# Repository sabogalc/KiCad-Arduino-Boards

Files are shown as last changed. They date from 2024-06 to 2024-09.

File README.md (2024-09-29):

# KiCad Arduino Boards

## Introduction
This repository contains KiCad version 8 design files for eight different Arduino boards that have been recreated from scratch. I was first inspired to work on this project when I received an Arduino Uno R3 for a class project (which you can read [here](https://github.com/sabogalc/KiCad-Arduino-Boards/blob/main/Remote%20Temperature%20Monitoring%20Project.pdf)). Although I had never used an Arduino before, I found it quite useful and versatile. However, I wanted to make some changes to better suit my needs.

## Project Motivation
While working with the Arduino Uno R3, I was frustrated by the need for a USB-B printer cable to use it. Since the Arduino hardware is open source, I decided to recreate the board with a USB-C connector. Additionally, I learned that Arduino boards are not made in KiCad, so I figured this project could also have another benefit in making the designs more open and accessible. Although buying an R4 Minima that already comes with USB-C would have been easier and less expensive, I enjoyed the challenge of re-designing the board myself.

## Design Process
Every Adruino board I could find is made in either EAGLE or Altium, and KiCad has importers for both of these formats. However, importing designs always comes with a level of artifacting and other inaccuracies. The effort to correct the imports would be comparable to remaking the board from scratch, so I opted for the latter since it would produce a cleaner end result. 

Given the popularity and open-source nature of Arduino boards, I assumed that partial or complete KiCad versions might already exist. The following repositories were helpful for getting started:
- [Arduino Uno R3 From Scratch](https://github.com/rheingoldheavy/arduino_uno_r3_from_scratch): Schematic and BOM
- [Arduino Uno KiCad Template](https://github.com/Jeff-Russ/Arduino_Uno_Template): Bare board layout
- [Arduino UNO R3 BOM](https://gist.github.com/yahyatawil/ee6ad731bcf5a5b37dcf2cac04245fbe): BOM only

Even with these resources, I had to find a reset switch footprint myself, but eventually I landed on a compatible one with the TS06-667-30-BK-100-G-SMT-TR by CUI Devices. I now had every piece I needed to make a schematic and PCB, and while doing the PCB layout I would consistently reference the imported design and try to make the component placement and routing as close to the original as possible.

## Visual Comparison
Below is a comparison of the imported UNO R3 board and my completed board, highlighting the differences and benefits in re-making the board from scratch. The most apparent differences are in the silkscreen labeling and the included 3D models of the components:

Comparison Image

## Boards Included
This repository includes designs for:
- Arduino Uno R3
- Arduino Uno R3 SMD
- Arduino Uno R4 Minima
- Arduino Uno R4 WiFi (this one may have some issues; see its folder for details)
- Arduino Leonardo
- Arduino Micro
- Arduino Nano
- Arduino Mega 2560

For details about each board, refer to the `README` file in their respective folders.

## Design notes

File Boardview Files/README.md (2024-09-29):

# Boardview Files

## What is a Boardview File?

A boardview file is a netlist of all the connections on a PCB with every component laid out exactly as it is in real life. This modern approach provides a more intuitive way to inspect connections and troubleshoot PCBs compared to traditional schematic diagrams.

## How Can I View These Files?

Much like how there are many PCB EDA software programs out there, there are also many board viewing programs. The two that I have used and recommend are listed below:

1. **[OpenBoardView](https://github.com/OpenBoardView/OpenBoardView)**  
   - **License:** MIT  
   - **Description:** An open-source tool for viewing boardview files. It provides essential features for inspecting PCB layouts.

2. **[FlexBV](https://pldaniels.com/flexbv/)**  
   - **License:** Commercial (free version available)  
   - **Description:** A commercial tool with advanced features for viewing and analyzing boardview files. The free version offers most of the basic functionalities.

### Example View

Below is a screenshot of the Arduino Mega 2560 boardview as viewed in FlexBV:

Arduino Mega 2560 Boardview

In this view, you can observe the following:
- **Net Highlighting:** The +5V net is highlighted in green across the board.
- **Component Table:** A table on the right lists components and their pin numbers associated with +5V.
- **Designator Information:** The designators, values of resistors and capacitors, and component footprints are all displayed.

### Note on Metadata

The metadata you see (e.g., component values, designators) is stored in the `.obdata` file. As of September 2024, this metadata is viewable only in FlexBV. The `.obdata` format is [open and documented](https://openboarddata.org/), and I would very much like to see the feature added to OpenBoardView.

### How Can I Create Boardview Files for My Own Designs?

All of the boardview files I make for my projects are using [an open-source KiCad plugin](https://github.com/whitequark/kicad-boardview). When I first came across this plugin, it had a few bugs with current versions of KiCad, so I submitted some pull requests and the plugin is back into perfect operating condition. The `.obdata` generation script is currently internal since I made a bit of a mess [submitting that PR](https://github.com/whitequark/kicad-boardview/pull/16), but I am looking to release it eventually.

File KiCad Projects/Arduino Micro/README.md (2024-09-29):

# Micro
Much like the Nano, I made this board in one or two sittings.

This board is not much bigger than the Nano, but it brings benefits such as the full-sized reset switch and four more IO pins.

## KiCad 3D View
Below are the screenshots of this board from KiCad's 3D board viewer.

3D View Front
3D View Back

## Real-World Application
Additionally, I have successfully built this board in real life and confirmed that it works.
Built Board

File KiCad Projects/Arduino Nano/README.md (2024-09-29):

# Nano

## Overview
The Nano is a compact and versatile board that surprisingly handles many of my existing projects designed for the UNO. Its small size makes it a great choice for projects where space is at a premium.

## Design Insights
This was the first board in this repository where I had to use a fully surface-mount USB-C connector instead of a through-hole variant. The original Nano also utilizes a surface-mount USB connector, as a through-hole option would interfere with routing and placement on the bottom layer.

While integrating the larger footprint of the USB-C connector, I had to adjust the silkscreen labels near the connector, but I ensured that all the necessary information remained clear and accessible.

## KiCad 3D View
Below are the screenshots of this board from KiCad's 3D board viewer.

3D View Front
3D View Back

## Real-World Application
Additionally, I have successfully built this board in real life and confirmed that it works.
Built Board

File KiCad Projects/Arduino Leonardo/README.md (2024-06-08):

# Leonardo
This board is very physically similar to the UNO, so it was relatively easy for me to work with the design. I like the versatility it offers with two footprints for the ATMEGA32U4.

The HID automation that this board offers would likely be very useful in setups such as setting up many school or work computers with identical settings, though I'm not sure if my version of the design retained this functionality. I'm used to needing a configuration channel logic IC when working with USB-C host/sub switching, but if anyone who knows more about this has any feedback, please let me know.

Below are the screenshots of this board from KiCad's 3D board viewer.




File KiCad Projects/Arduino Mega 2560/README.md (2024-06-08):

# Mega 2560
I was expecting this to be the most difficult board to make, but it really wasn't all that bad. It did take the longest, but I broke up the design into small sessions across multiple days.

I don't currently have any projects that require the whopping 54 GPIO pins that this board offers, but I saw that it was commonly used in the robotics and 3D printing spaces, and I've also seen it used to read EEPROM data on Ben Eater's YouTube channel.

Below are the screenshots of this board from KiCad's 3D board viewer.




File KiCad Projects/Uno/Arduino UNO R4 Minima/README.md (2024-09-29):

# UNO R4 Minima

## Overview
This board was very straightforward to make, and it is almost 1:1 with the factory one. Even though the UNO R4 already comes with USB-C from Arduino, the OEM footprint is one that exposes the middle plastic receptacle a bit, so I replaced it with one that has the entire port enclosed.

## Design Considerations
While working on this board, I encountered a few challenges:

- **Silkscreen Squares:** The silkscreen square etches on the left side were a bit cumbersome to design.
- **Microcontroller Routing:** Routing beneath the R7FA4M1AB3CFM#AA0 microcontroller was also relatively intricate, as seen below.

R7FA4M1AB3CFM#AA0 Routing

## KiCad 3D View
Below are the screenshots of this board from KiCad's 3D board viewer.
3D View Front
3D View Back

## Real-World Application
I have successfully built this board and confirmed that it works.

Built Board

### Important Note on Soldering
During assembly, I had to solder the buck regulator on 3 separate times since I kept blowing it up. As seen in the [ISL854102 datasheet](https://www.renesas.com/en/document/dst/isl854102-datasheet), its pin configuration is as follows:

- Pin 4: V<sub>in</sub>
- Pin 5: V<sub>out</sub>
- Pin 6: GND

Buck Regulator Pinout

Naturally, shorting any one of these pins to the other can cause a detrimental short, and the 0.5mm pitch makes it easy to do so. Please be careful when soldering the buck regulator!

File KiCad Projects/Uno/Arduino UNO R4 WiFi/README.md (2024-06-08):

# UNO R4 WiFi
I am not the same man I was before making this board.

As soon as I saw the 96 LED array on this board, I knew that I would be in for some work, and of all the boards in this repository, this is the only one that I am not confident would pass a fabricator's specifications. I will highlight the parts of this board that I think may be problematic below.

Firstly, the 3.3V fuse is extremely close to a GND pad on the USB-C port, which could be a possible weak point for a 3.3V short to GND to happen.



Next of course is the placement and routing of the LEDs, especially because lots of these tracks have very little clearance between them.



Some of the curved traces on this board may also be problematic, like in the example below.



All in all, if anyone does actually order the gerbers for this board, please let me know if either all is well or if there are corrections that need to be made.

Below are the screenshots of this board from KiCad's 3D board viewer.




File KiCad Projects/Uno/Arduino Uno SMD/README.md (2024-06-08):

# UNO R3 SMD
This board and its design process are essentially the same as the regular R3.

Below are the screenshots of this board from KiCad's 3D board viewer.




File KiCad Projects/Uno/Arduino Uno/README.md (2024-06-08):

# UNO R3
Because this was the first board I recreated, the design process is already covered in the main `README`. Being that this was the first board I made, it was the one that I was able to get a copy of the earliest, so I have fully verified that this design works, and you can see a photo of the board in real life below.

8e5e6641-f0a8-4247-b638-89c253d5a3a176035296284453338

If you are taking the parts from an OEM UNO like I did, I recommend using low-melt solder to aid in the desoldering of through-hole components. The surface mount components come off easily enough with hot air, but when removing the reset switch or electrolytic capacitors, try to heat them from the bottom of the board to avoid applying too much direct heat.

Below are the screenshots of this board from KiCad's 3D board viewer.




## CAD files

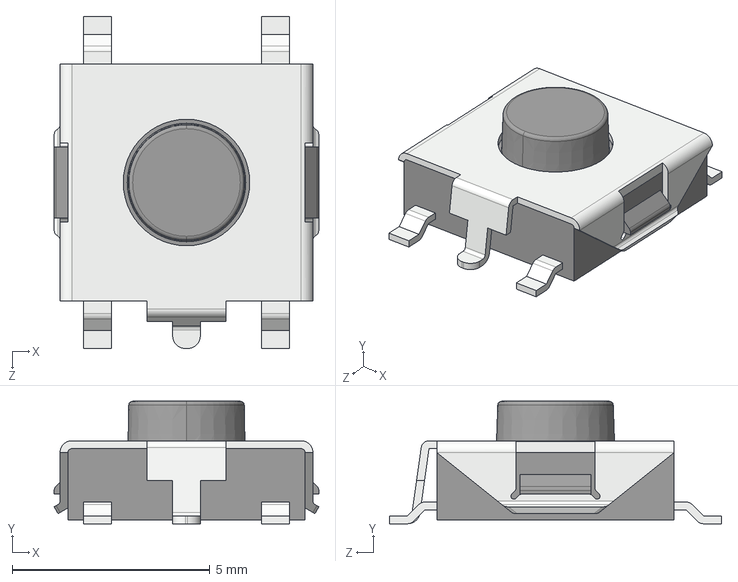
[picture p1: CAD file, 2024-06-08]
KiCad Projects/Arduino Leonardo/STEP Files/CUI_DEVICES_TS06-667-30-BK-100-G-SMT-TR.step
6.70 x 3.10 x 8.40 mm

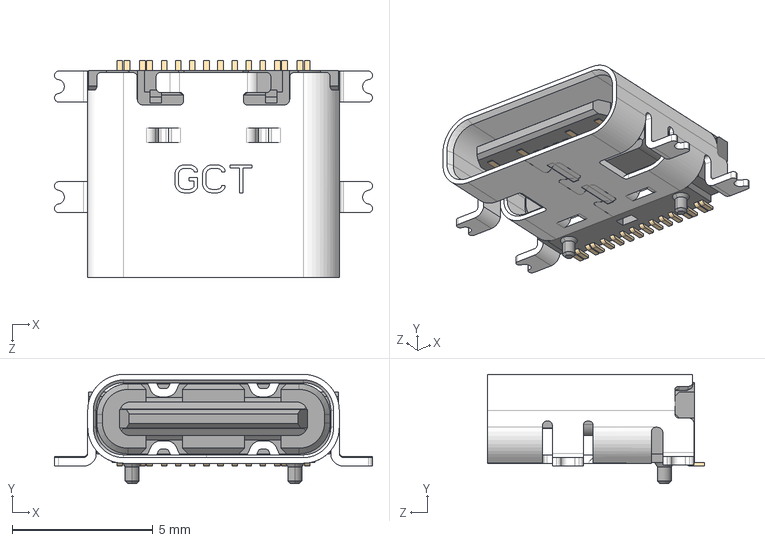
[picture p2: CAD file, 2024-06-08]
KiCad Projects/Arduino Micro/STEP Files/USB4110GFA.step
11.3 x 3.89 x 7.70 mm

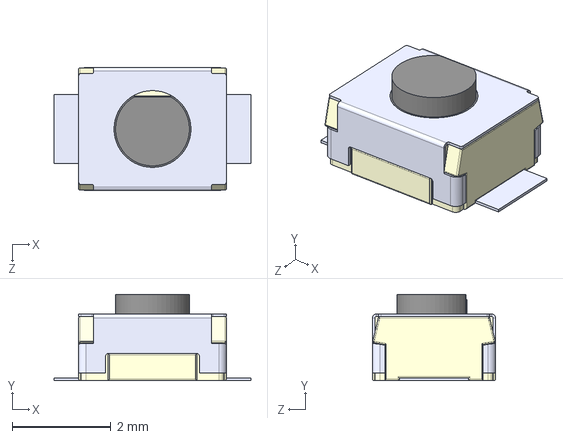
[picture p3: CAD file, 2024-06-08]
KiCad Projects/Arduino Nano/STEP Files/B3U1000PM.step
4.00 x 1.75 x 2.50 mm

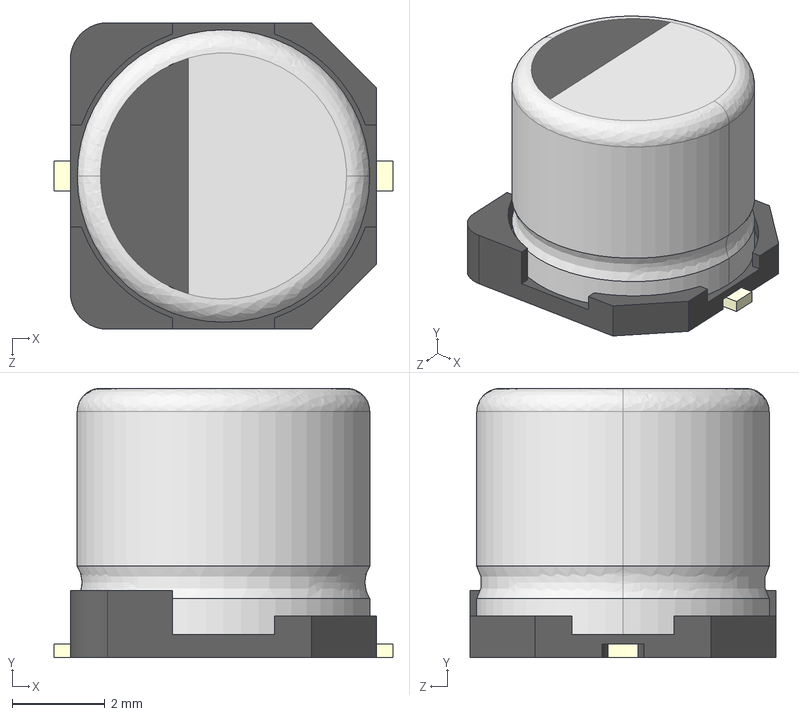
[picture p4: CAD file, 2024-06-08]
KiCad Projects/Uno/Arduino Uno/STEP Files/EEHZA1E470P.step
7.30 x 5.80 x 6.60 mm

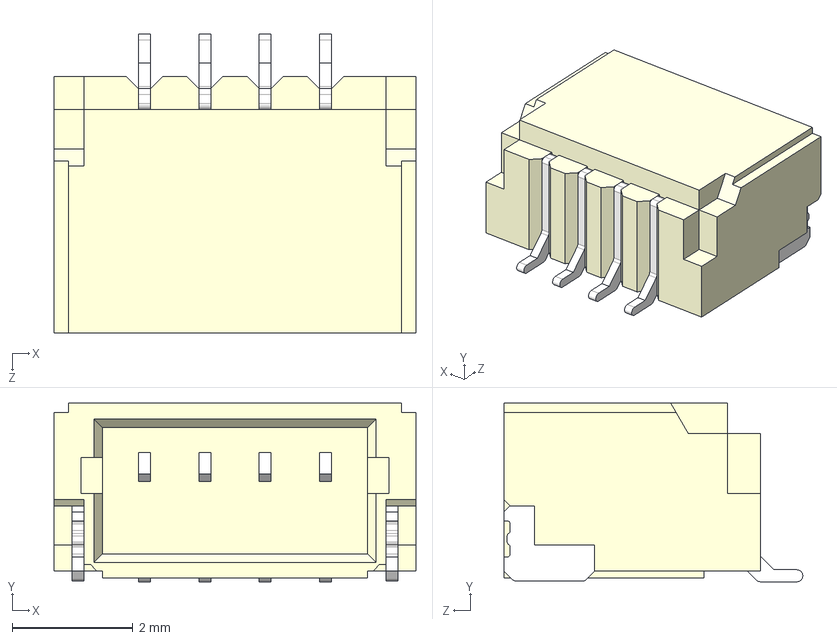
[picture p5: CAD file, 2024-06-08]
KiCad Projects/Uno/Arduino UNO R4 WiFi/STEP Files/SM04B-SRSS-TB.STEP
6.00 x 2.96 x 4.95 mm

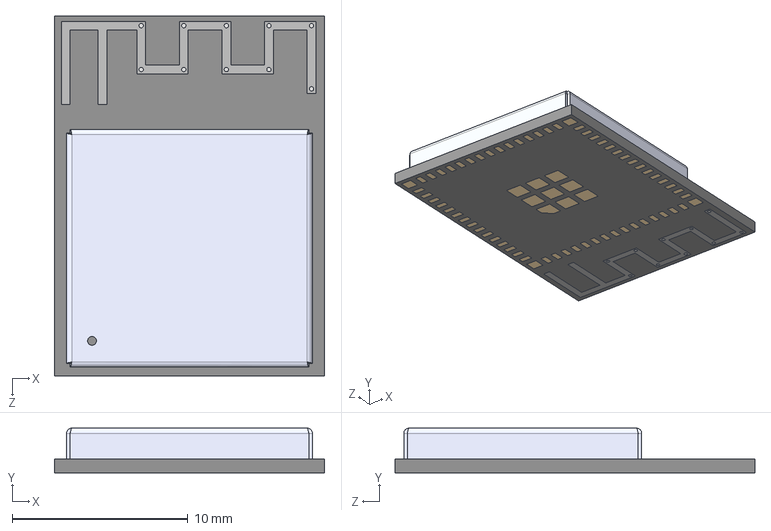
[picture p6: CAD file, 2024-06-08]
KiCad Projects/Uno/Arduino UNO R4 WiFi/STEP Files/ESP32-S3-MINI-1-N8.step
15.4 x 2.55 x 20.5 mm

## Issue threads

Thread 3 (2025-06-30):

USB-B schematic for Arduino Uno

bukowa, 2025-06-30:
Hey is there any source for Uno with  USB-B ?

sabogalc, 2025-07-03:
https://content.arduino.cc/assets/UNO-TH_Rev3e_sch.pdf

Closed 2025-07-03.

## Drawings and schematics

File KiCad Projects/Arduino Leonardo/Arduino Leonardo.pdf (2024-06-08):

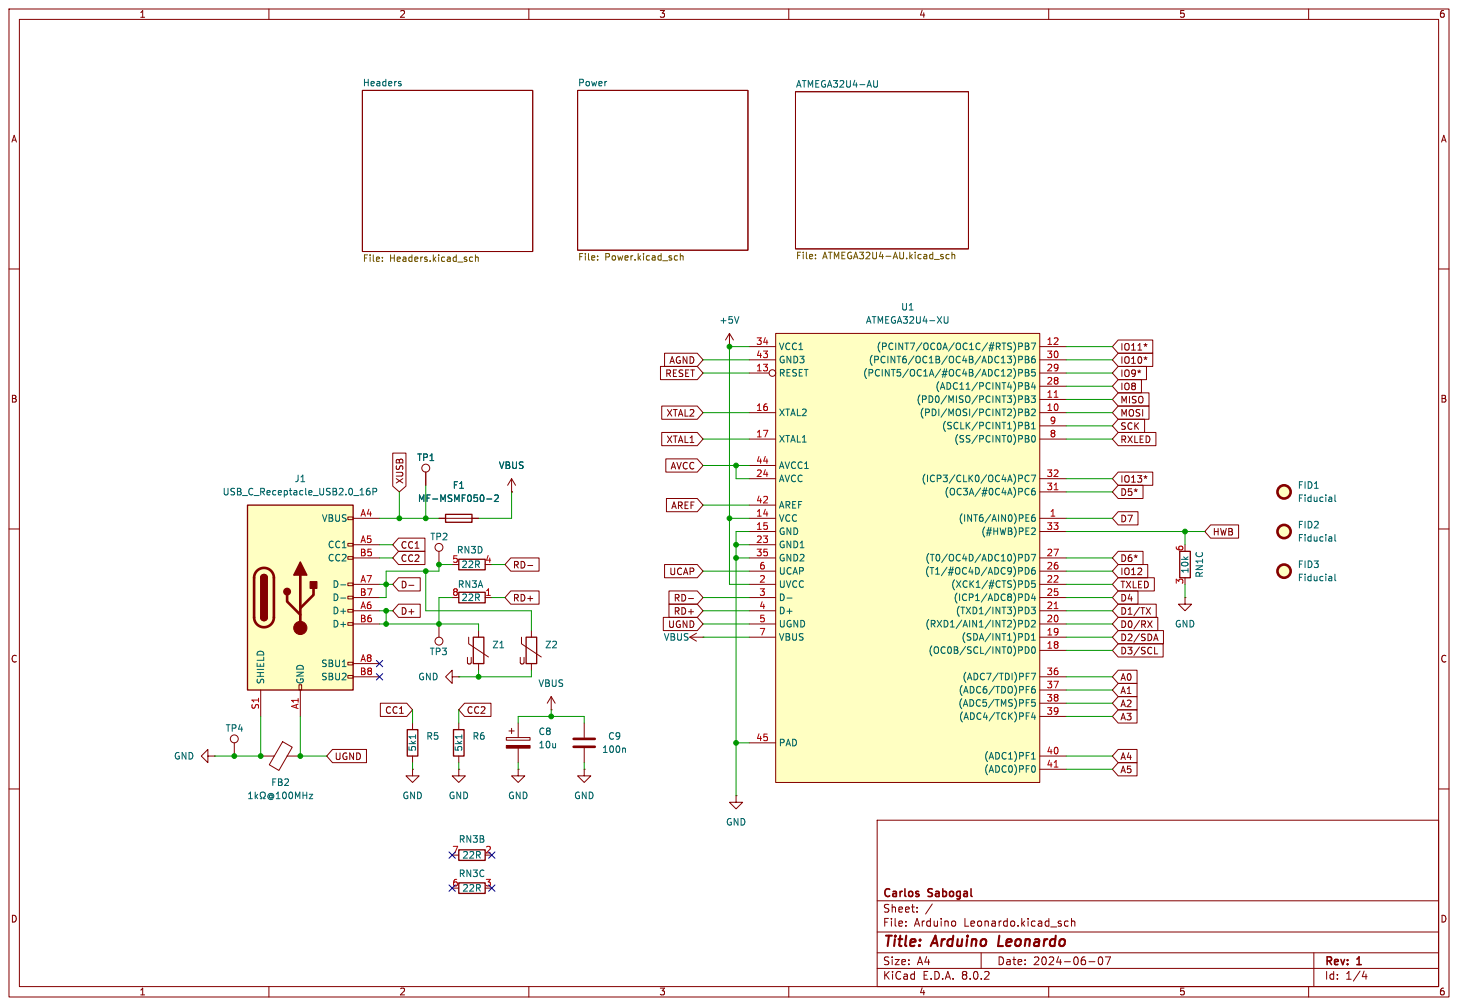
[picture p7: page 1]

D7 D0/RX D2/SDA D3/SCL TXLED

Id: 1/4 Title: Arduino Leonardo

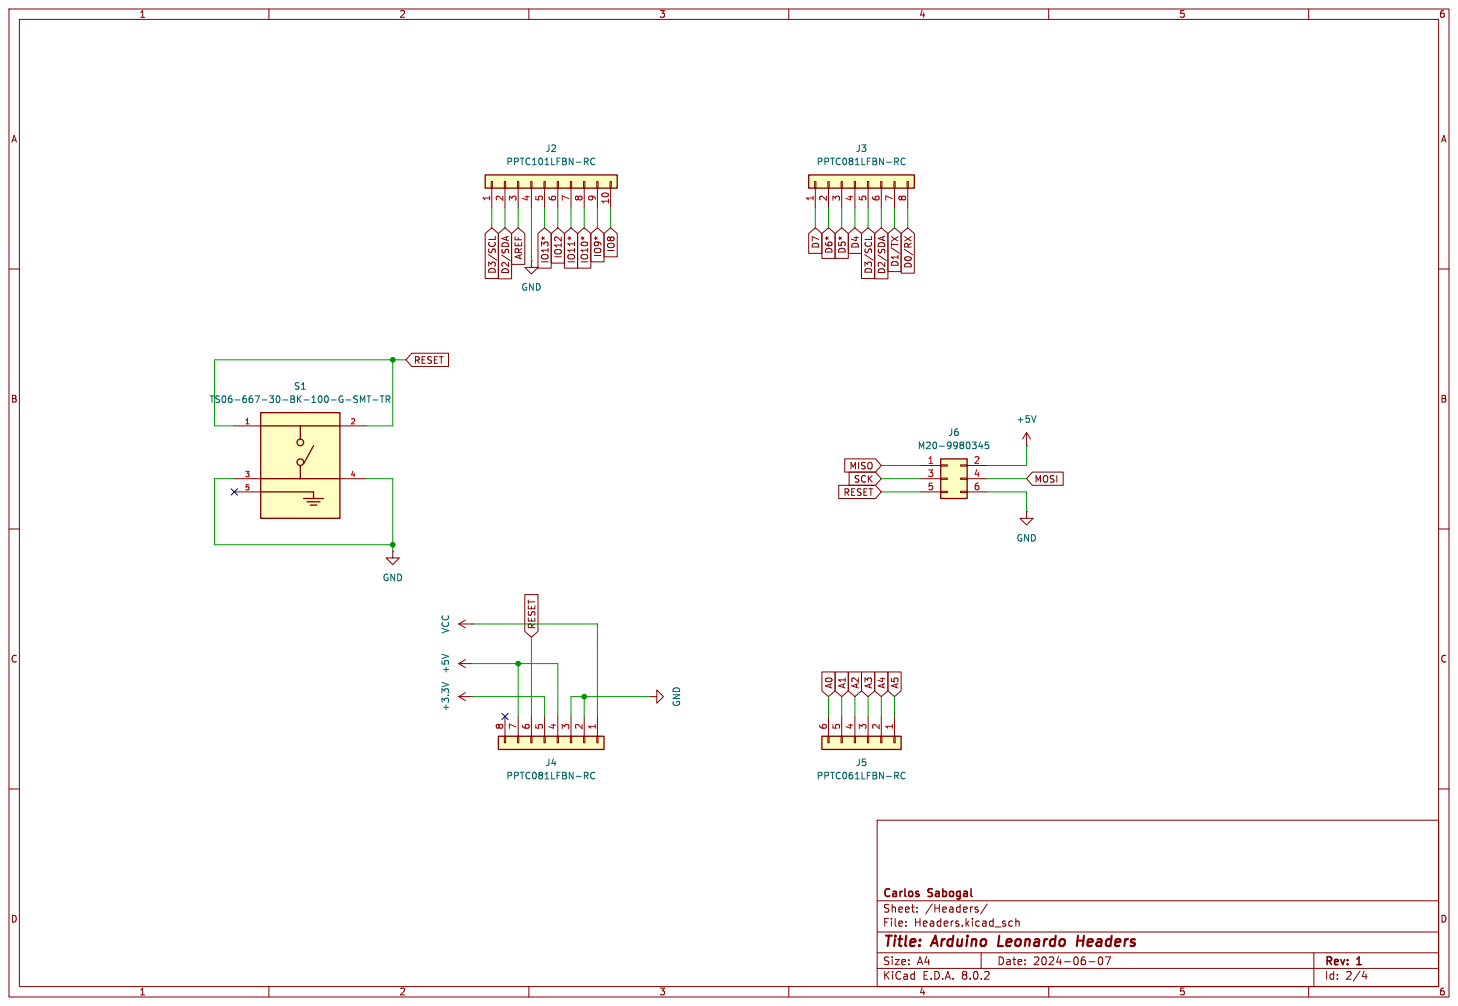
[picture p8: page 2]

File: Headers.kicad_sch Sheet: /Headers/ Carlos Sabogal

Id: 2/4 Title: Arduino Leonardo Headers

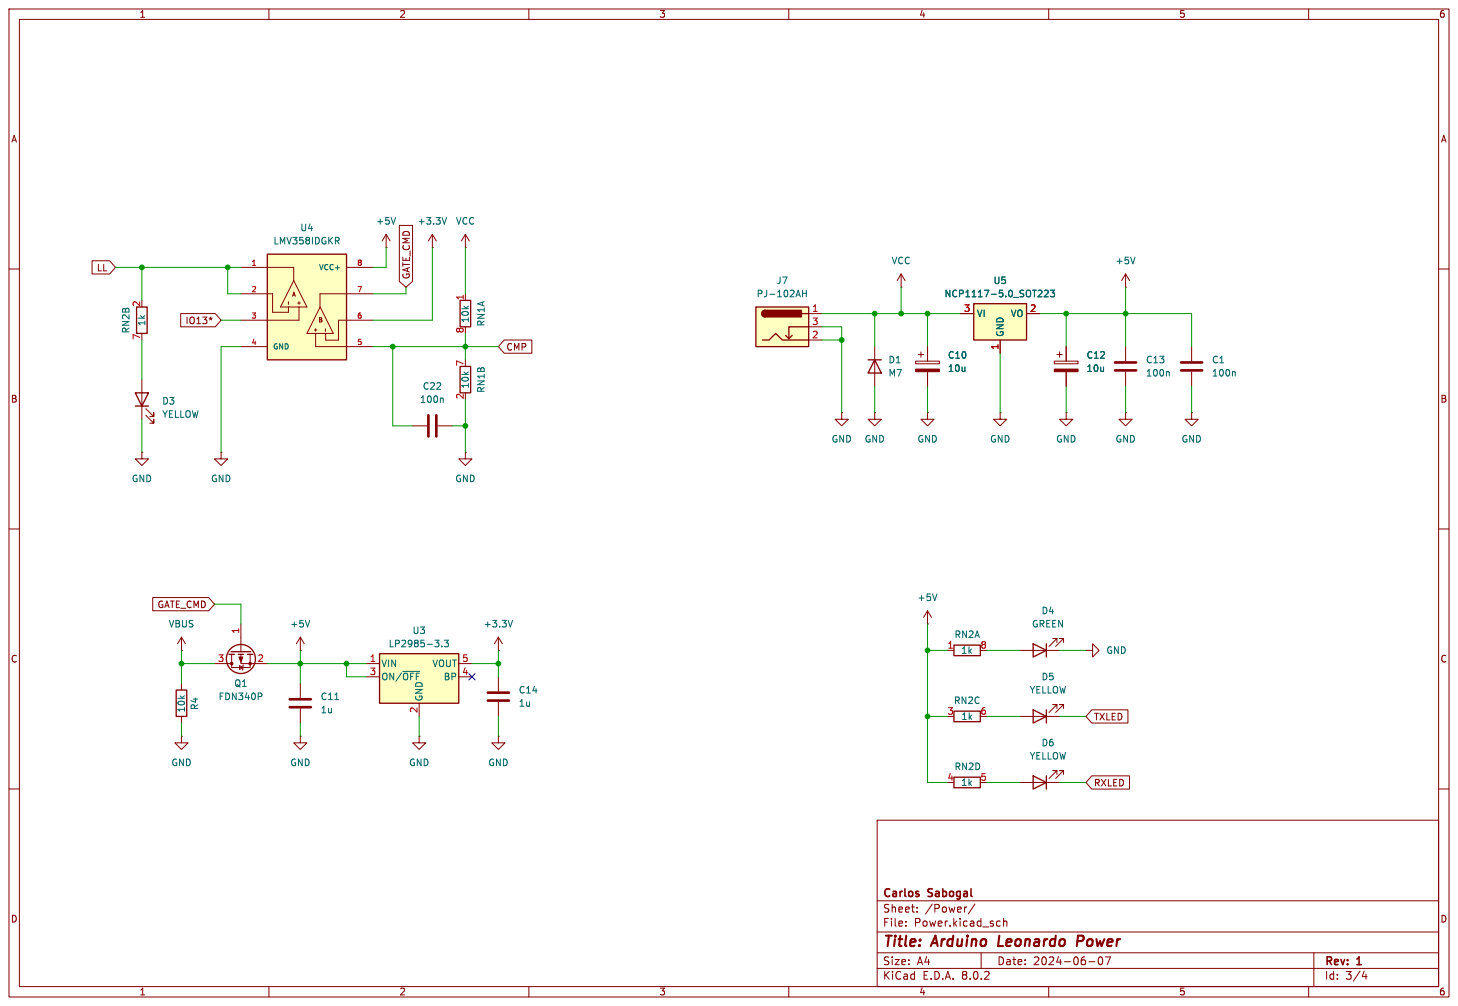
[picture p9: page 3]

2 ON/~{OFF} 3 BP 4 VOUT 5 U3

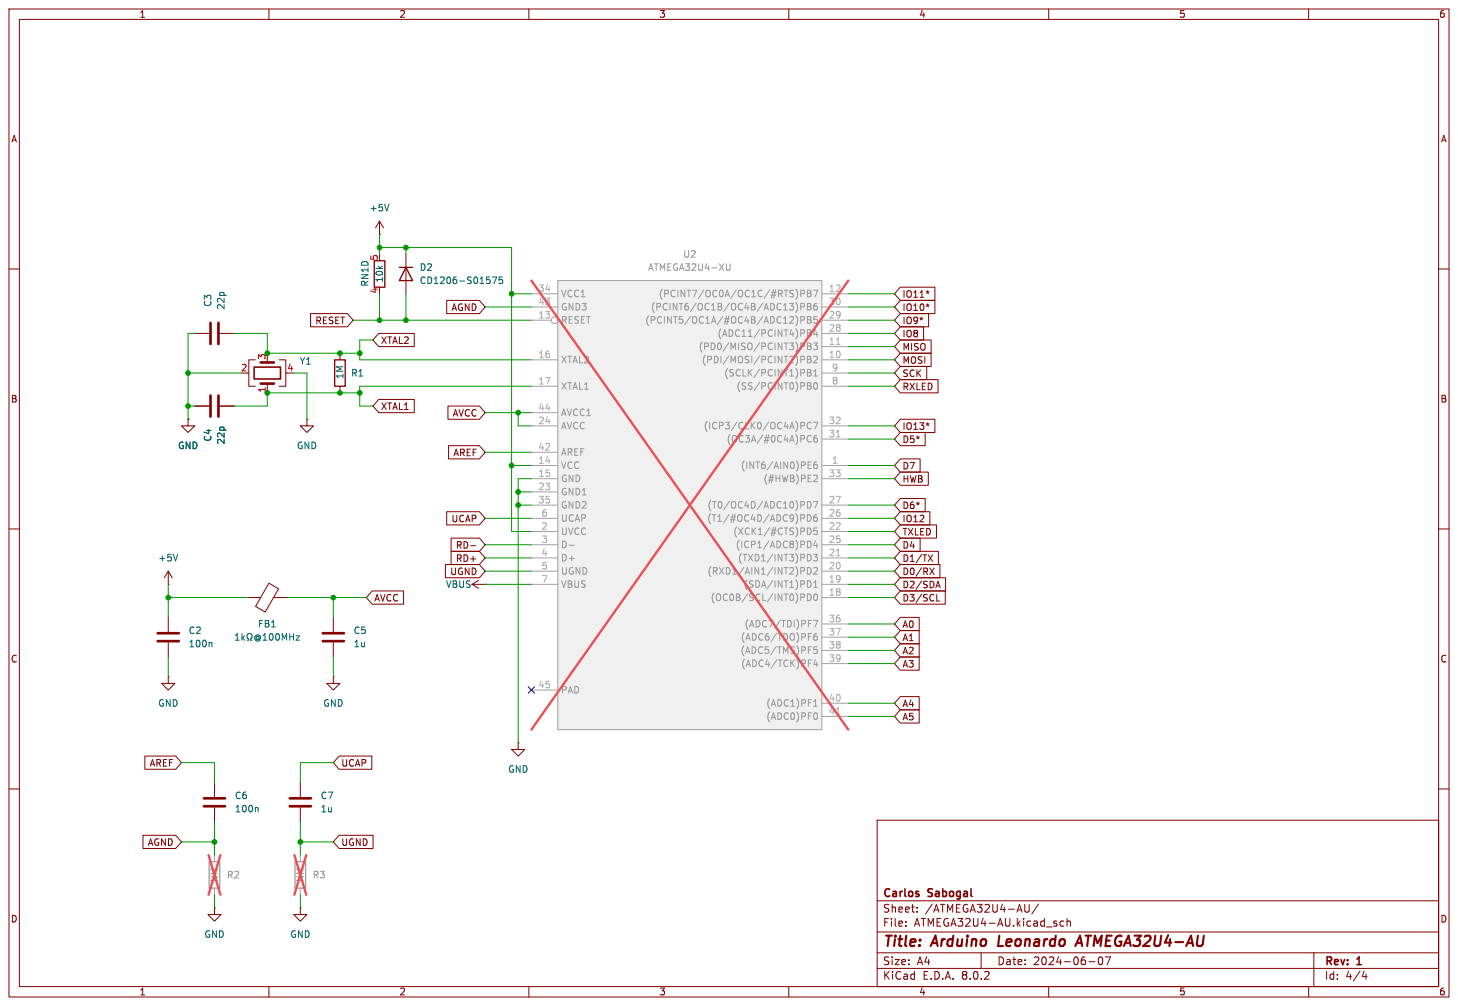
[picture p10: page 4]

File: ATMEGA32U4-AU.kicad_sch Sheet: /ATMEGA32U4-AU/ Carlos Sabogal C2

Id: 4/4 Title: Arduino Leonardo ATMEGA32U4-AU

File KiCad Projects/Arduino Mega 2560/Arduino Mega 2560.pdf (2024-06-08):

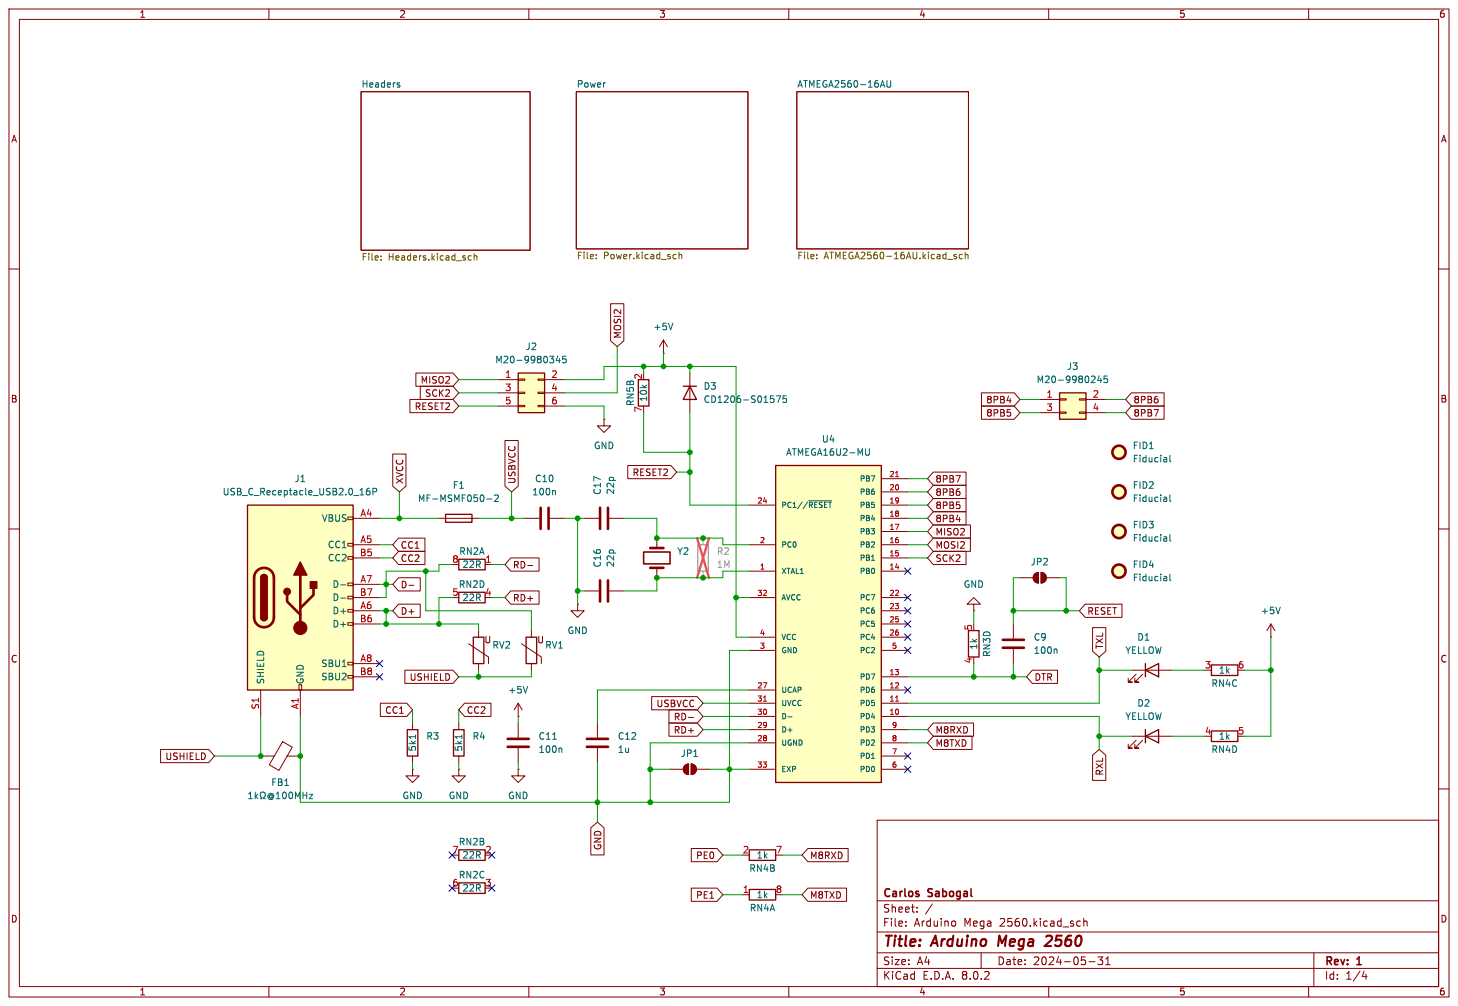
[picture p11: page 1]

Id: 1/4 Title: Arduino Mega 2560

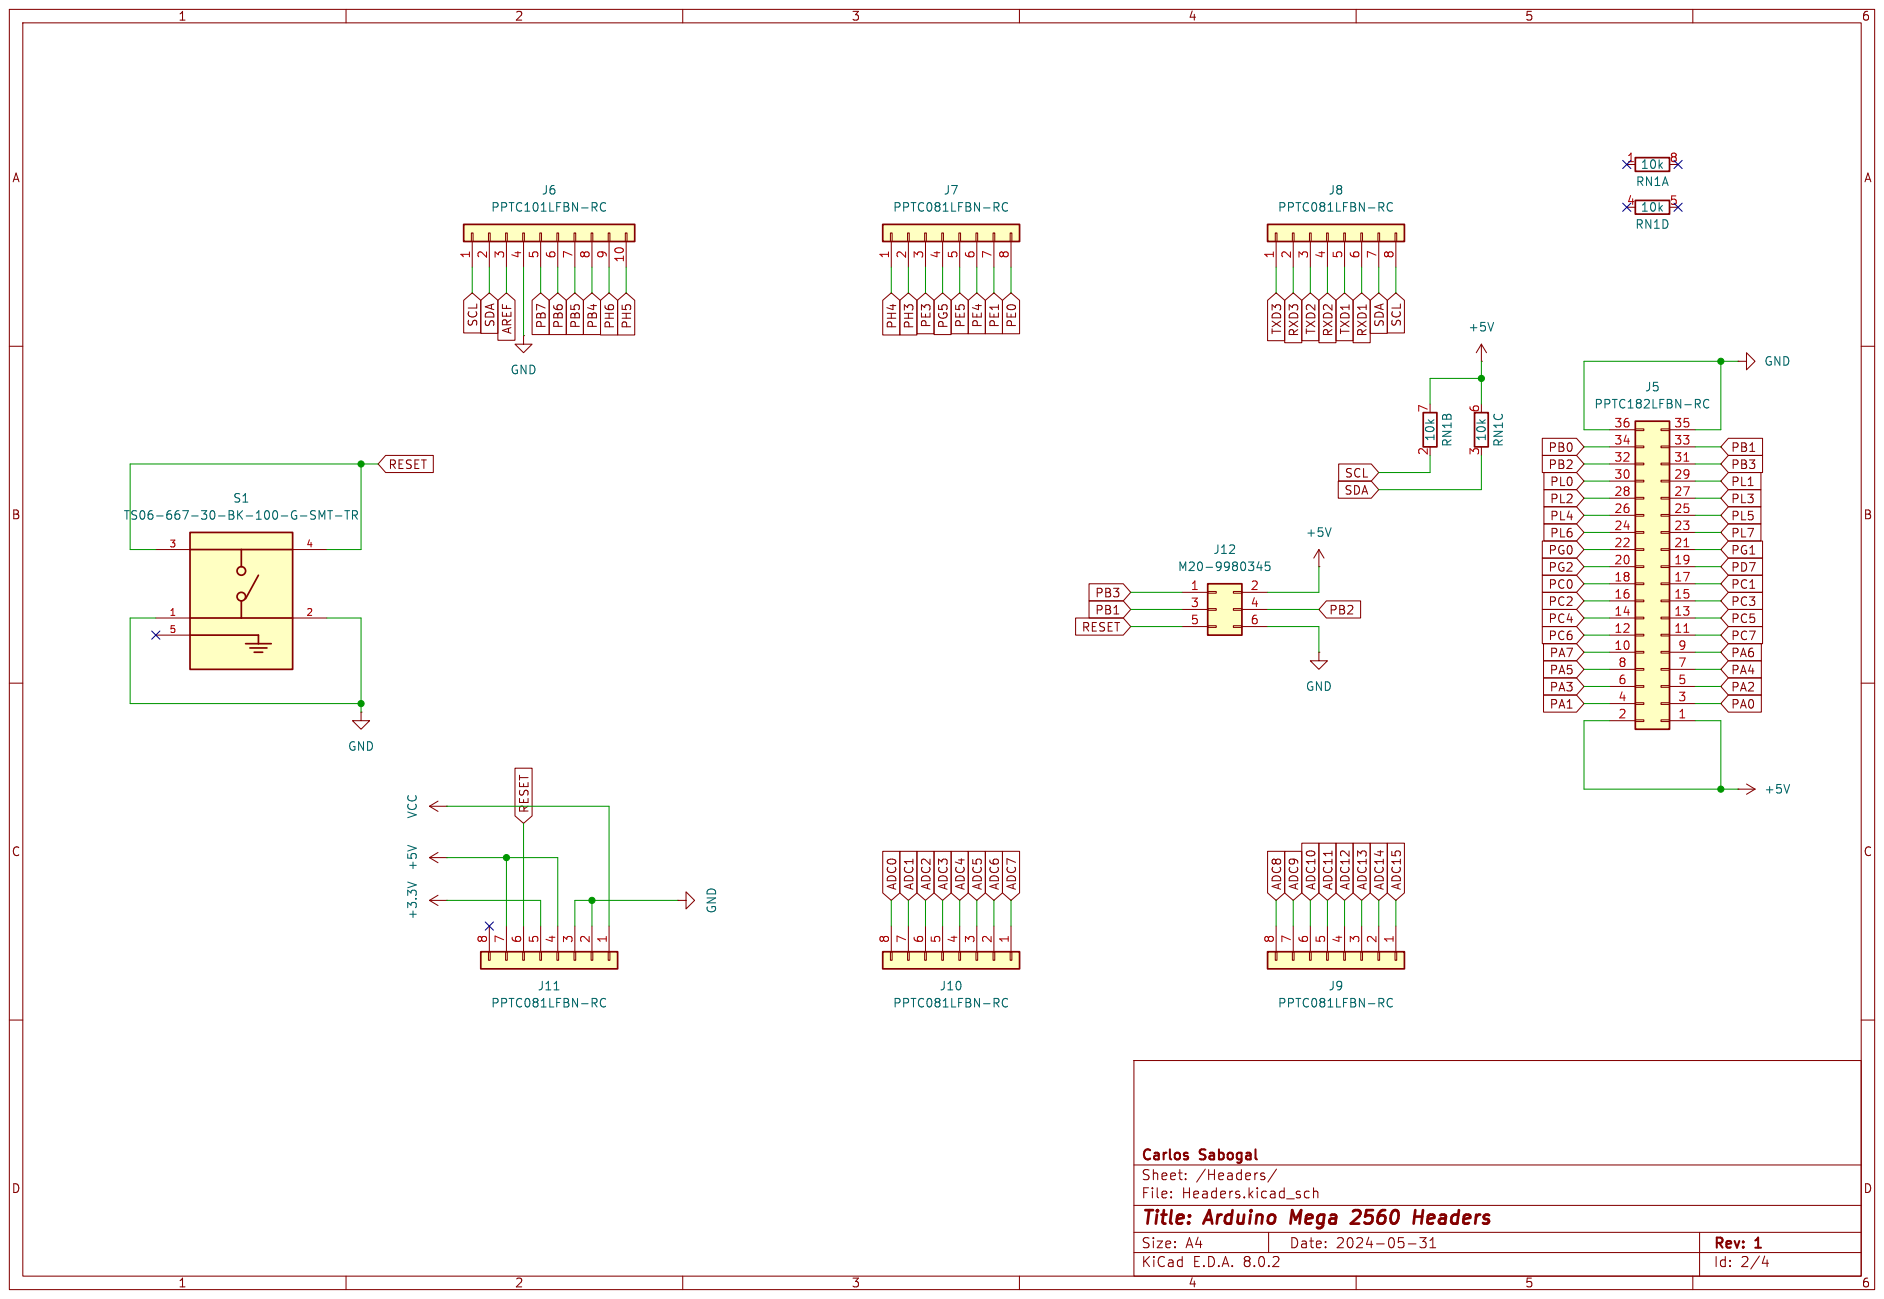
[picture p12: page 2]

File: Headers.kicad_sch Sheet: /Headers/ Carlos Sabogal

Id: 2/4 Title: Arduino Mega 2560 Headers

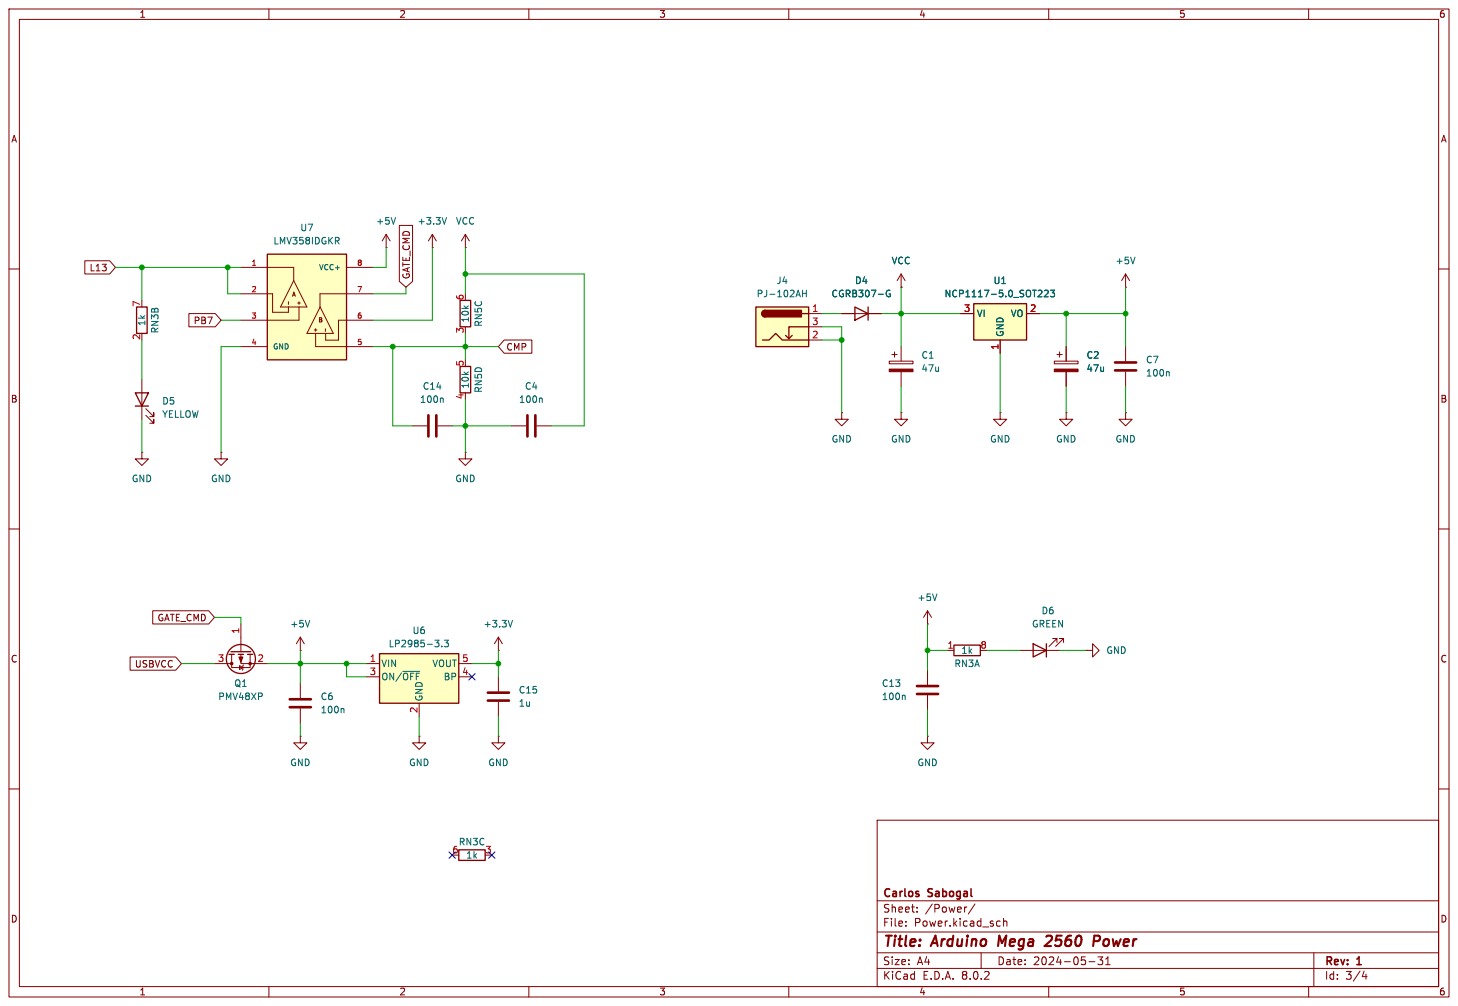
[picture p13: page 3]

1 VO 2 VI 3 U1 NCP1117-5.0_SOT223 GND GND GND GND GND GND

Id: 3/4 Title: Arduino Mega 2560 Power File: Power.kicad_sch Sheet: /Power/ Carlos Sabogal GND

2 ON/~{OFF} 3 BP 4 VOUT 5 U6

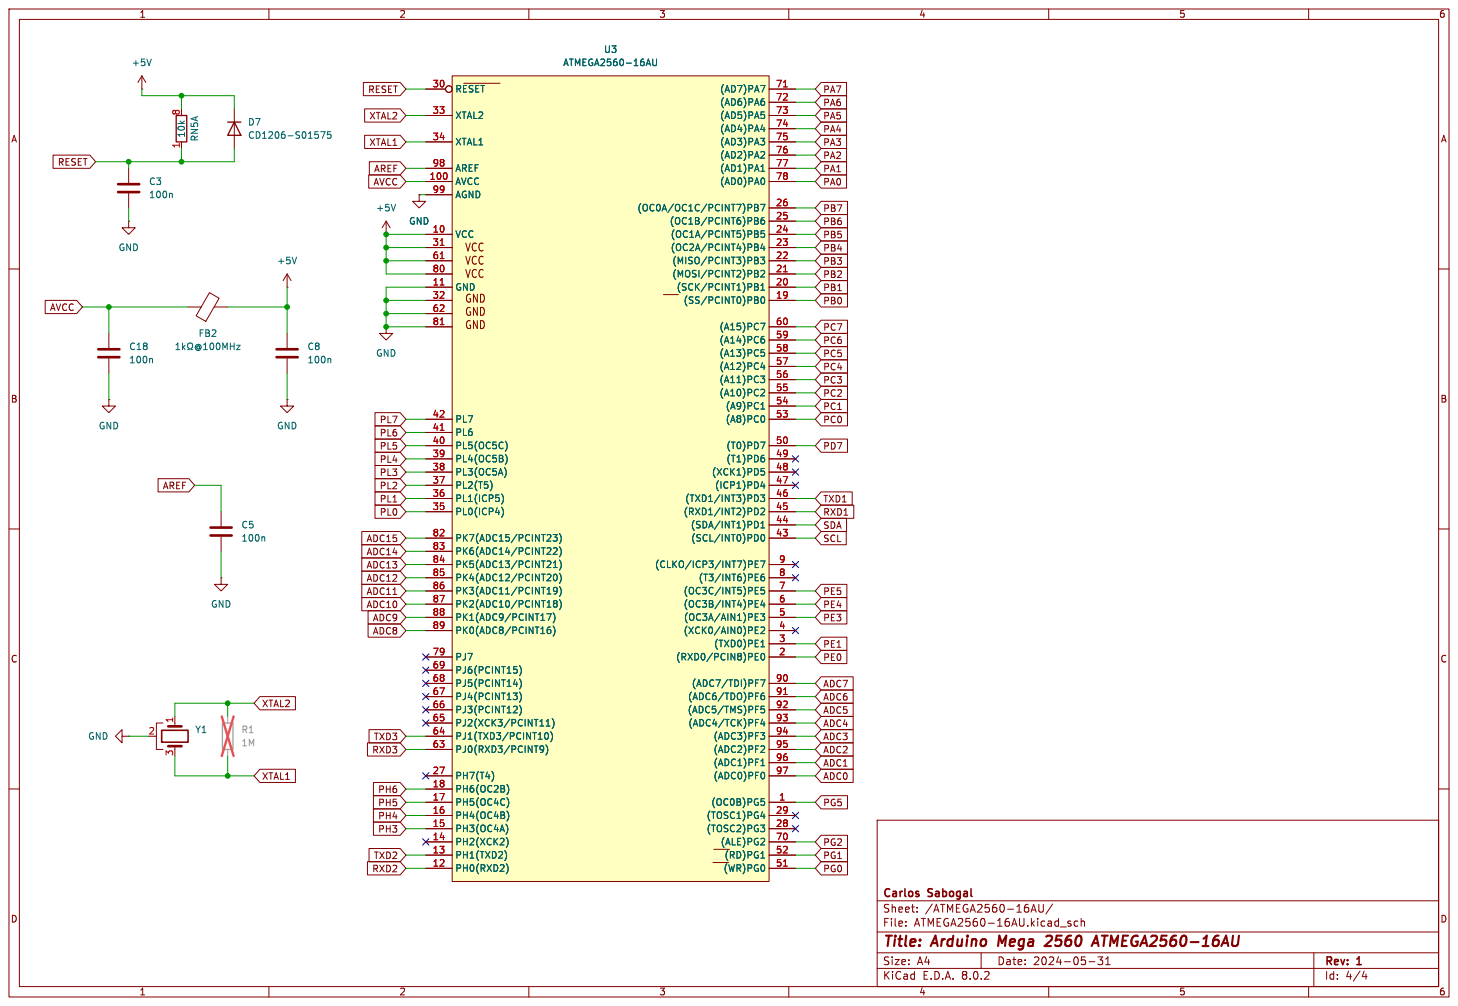
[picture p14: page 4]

File: ATMEGA2560-16AU.kicad_sch Sheet: /ATMEGA2560-16AU/ Carlos Sabogal

Id: 4/4 Title: Arduino Mega 2560 ATMEGA2560-16AU

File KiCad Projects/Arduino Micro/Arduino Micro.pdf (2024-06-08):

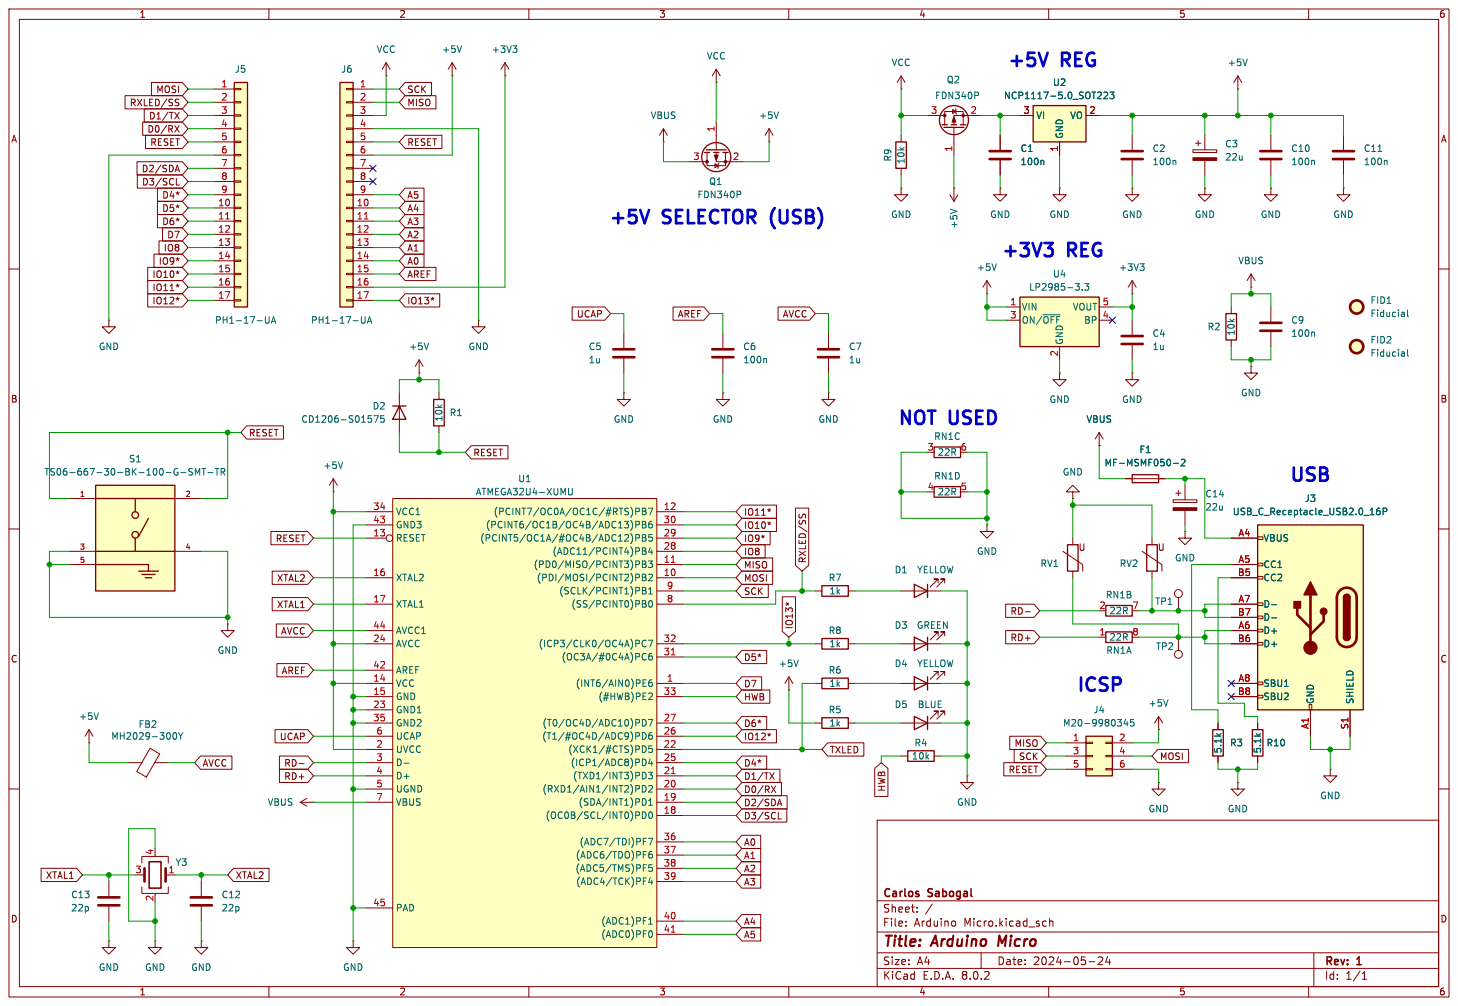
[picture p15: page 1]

2 ON/~{OFF} 3 BP 4 VOUT 5 U4

RESET SCK RD- RD+

IO12* A3A1A5A2A4D6* HWB D3/SCL D2/SDA D0/RX

Id: 1/1 Title: Arduino Micro

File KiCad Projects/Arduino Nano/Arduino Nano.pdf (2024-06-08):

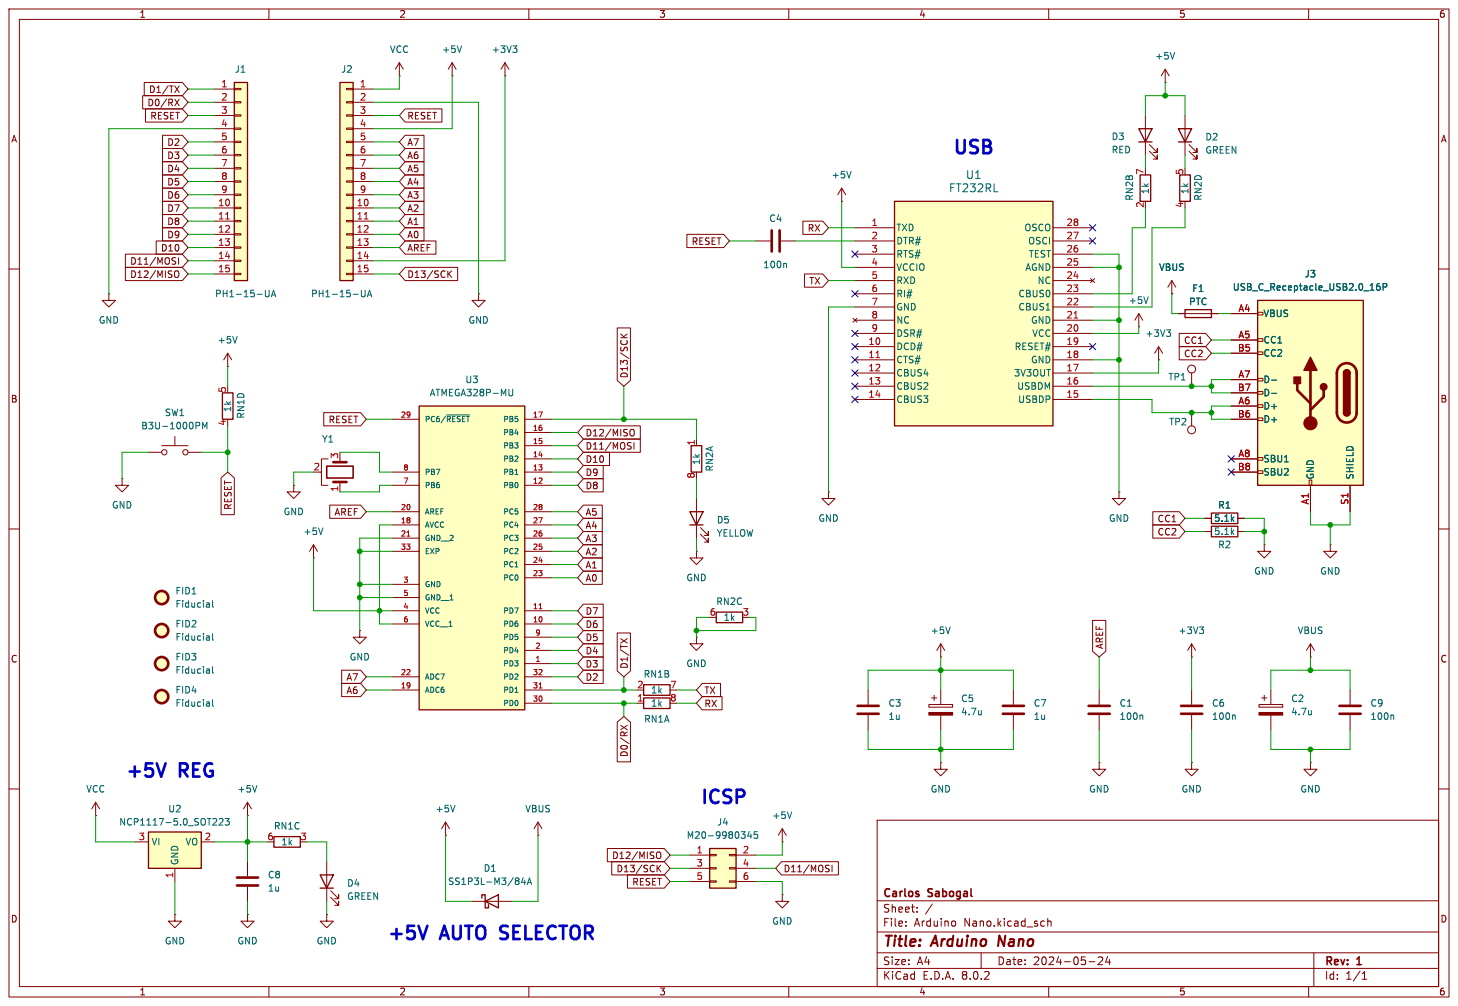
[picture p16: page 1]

Id: 1/1 Title: Arduino Nano

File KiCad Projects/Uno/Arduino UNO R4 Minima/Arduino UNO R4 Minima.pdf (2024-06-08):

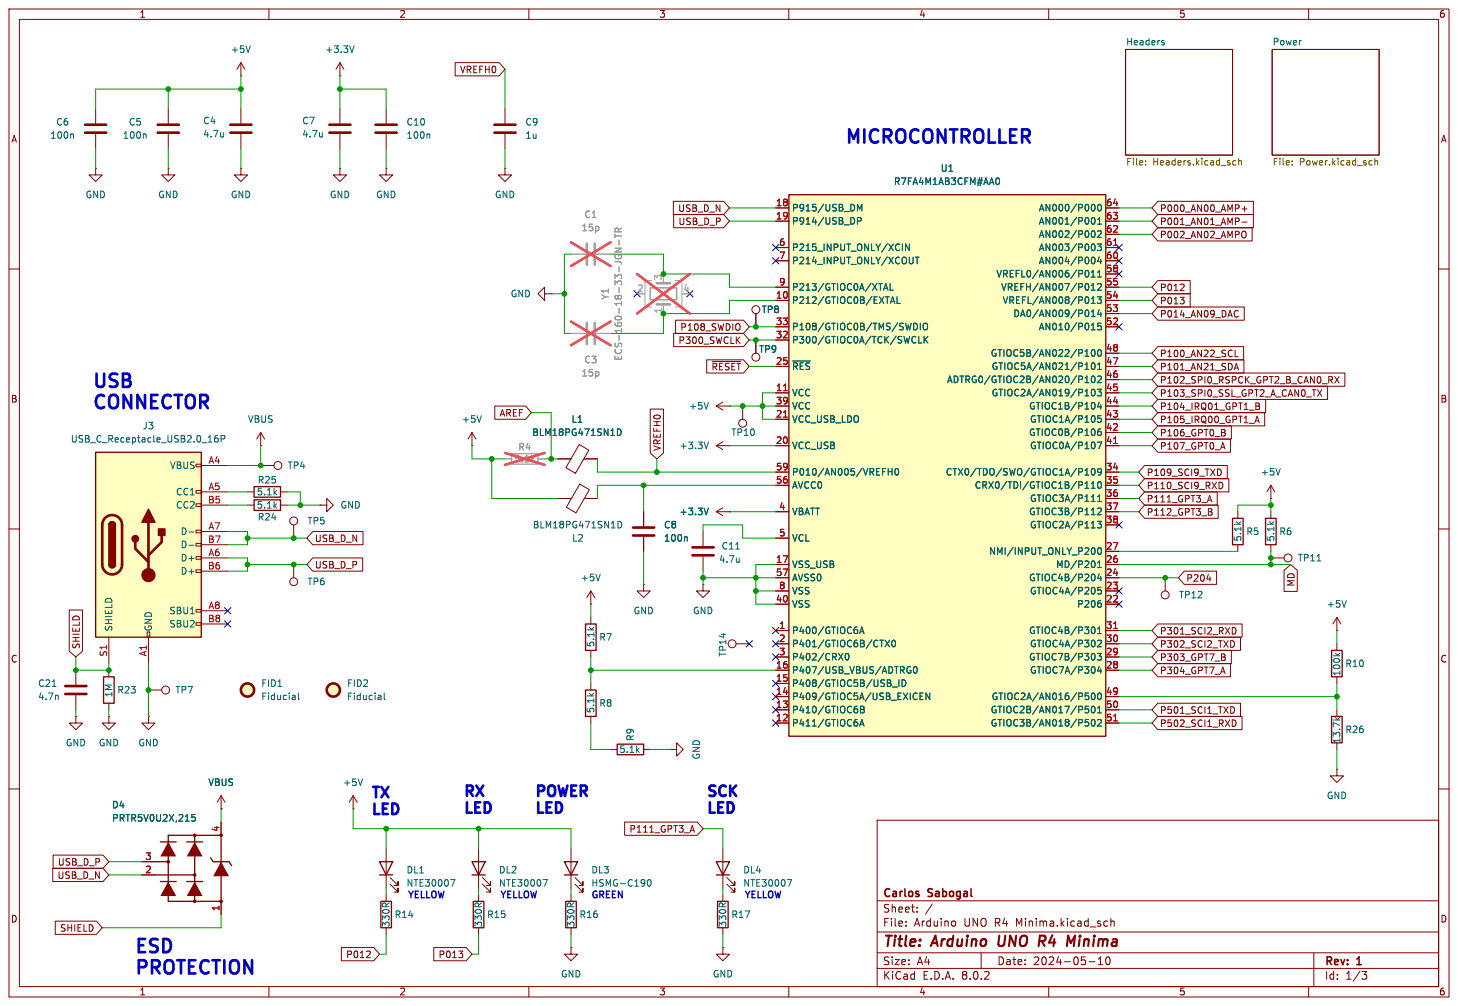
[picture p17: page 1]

Power File: Power.kicad_sch Headers File: Headers.kicad_sch TP12 GND

Id: 1/3 Title: Arduino UNO R4 Minima

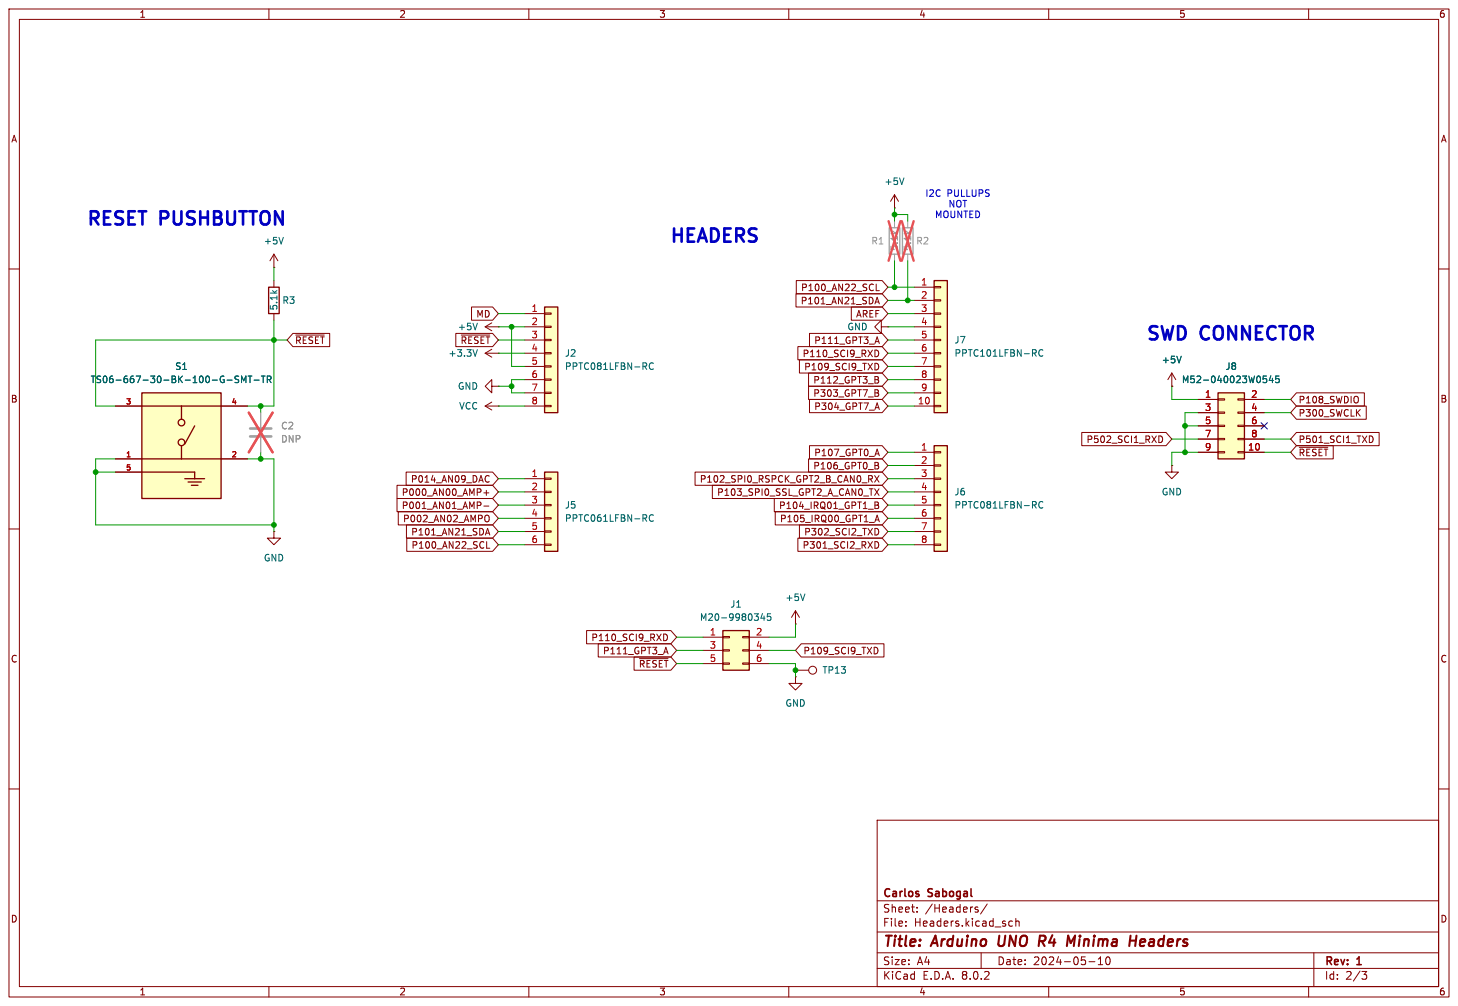
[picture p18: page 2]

I2C PULLUPS NOT MOUNTED HEADERS
P001_AN01_AMP- ~{RESET} MD

File: Headers.kicad_sch Sheet: /Headers/ Carlos Sabogal

Id: 2/3 Title: Arduino UNO R4 Minima Headers


SCHOTTKY FOR USB OVERVOLTAGE

Id: 3/3 Title: Arduino UNO R4 Minima Power File: Power.kicad_sch Sheet: /Power/ Carlos Sabogal

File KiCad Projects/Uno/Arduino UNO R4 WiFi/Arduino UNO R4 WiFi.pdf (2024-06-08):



Id: 2/6 Title: Arduino UNO R4 WiFi Capacitors


File: Headers.kicad_sch Sheet: /Headers/ Carlos Sabogal TP39R11 5.1k +3.3VA

Id: 3/6 Title: Arduino UNO R4 WiFi Headers


Id: 4/6 Title: Arduino UNO R4 WiFi Power File: Power.kicad_sch Sheet: /Power/ Carlos Sabogal


Id: 5/6 Title: Arduino UNO R4 WiFi LED Matrix


(FLOATING) PINSTRAP ROM MESSAGES

PINSTRAP DOWNLOAD
(WEAK PULLUP) PINSTRAP JTAG SOURCE

File: ESP32-S3-MINI-1-N8.kicad_sch Sheet: /ESP32-S3-MINI-1-N8/ Carlos Sabogal

Id: 6/6 Title: Arduino UNO R4 WiFi ESP32-S3-MINI-1-N8

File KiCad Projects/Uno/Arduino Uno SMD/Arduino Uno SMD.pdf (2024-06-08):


Id: 1/4 Title: Arduino Uno SMD (Type-C) File: Arduino Uno SMD.kicad_sch Sheet: / Carlos Sabogal


File: Headers.kicad_sch Sheet: /Headers/ Carlos Sabogal

Id: 2/4 Title: Arduino Uno SMD Headers


Id: 3/4 Title: Arduino Uno SMD Power File: Power.kicad_sch Sheet: /Power/ Carlos Sabogal GND

2 ON/~{OFF} 3 BP 4 VOUT 5 U2


File: ATMEGA328P-MU.kicad_sch Sheet: /ATMEGA328P-MU/ Carlos Sabogal GND GND

Id: 4/4 Title: Arduino Uno SMD ATMEGA328P-MU

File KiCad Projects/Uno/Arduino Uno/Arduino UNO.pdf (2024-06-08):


File: ATMEGA328P-PU.kicad_sch Power File: Power.kicad_sch

Id: 1/4 Title: Arduino UNO (Type-C) File: Arduino UNO.kicad_sch Sheet: / Carlos Sabogal


Id: 2/4 Title: Arduino UNO Headers


1 VO 2 VI 3 U1 NCP1117-5.0_SOT223 GND GND

2 ON/~{OFF} 3 BP 4 VOUT 5 U2

Id: 3/4 Title: Arduino UNO Power File: Power.kicad_sch Sheet: /Power/ Carlos Sabogal


Id: 4/4 Title: Arduino UNO THT ATMEGA328P-PU

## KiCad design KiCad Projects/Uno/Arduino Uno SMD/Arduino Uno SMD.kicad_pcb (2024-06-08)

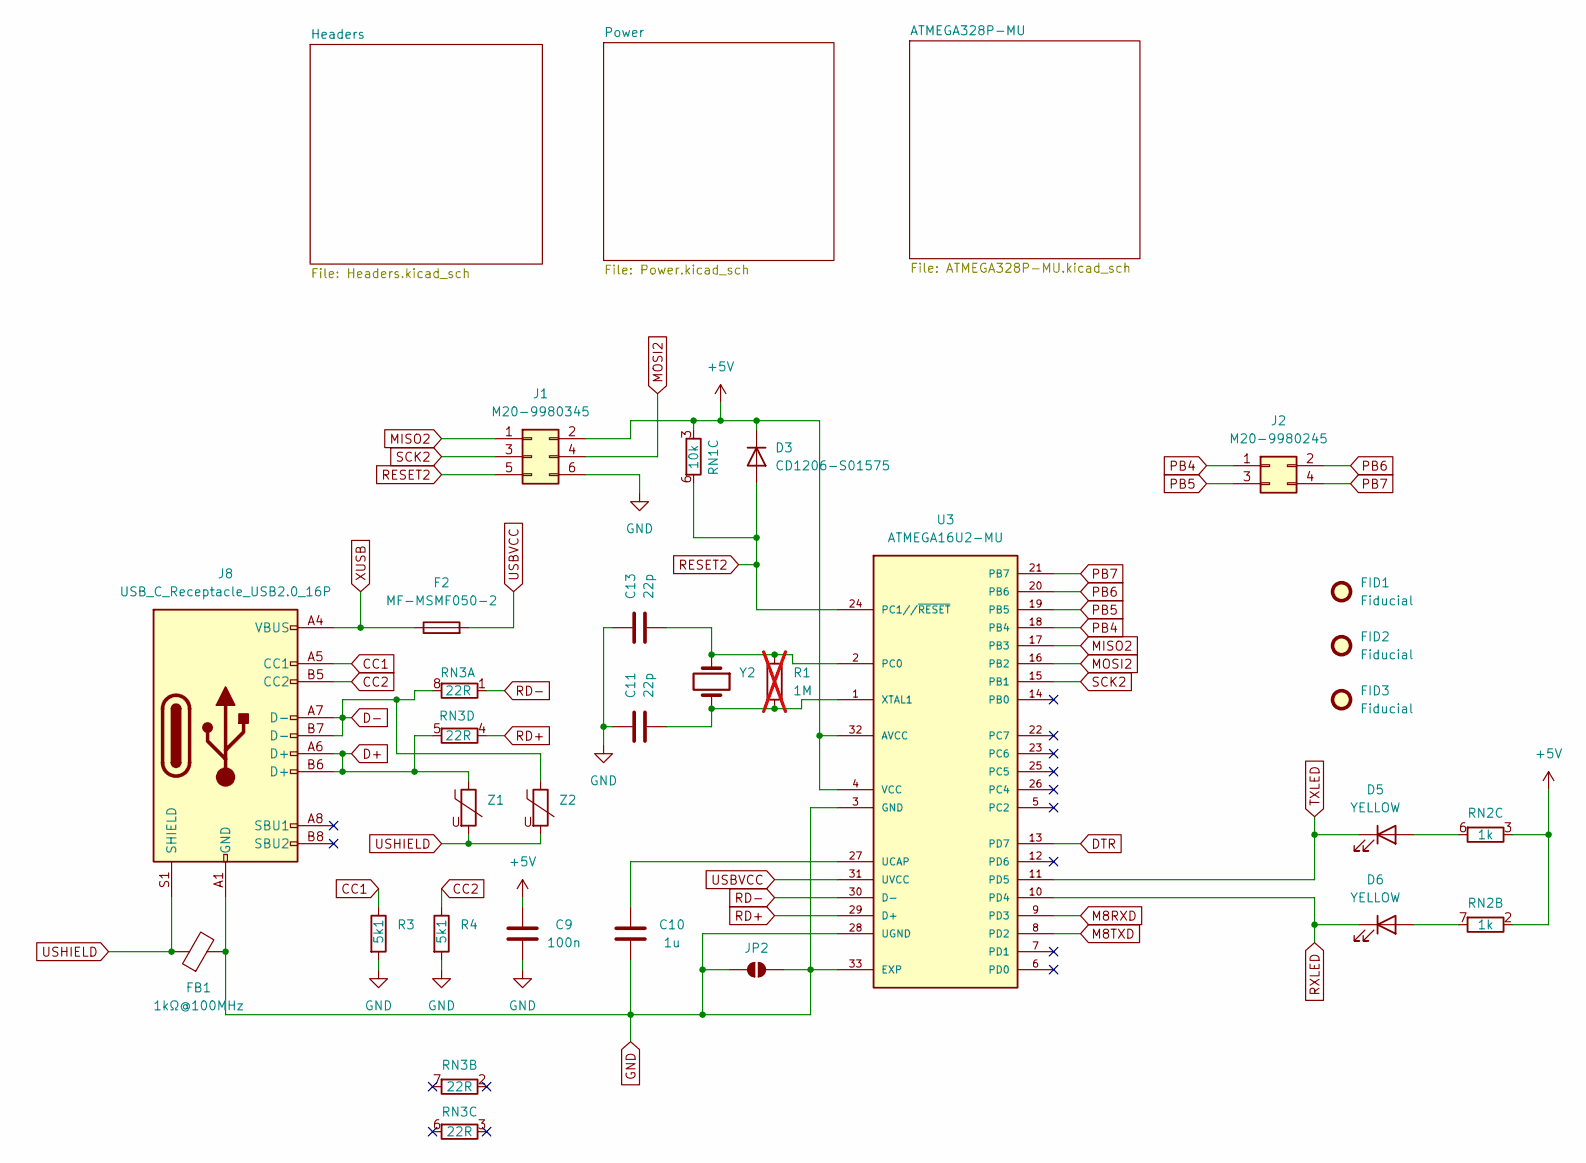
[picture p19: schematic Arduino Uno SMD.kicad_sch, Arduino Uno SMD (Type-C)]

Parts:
C9: 100n; C_0603_1608Metric
C10: 1u; C_0603_1608Metric
C11, C13: 22p; C_0603_1608Metric
D3: CD1206-S01575; D_1206_3216Metric
D5, D6: YELLOW; LED_0805_2012Metric
F2: MF-MSMF050-2; Fuse_1812_4532Metric_Pad1.30x3.40mm_HandSolder
FB1: 1kΩ@100MHz; L_0805_2012Metric
FID1, FID2, FID3: Fiducial; Fiducial_1mm_Mask2mm
J1: M20-9980345; PinHeader_2x03_P2.54mm_Vertical
J2: M20-9980245; CONN_M20-9980245_HRW
J8: USB_C_Receptacle_USB2.0_16P; USB_C_Receptacle_GCT_USB4105-xx-A_16P_TopMnt_Horizontal
JP2: SolderJumper_2_Open; SolderJumper-2_P1.3mm_Open_Pad1.0x1.5mm
R1: 1M; R_0603_1608Metric; not fitted
R3, R4: 5k1; R_0603_1608Metric
RN1: 10k; R_Array_Convex_4x0603
RN2: 1k; R_Array_Convex_4x0603
RN3: 22R; R_Array_Convex_4x0603
U3: ATMEGA16U2-MU; VQFN-32-1EP_5x5mm_P0.5mm_EP3.1x3.1mm
Y2: LFXTAL003240BULK; Crystal_HC49-4H_Vertical
Z1, Z2: 5pF@1MHz; R_0603_1608Metric

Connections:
+5V: C9.1, D3.1 (K), J1.2, RN1.3 (R3.1), RN2.2 (R2.1), RN2.3 (R3.1), U3.4 (VCC), U3.32 (AVCC); also elsewhere on the board
CC1: J8.A5 (CC1), R3.1
CC2: J8.B5 (CC2), R4.1
D+: J8.A6 (D+), J8.B6 (D+), RN3.5 (R4.2), Z1.1
D-: J8.A7 (D-), J8.B7 (D-), RN3.8 (R1.2), Z2.1
DTR: U3.13 (PD7); also elsewhere on the board
GND: C9.2, C10.1, C11.2, C13.2, FB1.2, J1.6, J8.A1 (GND), J8.A12 (GND), J8.B1 (GND), J8.B12 (GND), JP2.1 (A), JP2.2 (B), R3.2, R4.2, U3.3 (GND), U3.28 (UGND), U3.33 (EXP); also elsewhere on the board
M8RXD: U3.9 (PD3); also elsewhere on the board
M8TXD: U3.8 (PD2); also elsewhere on the board
MISO2: J1.1, U3.17 (PB3)
MOSI2: J1.4, U3.16 (PB2)
unnamed: D5.2 (A), RN2.6 (R3.2)
unnamed: D6.2 (A), RN2.7 (R2.2)
unnamed: C13.1, R1.1, U3.2 (PC0), Y2.1
unnamed: C10.2, U3.27 (UCAP)
unnamed: C11.1, R1.2, U3.1 (XTAL1), Y2.2
PB4: J2.1, U3.18 (PB4)
PB5: J2.3, U3.19 (PB5)
PB6: J2.2, U3.20 (PB6)
PB7: J2.4, U3.21 (PB7)
RD+: RN3.4 (R4.1), U3.29 (D+)
RD-: RN3.1 (R1.1), U3.30 (D-)
RESET2: D3.2 (A), J1.5, RN1.6 (R3.2), U3.24 (PC1//~RESET)
RXLED: D6.1 (K), U3.10 (PD4)
SCK2: J1.3, U3.15 (PB1)
TXLED: D5.1 (K), U3.11 (PD5)
USBVCC: F2.2, U3.31 (UVCC); also elsewhere on the board
USHIELD: FB1.1, J8.S1 (SHIELD), Z1.2, Z2.2
XUSB: F2.1, J8.A4 (VBUS), J8.A9 (VBUS), J8.B4 (VBUS), J8.B9 (VBUS)

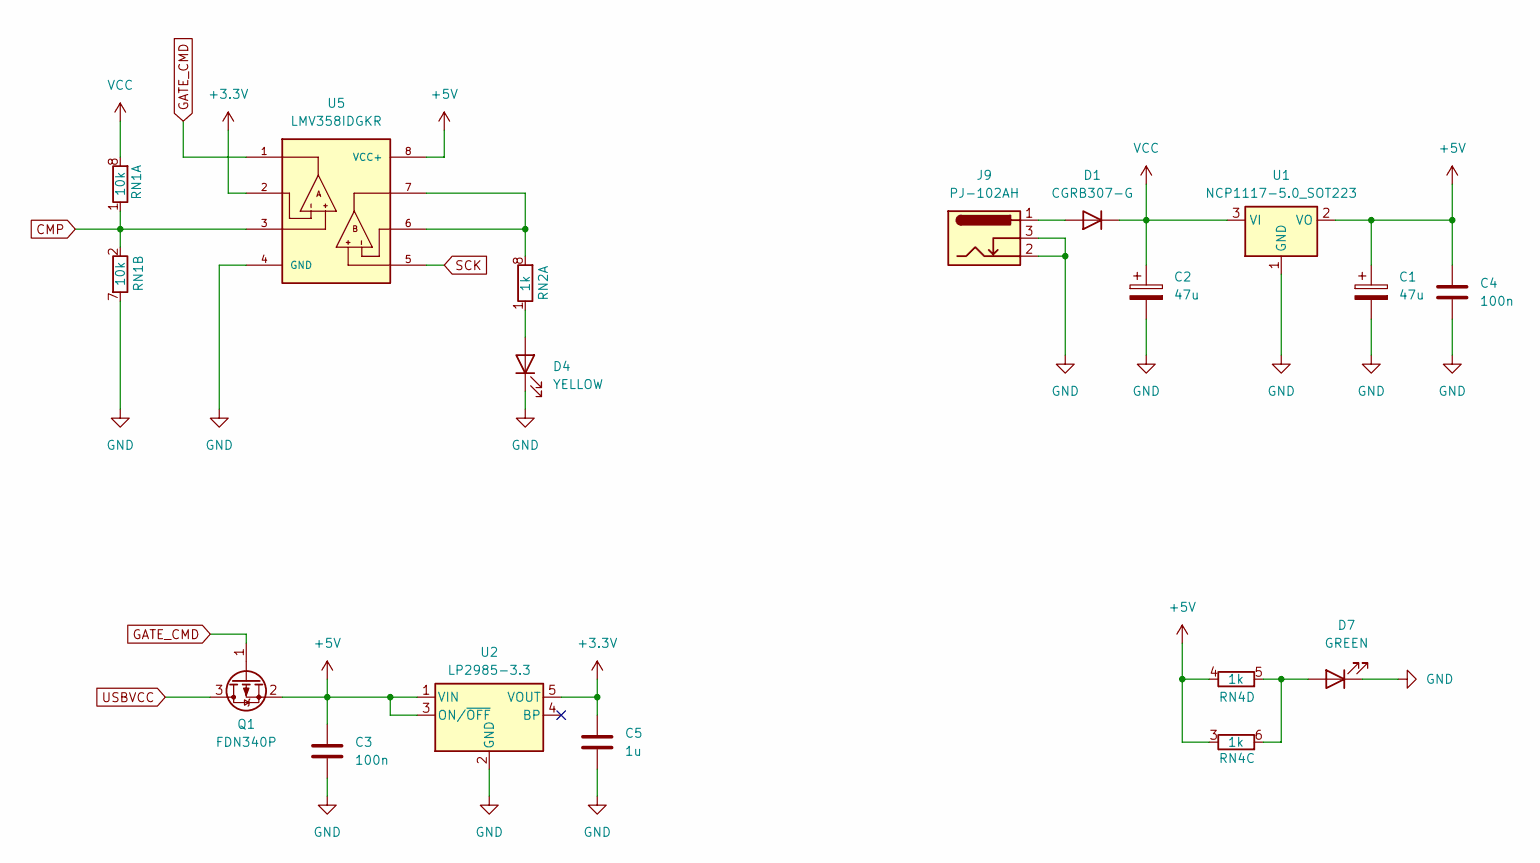
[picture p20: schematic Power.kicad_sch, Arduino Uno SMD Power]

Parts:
C1, C2: 47u; CAP_EEHZA1E470P
C3, C4: 100n; C_0603_1608Metric
C5: 1u; C_0603_1608Metric
D1: CGRB307-G; D_SMB
D4: YELLOW; LED_0805_2012Metric
D7: GREEN; LED_0805_2012Metric
J9: PJ-102AH; BarrelJack_Kycon_KLDX-0202-xC_Horizontal
Q1: FDN340P; SC-59
RN1: 10k; R_Array_Convex_4x0603
RN2, RN4: 1k; R_Array_Convex_4x0603
U1: NCP1117-5.0_SOT223; SOT-223-3_TabPin2
U2: LP2985-3.3; SOT-23-5
U5: LMV358IDGKR; MSOP-8_3x3mm_P0.65mm; PARTREV X

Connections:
+3.3V: C5.2, U2.5 (VOUT), U5.2; also elsewhere on the board
+5V: C1.1, C3.2, C4.1, Q1.2 (S), RN4.3 (R3.1), RN4.4 (R4.1), U1.2 (VO), U2.1 (VIN), U2.3 (ON/~OFF), U5.8 (VCC+); also elsewhere on the board
CMP: RN1.1 (R1.1), RN1.2 (R2.1), U5.3
GATE_CMD: Q1.1 (G), U5.1
GND: C1.2, C2.2, C3.1, C4.2, C5.1, D4.1 (K), D7.1 (K), J9.2, J9.3, RN1.7 (R2.2), U1.1 (GND), U2.2 (GND), U5.4 (GND); also elsewhere on the board
unnamed: D1.2 (A), J9.1
unnamed: D4.2 (A), RN2.1 (R1.1)
unnamed: D7.2 (A), RN4.5 (R4.2), RN4.6 (R3.2)
unnamed: RN2.8 (R1.2), U5.6, U5.7
SCK: U5.5; also elsewhere on the board
USBVCC: Q1.3 (D); also elsewhere on the board
VCC: C2.1, D1.1 (K), RN1.8 (R1.2), U1.3 (VI); also elsewhere on the board

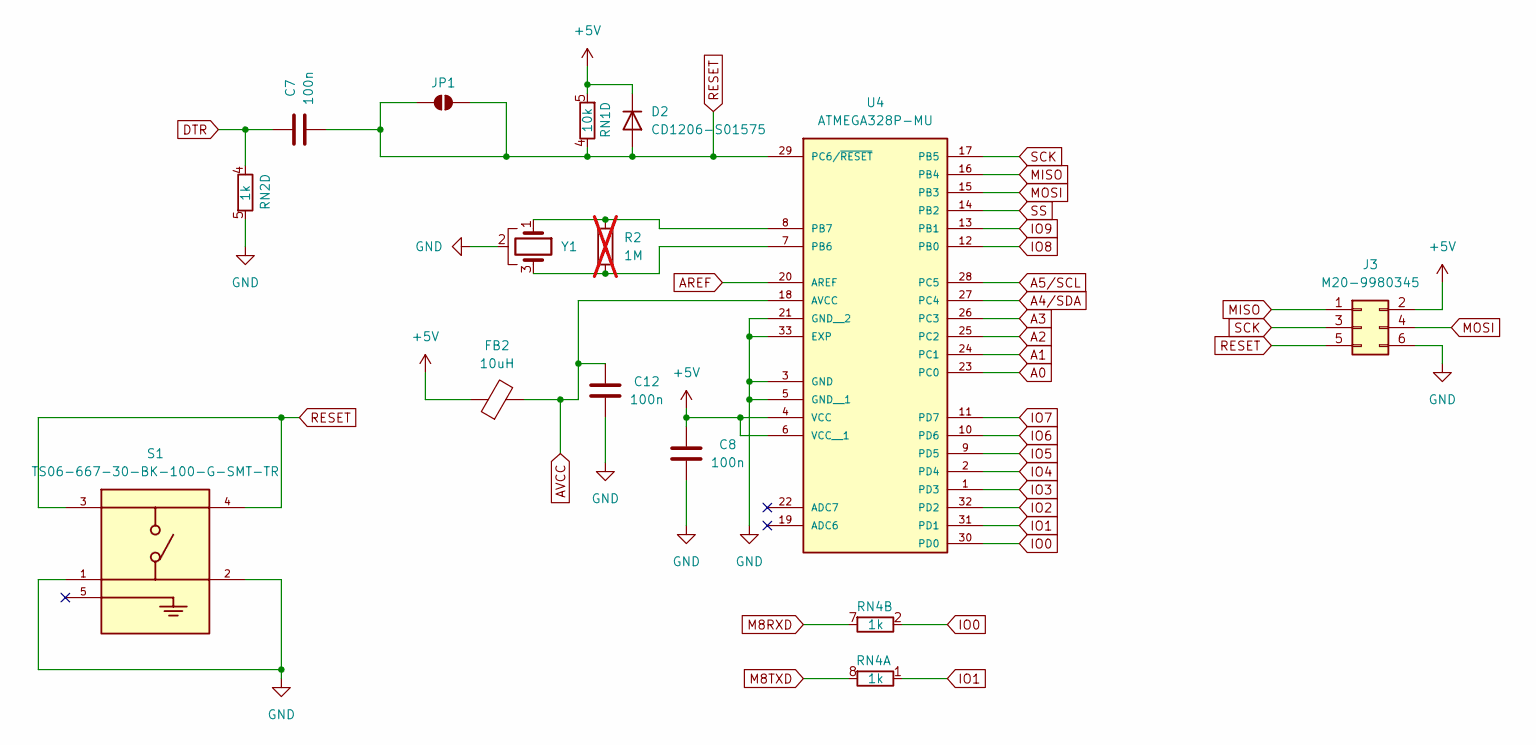
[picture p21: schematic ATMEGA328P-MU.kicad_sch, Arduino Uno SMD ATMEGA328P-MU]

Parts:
C7, C8, C12: 100n; C_0603_1608Metric
D2: CD1206-S01575; D_1206_3216Metric
FB2: 10uH; L_0805_2012Metric
J3: M20-9980345; PinHeader_2x03_P2.54mm_Vertical
JP1: SolderJumper_2_Open; SolderJumper-2_P1.3mm_Open_Pad1.0x1.5mm
R2: 1M; R_0603_1608Metric; not fitted
RN1: 10k; R_Array_Convex_4x0603
RN2, RN4: 1k; R_Array_Convex_4x0603
S1: TS06-667-30-BK-100-G-SMT-TR; SW_TS06-667-30-BK-100-G-SMT-TR; PARTREV 1.0
U4: ATMEGA328P-MU; VQFN-32-1EP_5x5mm_P0.5mm_EP3.1x3.1mm
Y1: CSTNE16M0V530000R0; Resonator_SMD_Murata_CSTxExxV-3Pin_3.0x1.1mm

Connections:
+5V: C8.2, D2.1 (K), FB2.1, J3.2, RN1.5 (R4.2), U4.4 (VCC), U4.6 (VCC__1); also elsewhere on the board
A0: U4.23 (PC0); also elsewhere on the board
A1: U4.24 (PC1); also elsewhere on the board
A2: U4.25 (PC2); also elsewhere on the board
A3: U4.26 (PC3); also elsewhere on the board
A4/SDA: U4.27 (PC4); also elsewhere on the board
A5/SCL: U4.28 (PC5); also elsewhere on the board
AREF: U4.20 (AREF); also elsewhere on the board
AVCC: C12.1, FB2.2, U4.18 (AVCC)
DTR: C7.1, RN2.4 (R4.1); also elsewhere on the board
GND: C8.1, C12.2, J3.6, RN2.5 (R4.2), S1.1, S1.2, U4.3 (GND), U4.5 (GND__1), U4.21 (GND__2), U4.33 (EXP), Y1.2; also elsewhere on the board
IO0: RN4.2 (R2.1), U4.30 (PD0); also elsewhere on the board
IO1: RN4.1 (R1.1), U4.31 (PD1); also elsewhere on the board
IO2: U4.32 (PD2); also elsewhere on the board
IO3: U4.1 (PD3); also elsewhere on the board
IO4: U4.2 (PD4); also elsewhere on the board
IO5: U4.9 (PD5); also elsewhere on the board
IO6: U4.10 (PD6); also elsewhere on the board
IO7: U4.11 (PD7); also elsewhere on the board
IO8: U4.12 (PB0); also elsewhere on the board
IO9: U4.13 (PB1); also elsewhere on the board
M8RXD: RN4.7 (R2.2); also elsewhere on the board
M8TXD: RN4.8 (R1.2); also elsewhere on the board
MISO: J3.1, U4.16 (PB4); also elsewhere on the board
MOSI: J3.4, U4.15 (PB3); also elsewhere on the board
unnamed: R2.2, U4.7 (PB6), Y1.3
unnamed: R2.1, U4.8 (PB7), Y1.1
RESET: C7.2, D2.2 (A), J3.5, JP1.1 (A), JP1.2 (B), RN1.4 (R4.1), S1.3, S1.4, U4.29 (PC6/~RESET); also elsewhere on the board
SCK: J3.3, U4.17 (PB5); also elsewhere on the board
SS: U4.14 (PB2); also elsewhere on the board

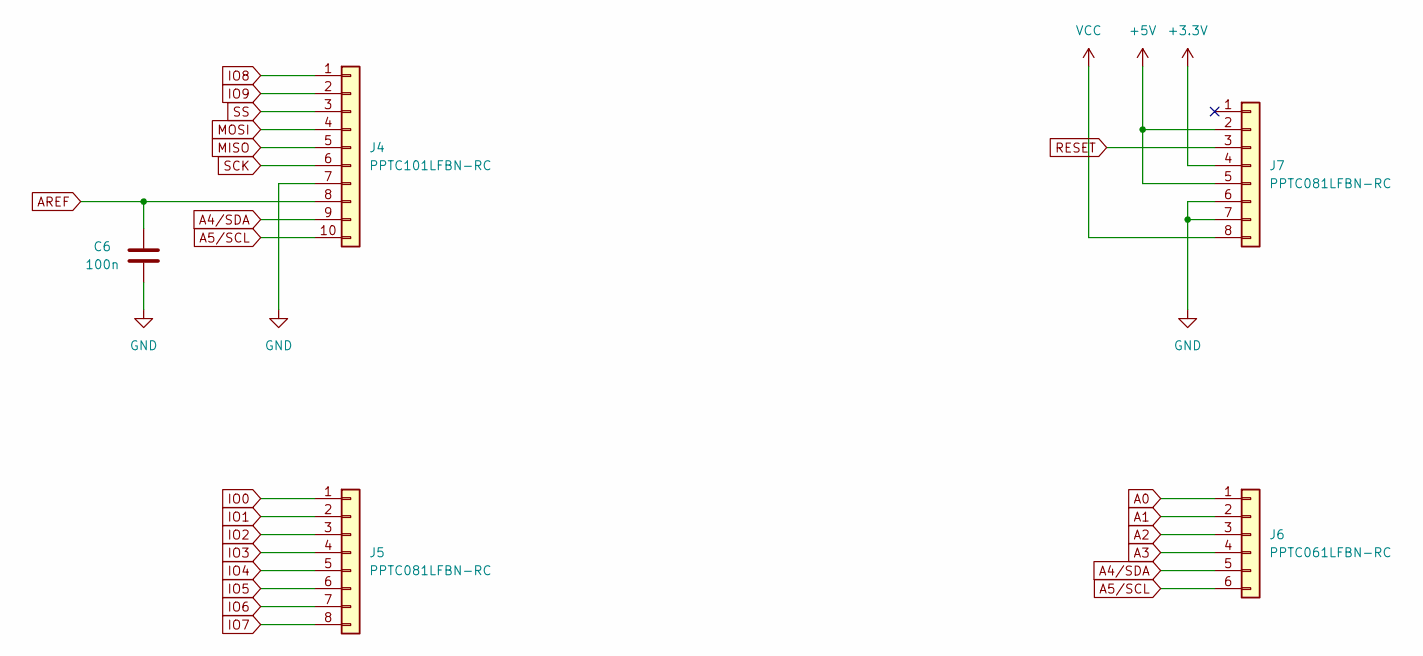
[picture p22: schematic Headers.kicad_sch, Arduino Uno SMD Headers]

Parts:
C6: 100n; C_0603_1608Metric
J4: PPTC101LFBN-RC; PinSocket_1x10_P2.54mm_Vertical
J5, J7: PPTC081LFBN-RC; PinSocket_1x08_P2.54mm_Vertical
J6: PPTC061LFBN-RC; PinSocket_1x06_P2.54mm_Vertical

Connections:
+3.3V: J7.4; also elsewhere on the board
+5V: J7.2, J7.5; also elsewhere on the board
A0: J6.1; also elsewhere on the board
A1: J6.2; also elsewhere on the board
A2: J6.3; also elsewhere on the board
A3: J6.4; also elsewhere on the board
A4/SDA: J4.9, J6.5; also elsewhere on the board
A5/SCL: J4.10, J6.6; also elsewhere on the board
AREF: C6.1, J4.8; also elsewhere on the board
GND: C6.2, J4.7, J7.6, J7.7; also elsewhere on the board
IO0: J5.1; also elsewhere on the board
IO1: J5.2; also elsewhere on the board
IO2: J5.3; also elsewhere on the board
IO3: J5.4; also elsewhere on the board
IO4: J5.5; also elsewhere on the board
IO5: J5.6; also elsewhere on the board
IO6: J5.7; also elsewhere on the board
IO7: J5.8; also elsewhere on the board
IO8: J4.1; also elsewhere on the board
IO9: J4.2; also elsewhere on the board
MISO: J4.5; also elsewhere on the board
MOSI: J4.4; also elsewhere on the board
RESET: J7.3; also elsewhere on the board
SCK: J4.6; also elsewhere on the board
SS: J4.3; also elsewhere on the board
VCC: J7.8; also elsewhere on the board

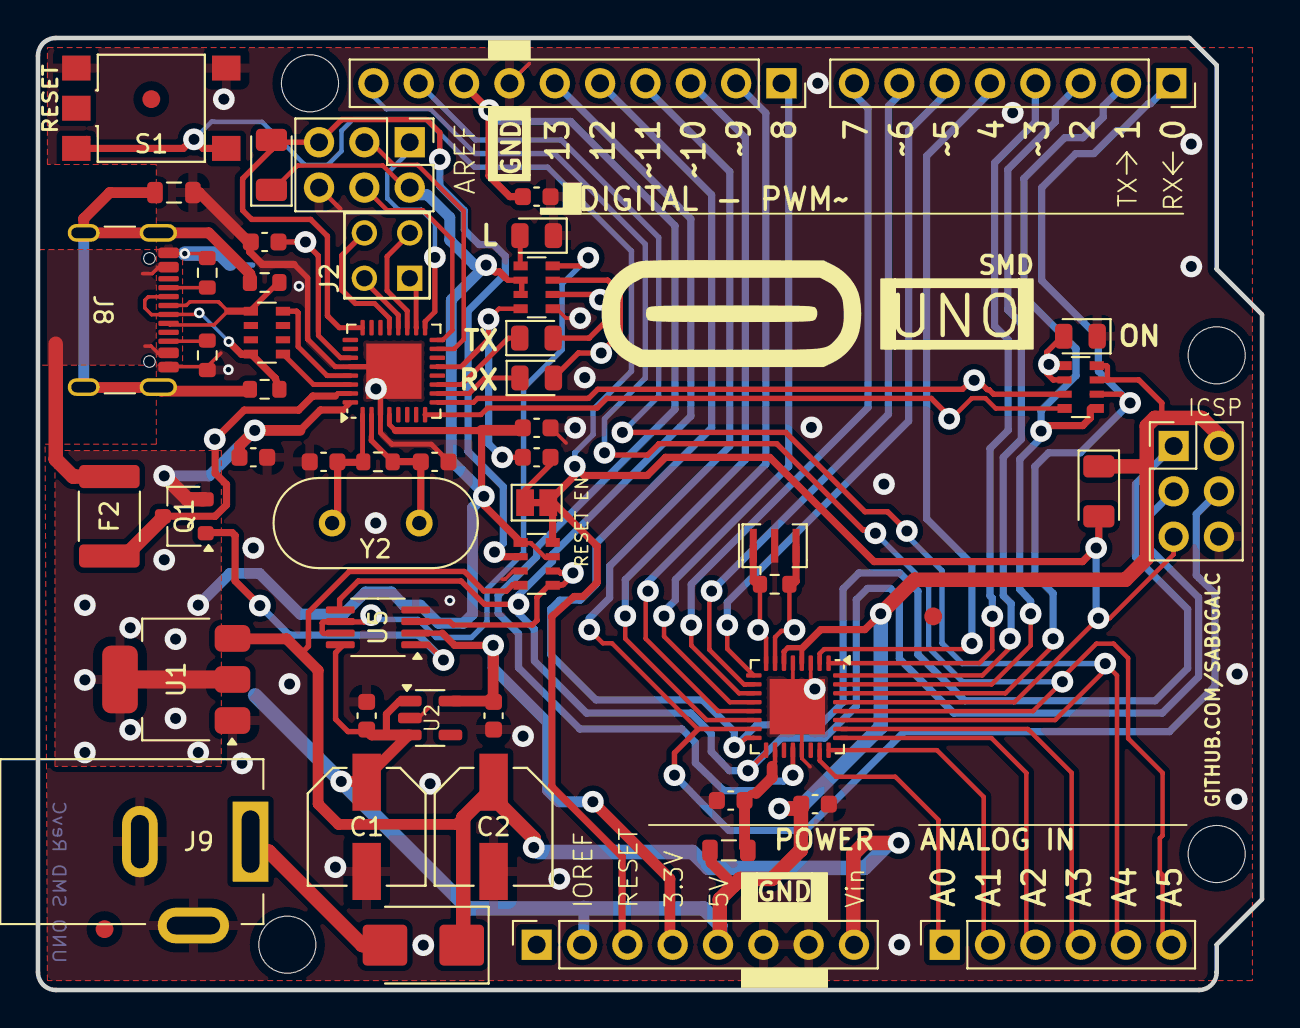
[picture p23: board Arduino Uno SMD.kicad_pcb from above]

Board: 2 copper layers, 68.6 x 53.3 mm, 56 parts (1 on the bottom side), 62 nets.

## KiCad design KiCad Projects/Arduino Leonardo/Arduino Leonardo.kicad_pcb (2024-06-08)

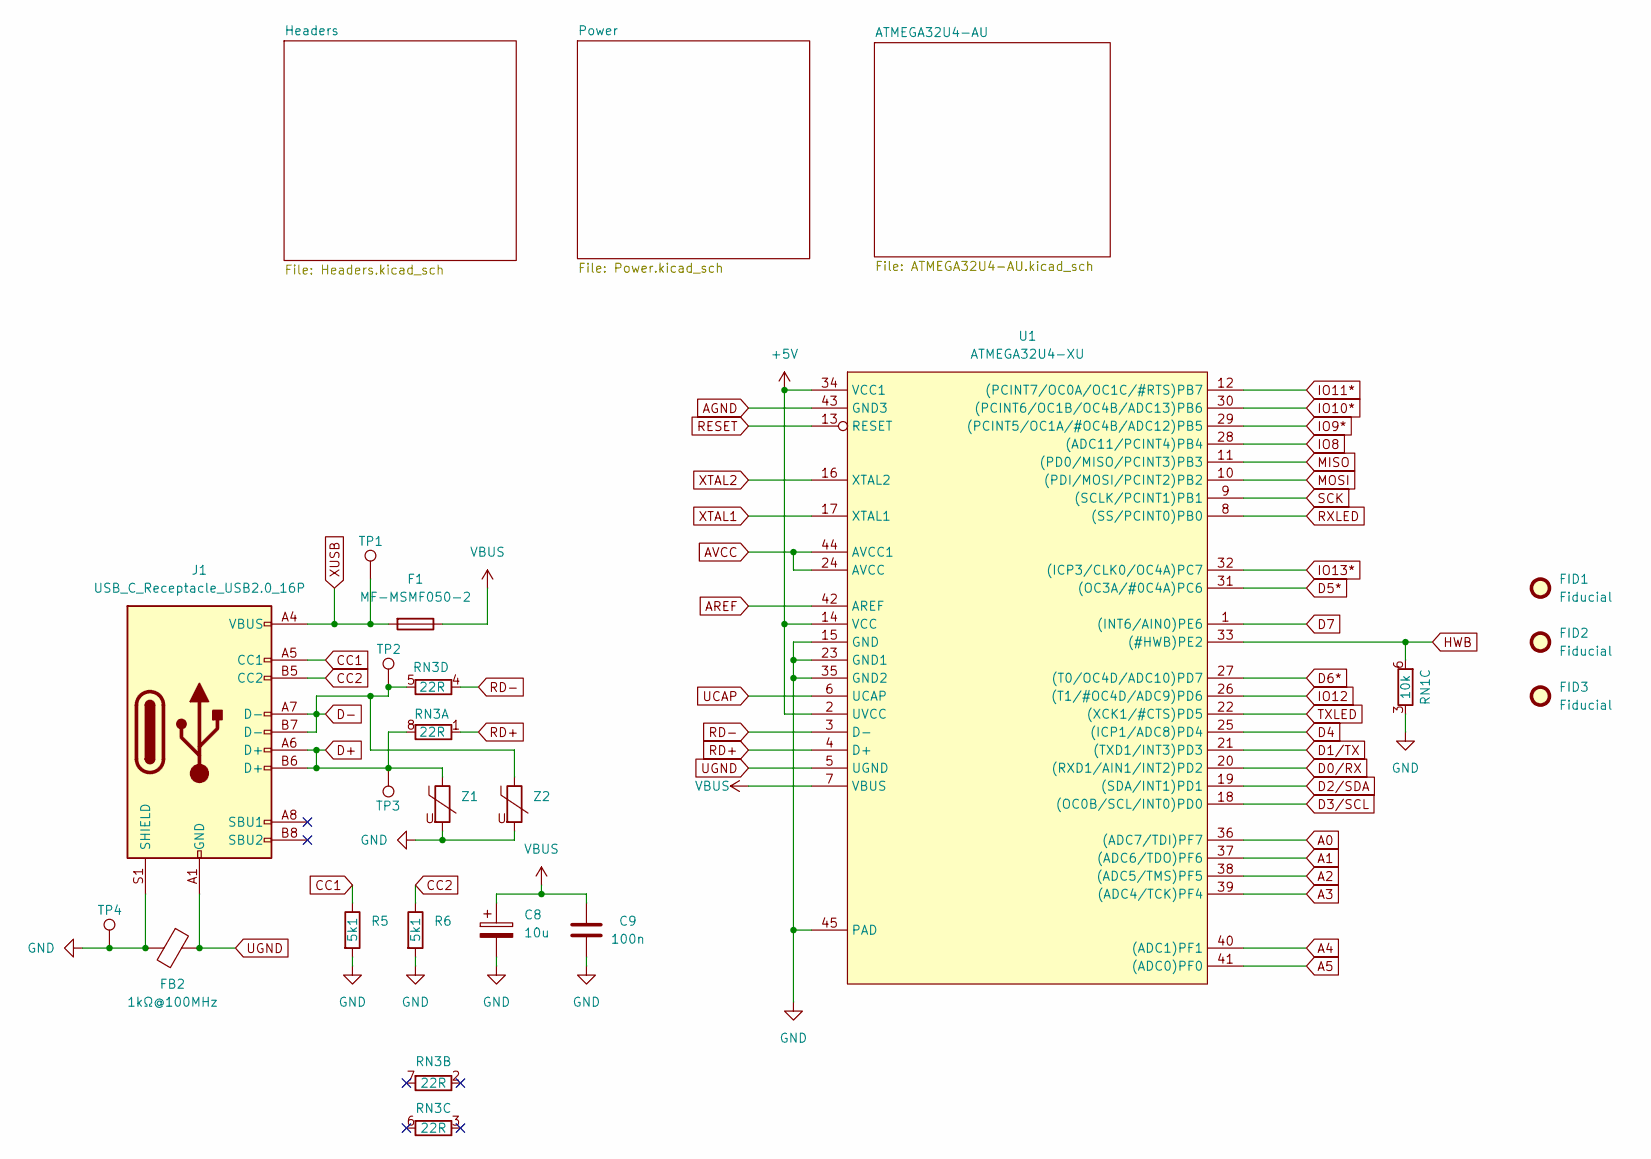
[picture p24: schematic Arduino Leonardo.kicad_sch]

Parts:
C8: 10u; C_1210_3225Metric_Pad1.33x2.70mm_HandSolder
C9: 100n; C_0603_1608Metric
F1: MF-MSMF050-2; Fuse_1812_4532Metric_Pad1.30x3.40mm_HandSolder
FB2: 1kΩ@100MHz; L_0805_2012Metric
FID1, FID2, FID3: Fiducial; Fiducial_1mm_Mask2mm
J1: USB_C_Receptacle_USB2.0_16P; USB_C_Receptacle_GCT_USB4105-xx-A_16P_TopMnt_Horizontal
R5, R6: 5k1; R_0603_1608Metric
RN1: 10k; R_Array_Convex_4x0612
RN3: 22R; R_Array_Convex_4x0612
TP1, TP2, TP3, TP4: TestPoint; TestPoint_Pad_D1.0mm
U1: ATMEGA32U4-XU; QFN-44-1EP_7x7mm_P0.5mm_EP5.15x5.15mm
Z1, Z2: 5pF@1MHz; R_0603_1608Metric

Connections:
+5V: U1.2 (UVCC), U1.14 (VCC), U1.34 (VCC1); also elsewhere on the board
A0: U1.36 ((ADC7/TDI)PF7); also elsewhere on the board
A1: U1.37 ((ADC6/TDO)PF6); also elsewhere on the board
A2: U1.38 ((ADC5/TMS)PF5); also elsewhere on the board
A3: U1.39 ((ADC4/TCK)PF4); also elsewhere on the board
A4: U1.40 ((ADC1)PF1); also elsewhere on the board
A5: U1.41 ((ADC0)PF0); also elsewhere on the board
AGND: U1.43 (GND3); also elsewhere on the board
AREF: U1.42 (AREF); also elsewhere on the board
AVCC: U1.24 (AVCC), U1.44 (AVCC1); also elsewhere on the board
CC1: J1.A5 (CC1), R5.1
CC2: J1.B5 (CC2), R6.1
D0/RX: U1.20 ((RXD1/AIN1/INT2)PD2); also elsewhere on the board
D1/TX: U1.21 ((TXD1/INT3)PD3); also elsewhere on the board
D2/SDA: U1.19 ((SDA/INT1)PD1); also elsewhere on the board
D3/SCL: U1.18 ((OC0B/SCL/INT0)PD0); also elsewhere on the board
D4: U1.25 ((ICP1/ADC8)PD4); also elsewhere on the board
D5*: U1.31 ((OC3A/#0C4A)PC6); also elsewhere on the board
D6*: U1.27 ((T0/OC4D/ADC10)PD7); also elsewhere on the board
D7: U1.1 ((INT6/AIN0)PE6); also elsewhere on the board
D+: J1.A6 (D+), J1.B6 (D+), RN3.8 (R1.2), TP3.1, Z1.1
D-: J1.A7 (D-), J1.B7 (D-), RN3.5 (R4.2), TP2.1, Z2.1
GND: C8.2, C9.1, FB2.2, J1.S1 (SHIELD), R5.2, R6.2, RN1.3 (R3.1), TP4.1, U1.15 (GND), U1.23 (GND1), U1.35 (GND2), U1.45 (PAD), Z1.2, Z2.2; also elsewhere on the board
HWB: RN1.6 (R3.2), U1.33 ((#HWB)PE2); also elsewhere on the board
IO8: U1.28 ((ADC11/PCINT4)PB4); also elsewhere on the board
IO9*: U1.29 ((PCINT5/OC1A/#OC4B/ADC12)PB5); also elsewhere on the board
IO10*: U1.30 ((PCINT6/OC1B/OC4B/ADC13)PB6); also elsewhere on the board
IO11*: U1.12 ((PCINT7/OC0A/OC1C/#RTS)PB7); also elsewhere on the board
IO12: U1.26 ((T1/#OC4D/ADC9)PD6); also elsewhere on the board
IO13*: U1.32 ((ICP3/CLK0/OC4A)PC7); also elsewhere on the board
MISO: U1.11 ((PD0/MISO/PCINT3)PB3); also elsewhere on the board
MOSI: U1.10 ((PDI/MOSI/PCINT2)PB2); also elsewhere on the board
RD+: RN3.1 (R1.1), U1.4 (D+); also elsewhere on the board
RD-: RN3.4 (R4.1), U1.3 (D-); also elsewhere on the board
RESET: U1.13 (RESET); also elsewhere on the board
RXLED: U1.8 ((SS/PCINT0)PB0); also elsewhere on the board
SCK: U1.9 ((SCLK/PCINT1)PB1); also elsewhere on the board
TXLED: U1.22 ((XCK1/#CTS)PD5); also elsewhere on the board
UCAP: U1.6 (UCAP); also elsewhere on the board
UGND: FB2.1, J1.A1 (GND), J1.A12 (GND), J1.B1 (GND), J1.B12 (GND), U1.5 (UGND); also elsewhere on the board
VBUS: C8.1, C9.2, F1.1, U1.7 (VBUS); also elsewhere on the board
XTAL1: U1.17 (XTAL1); also elsewhere on the board
XTAL2: U1.16 (XTAL2); also elsewhere on the board
XUSB: F1.2, J1.A4 (VBUS), J1.A9 (VBUS), J1.B4 (VBUS), J1.B9 (VBUS), TP1.1

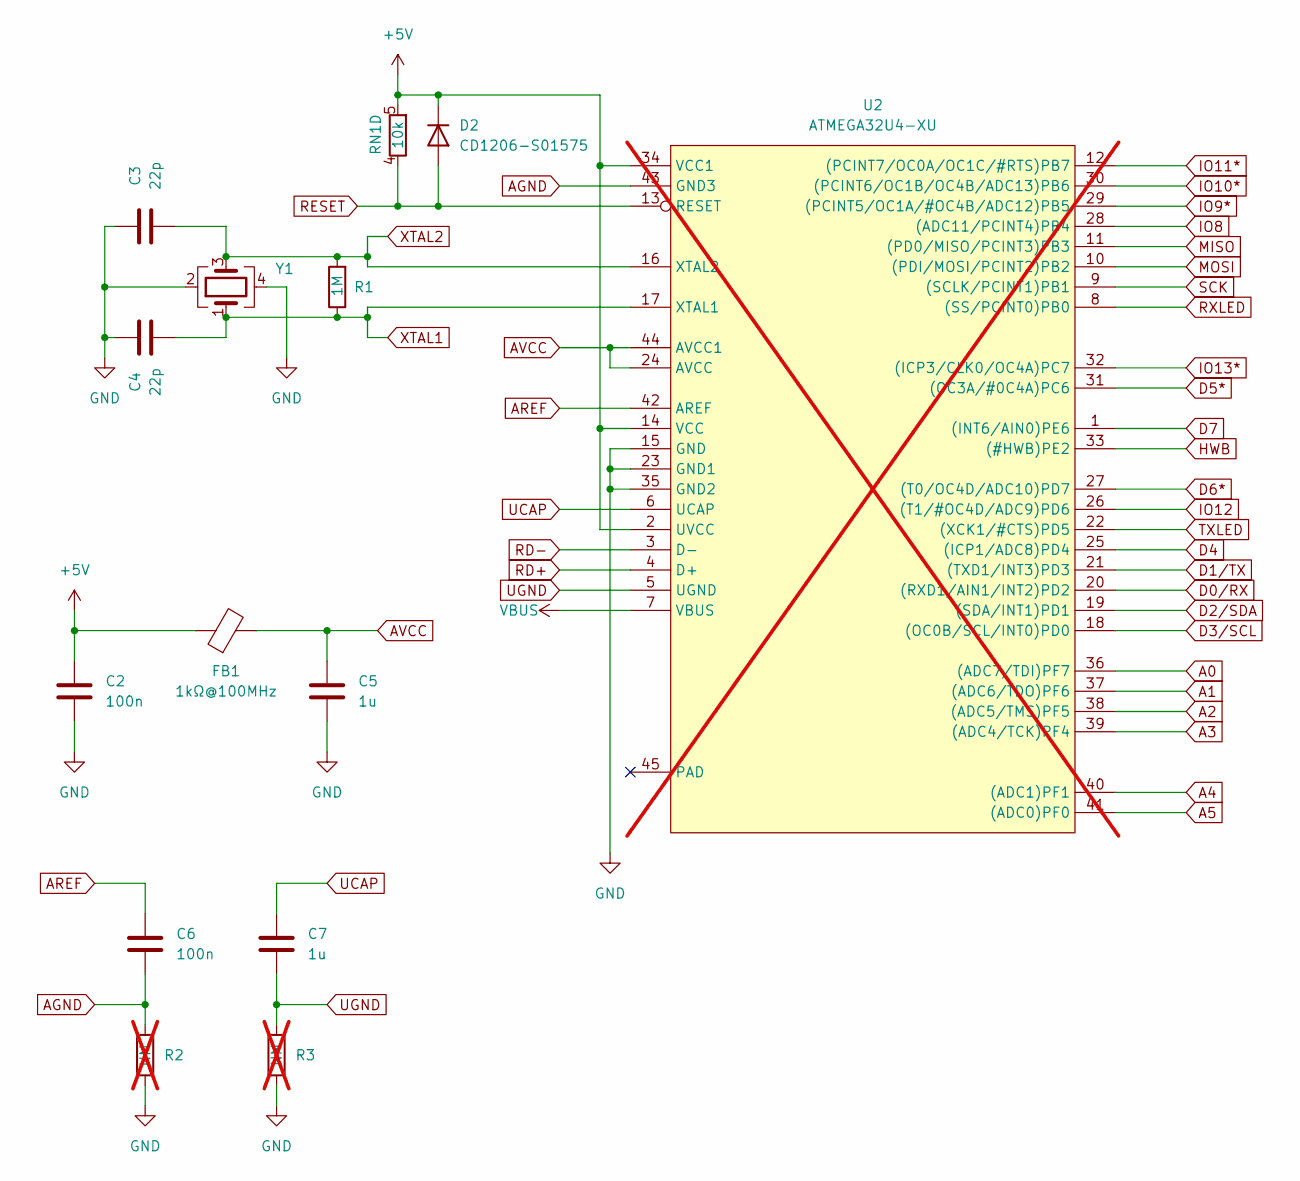
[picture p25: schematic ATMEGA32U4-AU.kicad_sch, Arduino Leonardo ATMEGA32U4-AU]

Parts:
C2, C6: 100n; C_0603_1608Metric
C3, C4: 22p; C_0603_1608Metric
C5, C7: 1u; C_0603_1608Metric
D2: CD1206-S01575; D_1206_3216Metric
FB1: 1kΩ@100MHz; L_0805_2012Metric
R1: 1M; R_0603_1608Metric
R2, R3: NM; R_0603_1608Metric; not fitted
RN1: 10k; R_Array_Convex_4x0612
U2: ATMEGA32U4-XU; TQFP-44_10x10mm_P0.8mm; not fitted
Y1: ECS-160-18-33-JGN-TR; Crystal_SMD_SeikoEpson_FA238-4Pin_3.2x2.5mm

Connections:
+5V: C2.1, D2.1 (K), FB1.1, RN1.5 (R4.2), U2.2 (UVCC), U2.14 (VCC), U2.34 (VCC1); also elsewhere on the board
A0: U2.36 ((ADC7/TDI)PF7); also elsewhere on the board
A1: U2.37 ((ADC6/TDO)PF6); also elsewhere on the board
A2: U2.38 ((ADC5/TMS)PF5); also elsewhere on the board
A3: U2.39 ((ADC4/TCK)PF4); also elsewhere on the board
A4: U2.40 ((ADC1)PF1); also elsewhere on the board
A5: U2.41 ((ADC0)PF0); also elsewhere on the board
AGND: C6.1, R2.1, U2.43 (GND3); also elsewhere on the board
AREF: C6.2, U2.42 (AREF); also elsewhere on the board
AVCC: C5.1, FB1.2, U2.24 (AVCC), U2.44 (AVCC1); also elsewhere on the board
D0/RX: U2.20 ((RXD1/AIN1/INT2)PD2); also elsewhere on the board
D1/TX: U2.21 ((TXD1/INT3)PD3); also elsewhere on the board
D2/SDA: U2.19 ((SDA/INT1)PD1); also elsewhere on the board
D3/SCL: U2.18 ((OC0B/SCL/INT0)PD0); also elsewhere on the board
D4: U2.25 ((ICP1/ADC8)PD4); also elsewhere on the board
D5*: U2.31 ((OC3A/#0C4A)PC6); also elsewhere on the board
D6*: U2.27 ((T0/OC4D/ADC10)PD7); also elsewhere on the board
D7: U2.1 ((INT6/AIN0)PE6); also elsewhere on the board
GND: C2.2, C3.1, C4.2, C5.2, R2.2, R3.1, U2.15 (GND), U2.23 (GND1), U2.35 (GND2), Y1.2, Y1.4; also elsewhere on the board
HWB: U2.33 ((#HWB)PE2); also elsewhere on the board
IO8: U2.28 ((ADC11/PCINT4)PB4); also elsewhere on the board
IO9*: U2.29 ((PCINT5/OC1A/#OC4B/ADC12)PB5); also elsewhere on the board
IO10*: U2.30 ((PCINT6/OC1B/OC4B/ADC13)PB6); also elsewhere on the board
IO11*: U2.12 ((PCINT7/OC0A/OC1C/#RTS)PB7); also elsewhere on the board
IO12: U2.26 ((T1/#OC4D/ADC9)PD6); also elsewhere on the board
IO13*: U2.32 ((ICP3/CLK0/OC4A)PC7); also elsewhere on the board
MISO: U2.11 ((PD0/MISO/PCINT3)PB3); also elsewhere on the board
MOSI: U2.10 ((PDI/MOSI/PCINT2)PB2); also elsewhere on the board
RD+: U2.4 (D+); also elsewhere on the board
RD-: U2.3 (D-); also elsewhere on the board
RESET: D2.2 (A), RN1.4 (R4.1), U2.13 (RESET); also elsewhere on the board
RXLED: U2.8 ((SS/PCINT0)PB0); also elsewhere on the board
SCK: U2.9 ((SCLK/PCINT1)PB1); also elsewhere on the board
TXLED: U2.22 ((XCK1/#CTS)PD5); also elsewhere on the board
UCAP: C7.1, U2.6 (UCAP); also elsewhere on the board
UGND: C7.2, R3.2, U2.5 (UGND); also elsewhere on the board
VBUS: U2.7 (VBUS); also elsewhere on the board
XTAL1: C4.1, R1.1, U2.17 (XTAL1), Y1.1; also elsewhere on the board
XTAL2: C3.2, R1.2, U2.16 (XTAL2), Y1.3; also elsewhere on the board

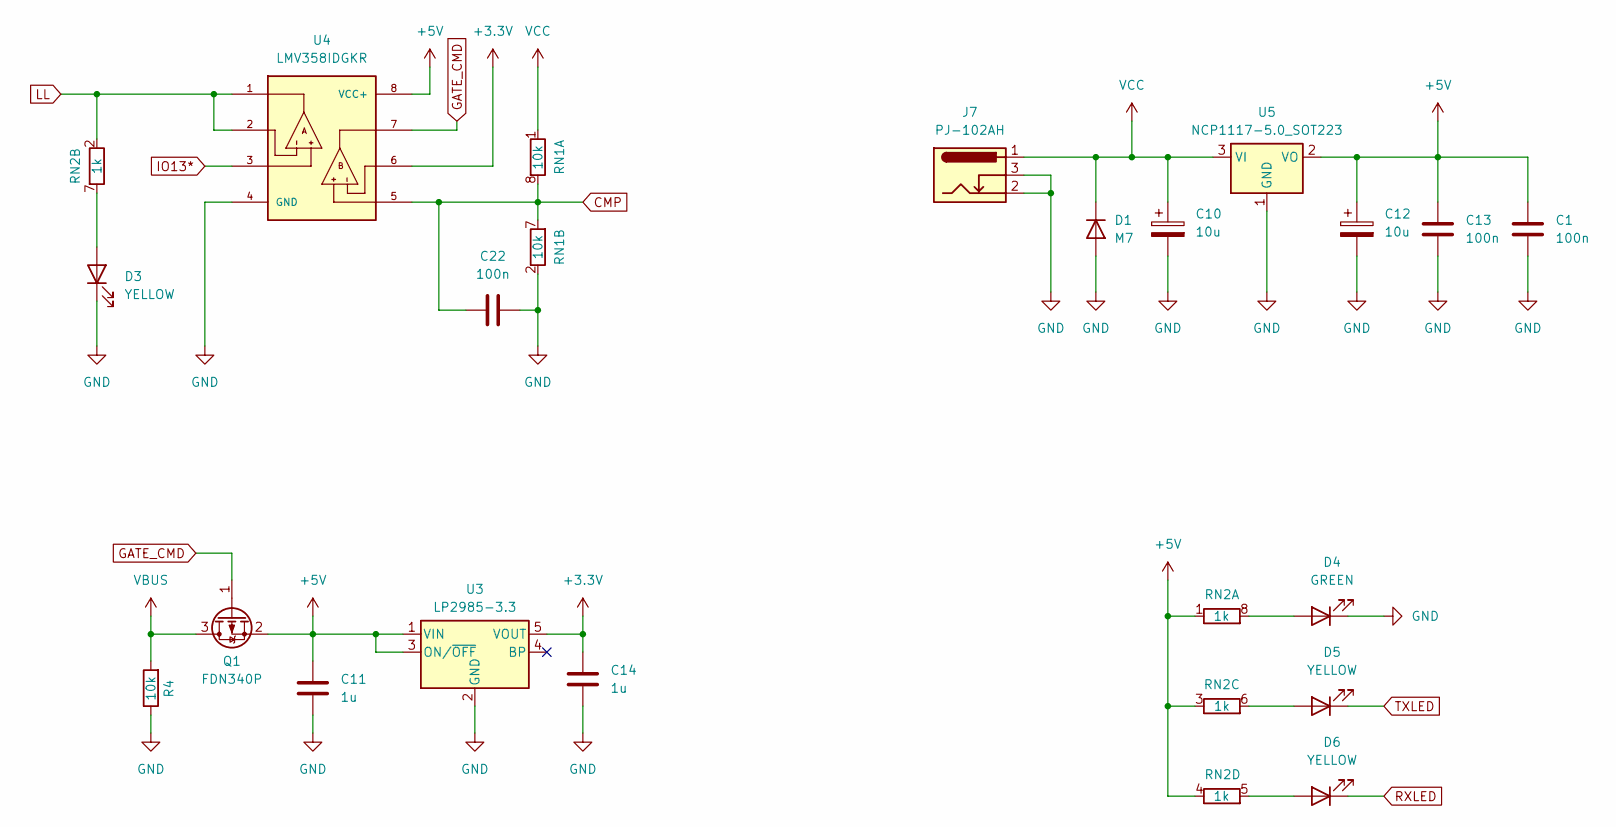
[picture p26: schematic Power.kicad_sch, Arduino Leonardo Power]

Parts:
C1, C13, C22: 100n; C_0603_1608Metric
C10, C12: 10u; C_1210_3225Metric_Pad1.33x2.70mm_HandSolder
C11, C14: 1u; C_0603_1608Metric
D1: M7; D_SMB
D3, D5, D6: YELLOW; LED_0805_2012Metric
D4: GREEN; LED_0805_2012Metric
J7: PJ-102AH; BarrelJack_Kycon_KLDX-0202-xC_Horizontal
Q1: FDN340P; SC-59
R4: 10k; R_0603_1608Metric
RN1: 10k; R_Array_Convex_4x0612
RN2: 1k; R_Array_Convex_4x0612
U3: LP2985-3.3; SOT-23-5
U4: LMV358IDGKR; MSOP-8_3x3mm_P0.65mm; PARTREV X
U5: NCP1117-5.0_SOT223; SOT-223-3_TabPin2

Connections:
+3.3V: C14.2, U3.5 (VOUT), U4.6; also elsewhere on the board
+5V: C1.1, C11.2, C12.1, C13.1, Q1.2 (S), RN2.1 (R1.1), RN2.3 (R3.1), RN2.4 (R4.1), U3.1 (VIN), U3.3 (ON/~OFF), U4.8 (VCC+), U5.2 (VO); also elsewhere on the board
CMP: C22.2, RN1.7 (R2.2), RN1.8 (R1.2), U4.5
GATE_CMD: Q1.1 (G), U4.7
GND: C1.2, C10.2, C11.1, C12.2, C13.2, C14.1, C22.1, D1.2 (A), D3.1 (K), D4.1 (K), J7.2, J7.3, R4.1, RN1.2 (R2.1), U3.2 (GND), U4.4 (GND), U5.1 (GND); also elsewhere on the board
IO13*: U4.3; also elsewhere on the board
LL: RN2.2 (R2.1), U4.1, U4.2
unnamed: D3.2 (A), RN2.7 (R2.2)
unnamed: D4.2 (A), RN2.8 (R1.2)
unnamed: D5.2 (A), RN2.6 (R3.2)
unnamed: D6.2 (A), RN2.5 (R4.2)
RXLED: D6.1 (K); also elsewhere on the board
TXLED: D5.1 (K); also elsewhere on the board
VBUS: Q1.3 (D), R4.2; also elsewhere on the board
VCC: C10.1, D1.1 (K), J7.1, RN1.1 (R1.1), U5.3 (VI); also elsewhere on the board

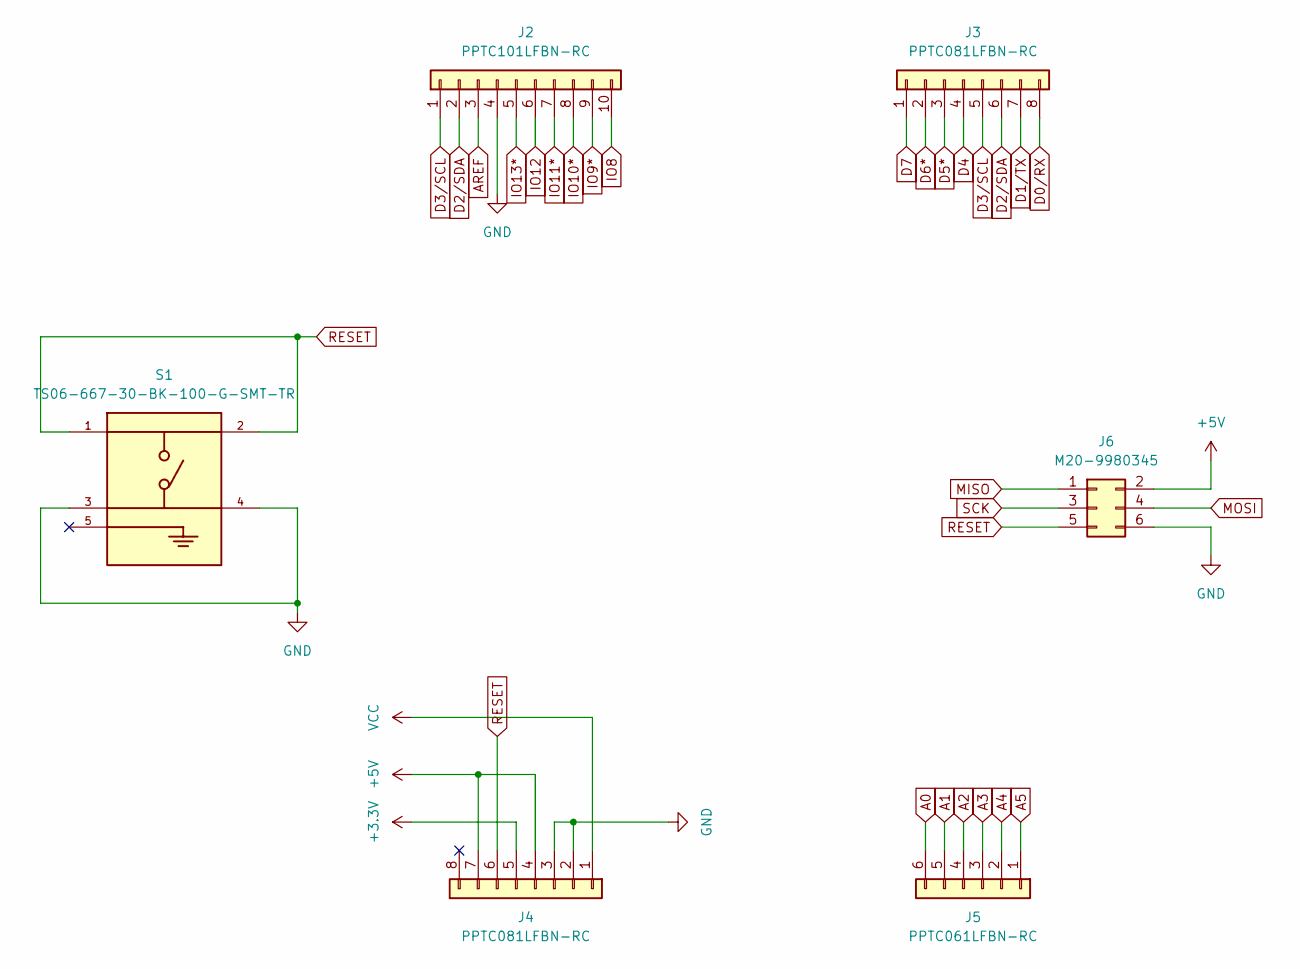
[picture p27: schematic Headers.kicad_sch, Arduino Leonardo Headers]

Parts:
J2: PPTC101LFBN-RC; PinSocket_1x10_P2.54mm_Vertical
J3, J4: PPTC081LFBN-RC; PinSocket_1x08_P2.54mm_Vertical
J5: PPTC061LFBN-RC; PinSocket_1x06_P2.54mm_Vertical
J6: M20-9980345; PinHeader_2x03_P2.54mm_Vertical
S1: TS06-667-30-BK-100-G-SMT-TR; SW_TS06-667-30-BK-100-G-SMT-TR; PARTREV 1.0

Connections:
+3.3V: J4.5; also elsewhere on the board
+5V: J4.4, J4.7, J6.2; also elsewhere on the board
A0: J5.6; also elsewhere on the board
A1: J5.5; also elsewhere on the board
A2: J5.4; also elsewhere on the board
A3: J5.3; also elsewhere on the board
A4: J5.2; also elsewhere on the board
A5: J5.1; also elsewhere on the board
AREF: J2.3; also elsewhere on the board
D0/RX: J3.8; also elsewhere on the board
D1/TX: J3.7; also elsewhere on the board
D2/SDA: J2.2, J3.6; also elsewhere on the board
D3/SCL: J2.1, J3.5; also elsewhere on the board
D4: J3.4; also elsewhere on the board
D5*: J3.3; also elsewhere on the board
D6*: J3.2; also elsewhere on the board
D7: J3.1; also elsewhere on the board
GND: J2.4, J4.2, J4.3, J6.6, S1.3, S1.4; also elsewhere on the board
IO8: J2.10; also elsewhere on the board
IO9*: J2.9; also elsewhere on the board
IO10*: J2.8; also elsewhere on the board
IO11*: J2.7; also elsewhere on the board
IO12: J2.6; also elsewhere on the board
IO13*: J2.5; also elsewhere on the board
MISO: J6.1; also elsewhere on the board
MOSI: J6.4; also elsewhere on the board
RESET: J4.6, J6.5, S1.1, S1.2; also elsewhere on the board
SCK: J6.3; also elsewhere on the board
VCC: J4.1; also elsewhere on the board

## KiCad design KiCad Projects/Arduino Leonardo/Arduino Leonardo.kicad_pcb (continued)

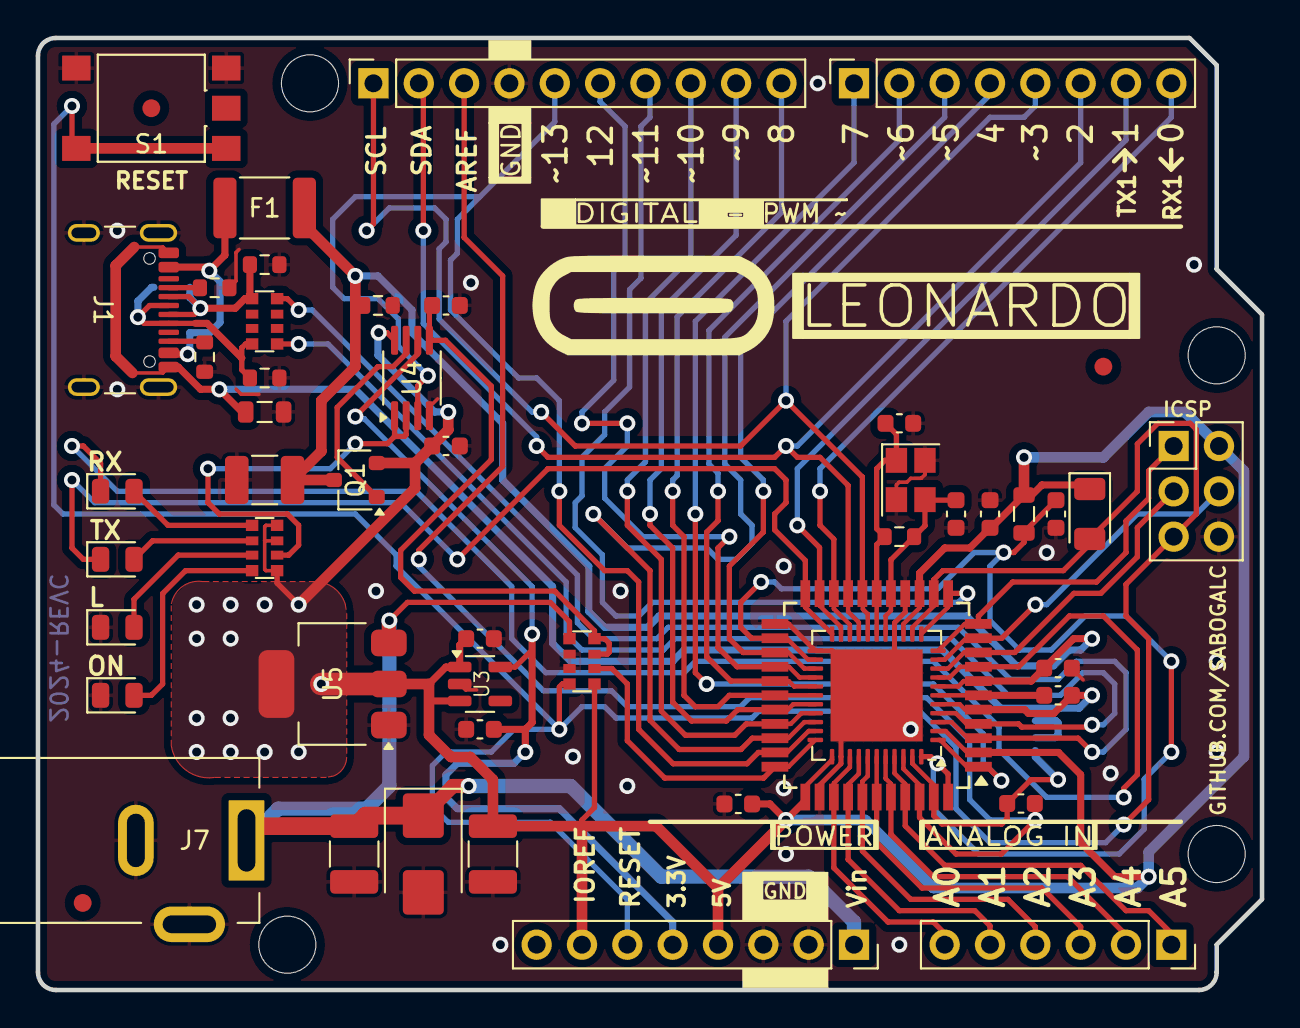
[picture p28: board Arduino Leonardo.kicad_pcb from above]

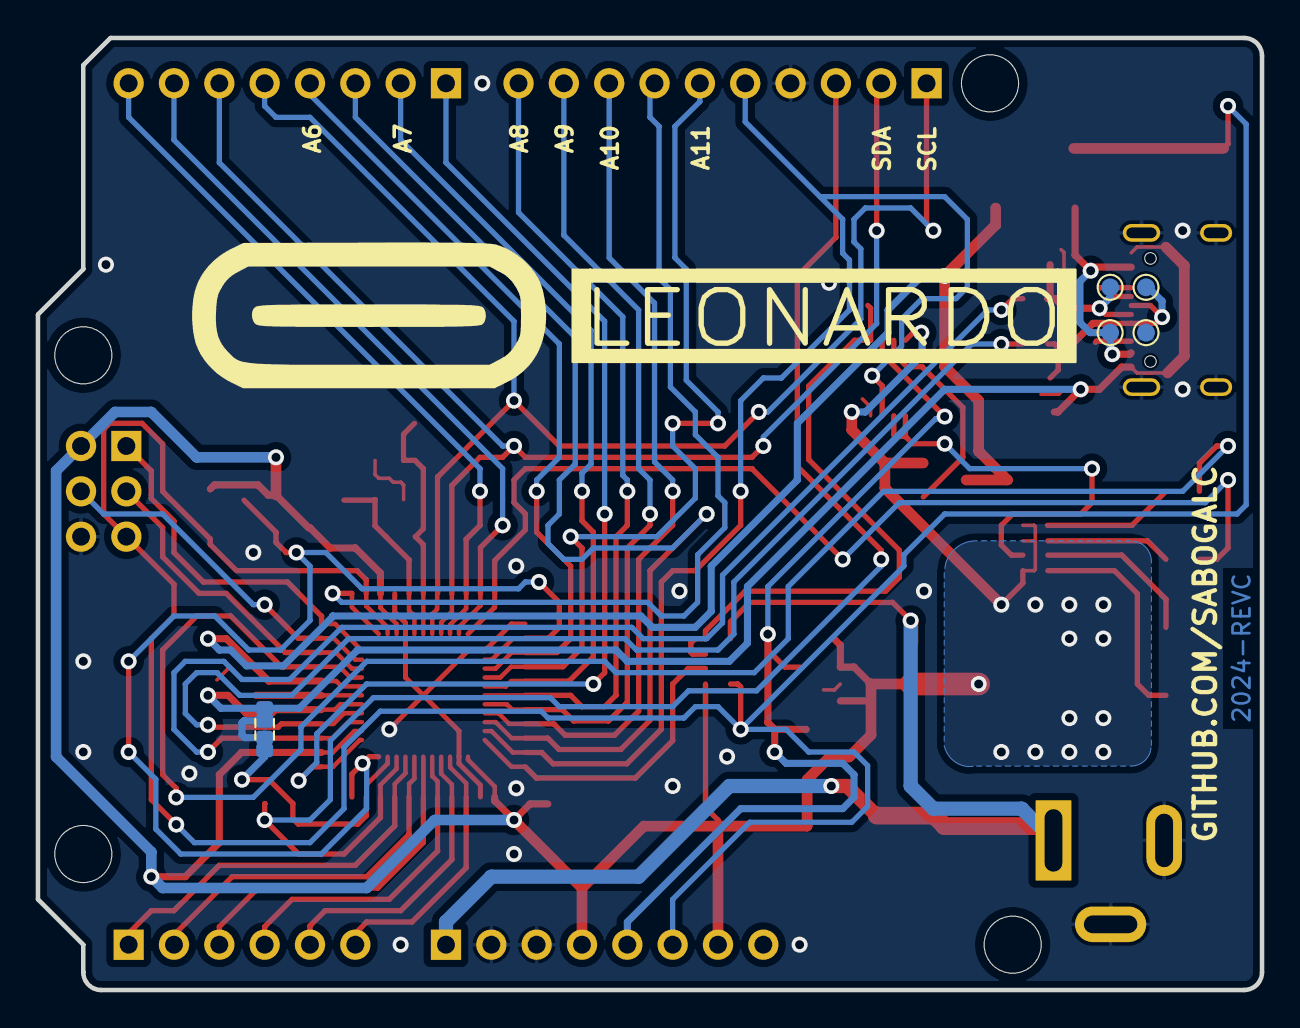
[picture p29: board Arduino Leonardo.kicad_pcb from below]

Board: 2 copper layers, 68.6 x 53.3 mm, 57 parts (6 on the bottom side), 53 nets.

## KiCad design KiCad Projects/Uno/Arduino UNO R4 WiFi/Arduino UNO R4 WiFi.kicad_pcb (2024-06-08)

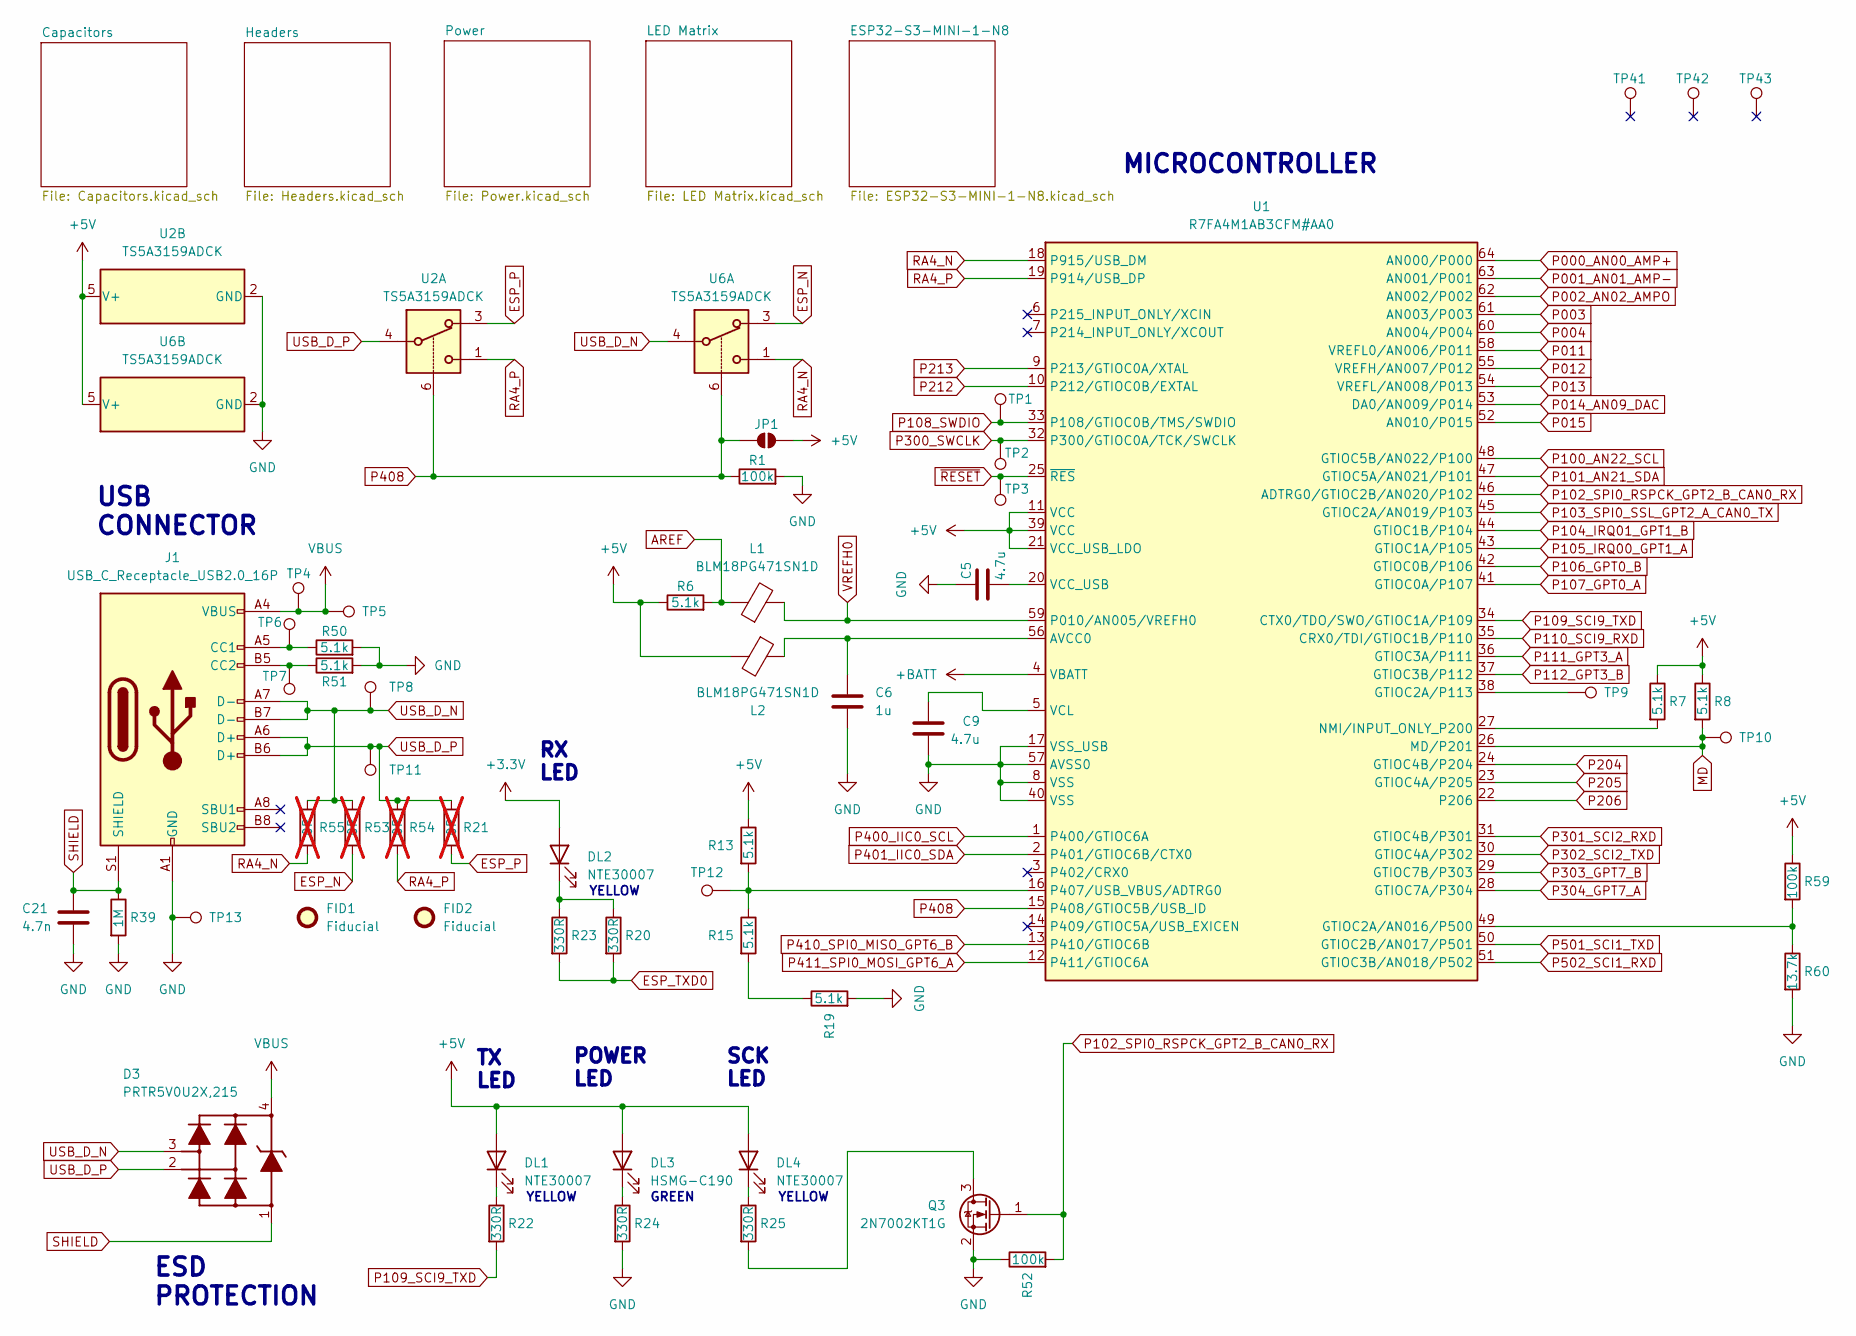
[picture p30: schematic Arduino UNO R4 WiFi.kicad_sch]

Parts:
C5, C9: 4.7u; C_0603_1608Metric
C6: 1u; C_0402_1005Metric
C21: 4.7n; C_0805_2012Metric
D3: PRTR5V0U2X,215; SOT-143
DL1, DL2, DL4: NTE30007; LED_0603_1608Metric
DL3: HSMG-C190; LED_0603_1608Metric
FID1, FID2: Fiducial; Fiducial_1mm_Mask2mm
J1: USB_C_Receptacle_USB2.0_16P; USB_C_Receptacle_GCT_USB4105-xx-A_16P_TopMnt_Horizontal
JP1: SolderJumper_2_Open; SolderJumper-2_P1.3mm_Open_Pad1.0x1.5mm
L1, L2: BLM18PG471SN1D; L_0603_1608Metric
Q3: 2N7002KT1G; SC-59
R1, R52, R59: 100k; R_0402_1005Metric
R6, R7, R8, R13, R15, R19, R50, R51: 5.1k; R_0402_1005Metric
R20, R22, R23, R24, R25: 330R; R_0402_1005Metric
R21, R53, R54, R55: 0R; R_0402_1005Metric; not fitted
R39: 1M; R_0402_1005Metric
R60: 13.7k; R_0402_1005Metric
TP1, TP2, TP3, TP4, TP6, TP7, TP10, TP12: TestPoint; TestPoint_Pad_D0.8mm
TP5, TP8, TP11, TP13, TP41, TP42, TP43: TestPoint; TestPoint_Pad_D1.0mm
TP9: TestPoint; TestPoint_P113
U1: R7FA4M1AB3CFM#AA0; LQFP-64_10x10mm_P0.5mm
U2, U6: TS5A3159ADCK; SOT-363_SC-70-6

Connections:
+3.3V: DL2.2 (A); also elsewhere on the board
+5V: DL1.2 (A), DL3.2 (A), DL4.2 (A), JP1.2 (B), L2.2, R6.1, R7.1, R8.1, R13.1, R59.1, U1.11 (VCC), U1.21 (VCC_USB_LDO), U1.39 (VCC), U2.5 (V+), U6.5 (V+); also elsewhere on the board
+BATT: U1.4 (VBATT); also elsewhere on the board
AREF: L1.1, R6.2; also elsewhere on the board
ESP_N: R53.2, U6.3; also elsewhere on the board
ESP_P: R21.2, U2.3; also elsewhere on the board
ESP_TXD0: R20.2, R23.2; also elsewhere on the board
GND: C5.2, C6.2, C9.1, C21.2, J1.A1 (GND), J1.A12 (GND), J1.B1 (GND), J1.B12 (GND), Q3.2 (S), R1.2, R19.2, R24.2, R39.2, R50.2, R51.2, R52.1, R60.2, TP13.1, U1.8 (VSS), U1.17 (VSS_USB), U1.40 (VSS), U1.57 (AVSS0), U2.2 (GND), U6.2 (GND); also elsewhere on the board
MD: R8.2, TP10.1, U1.26 (MD/P201); also elsewhere on the board
unnamed: DL1.1 (K), R22.1
unnamed: DL2.1 (K), R20.1, R23.1
unnamed: DL3.1 (K), R24.1
unnamed: DL4.1 (K), R25.1
unnamed: J1.A5 (CC1), R50.1, TP6.1
unnamed: J1.B5 (CC2), R51.1, TP7.1
unnamed: Q3.3 (D), R25.2
unnamed: R15.2, R19.1
unnamed: C6.1, L2.1, U1.56 (AVCC0)
unnamed: R59.2, R60.1, U1.49 (GTIOC2A/AN016/P500)
unnamed: TP9.1, U1.38 (GTIOC2A/P113)
unnamed: R7.2, U1.27 (NMI/INPUT_ONLY_P200)
unnamed: R13.2, R15.1, TP12.1, U1.16 (P407/USB_VBUS/ADTRG0)
unnamed: C5.1, U1.20 (VCC_USB)
unnamed: C9.2, U1.5 (VCL)
P000_AN00_AMP+: U1.64 (AN000/P000); also elsewhere on the board
P001_AN01_AMP-: U1.63 (AN001/P001); also elsewhere on the board
P002_AN02_AMPO: U1.62 (AN002/P002); also elsewhere on the board
P003: U1.61 (AN003/P003); also elsewhere on the board
P004: U1.60 (AN004/P004); also elsewhere on the board
P011: U1.58 (VREFL0/AN006/P011); also elsewhere on the board
P012: U1.55 (VREFH/AN007/P012); also elsewhere on the board
P013: U1.54 (VREFL/AN008/P013); also elsewhere on the board
P014_AN09_DAC: U1.53 (DA0/AN009/P014); also elsewhere on the board
P015: U1.52 (AN010/P015); also elsewhere on the board
P100_AN22_SCL: U1.48 (GTIOC5B/AN022/P100); also elsewhere on the board
P101_AN21_SDA: U1.47 (GTIOC5A/AN021/P101); also elsewhere on the board
P102_SPI0_RSPCK_GPT2_B_CAN0_RX: Q3.1 (G), R52.2, U1.46 (ADTRG0/GTIOC2B/AN020/P102); also elsewhere on the board
P103_SPI0_SSL_GPT2_A_CAN0_TX: U1.45 (GTIOC2A/AN019/P103); also elsewhere on the board
P104_IRQ01_GPT1_B: U1.44 (GTIOC1B/P104); also elsewhere on the board
P105_IRQ00_GPT1_A: U1.43 (GTIOC1A/P105); also elsewhere on the board
P106_GPT0_B: U1.42 (GTIOC0B/P106); also elsewhere on the board
P107_GPT0_A: U1.41 (GTIOC0A/P107); also elsewhere on the board
P108_SWDIO: TP1.1, U1.33 (P108/GTIOC0B/TMS/SWDIO); also elsewhere on the board
P109_SCI9_TXD: R22.2, U1.34 (CTX0/TDO/SWO/GTIOC1A/P109); also elsewhere on the board
P110_SCI9_RXD: U1.35 (CRX0/TDI/GTIOC1B/P110); also elsewhere on the board
P111_GPT3_A: U1.36 (GTIOC3A/P111); also elsewhere on the board
P112_GPT3_B: U1.37 (GTIOC3B/P112); also elsewhere on the board
P204: U1.24 (GTIOC4B/P204); also elsewhere on the board
P205: U1.23 (GTIOC4A/P205); also elsewhere on the board
P206: U1.22 (P206); also elsewhere on the board
P212: U1.10 (P212/GTIOC0B/EXTAL); also elsewhere on the board
P213: U1.9 (P213/GTIOC0A/XTAL); also elsewhere on the board
P300_SWCLK: TP2.1, U1.32 (P300/GTIOC0A/TCK/SWCLK); also elsewhere on the board
P301_SCI2_RXD: U1.31 (GTIOC4B/P301); also elsewhere on the board
P302_SCI2_TXD: U1.30 (GTIOC4A/P302); also elsewhere on the board
P303_GPT7_B: U1.29 (GTIOC7B/P303); also elsewhere on the board
P304_GPT7_A: U1.28 (GTIOC7A/P304); also elsewhere on the board
P400_IIC0_SCL: U1.1 (P400/GTIOC6A); also elsewhere on the board
P401_IIC0_SDA: U1.2 (P401/GTIOC6B/CTX0); also elsewhere on the board
P408: JP1.1 (A), R1.1, U1.15 (P408/GTIOC5B/USB_ID), U2.6, U6.6
P410_SPI0_MISO_GPT6_B: U1.13 (P410/GTIOC6B); also elsewhere on the board
P411_SPI0_MOSI_GPT6_A: U1.12 (P411/GTIOC6A); also elsewhere on the board
P501_SCI1_TXD: U1.50 (GTIOC2B/AN017/P501); also elsewhere on the board
P502_SCI1_RXD: U1.51 (GTIOC3B/AN018/P502); also elsewhere on the board
RA4_N: R55.2, U1.18 (P915/USB_DM), U6.1
RA4_P: R54.2, U1.19 (P914/USB_DP), U2.1
SHIELD: C21.1, D3.1, J1.S1 (SHIELD), R39.1
USB_D_N: D3.3, J1.A7 (D-), J1.B7 (D-), R53.1, R55.1, TP8.1, U6.4
USB_D_P: D3.2, J1.A6 (D+), J1.B6 (D+), R21.1, R54.1, TP11.1, U2.4
VBUS: D3.4, J1.A4 (VBUS), J1.A9 (VBUS), J1.B4 (VBUS), J1.B9 (VBUS), TP4.1, TP5.1; also elsewhere on the board
VREFH0: L1.2, U1.59 (P010/AN005/VREFH0); also elsewhere on the board
~RESET: TP3.1, U1.25 (~RES); also elsewhere on the board

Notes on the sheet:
TX LED
GREEN
USB CONNECTOR
SCK LED
YELLOW
ESD PROTECTION
POWER LED
RX LED
MICROCONTROLLER


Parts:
C1: DNP; C_0402_1005Metric; not fitted
F1: MF-MSMF050-2-W2; Fuse_1812_4532Metric
J2: SM04B-SRSS-TB(LF)(SN); JST_SH_SM04B-SRSS-TB_1x04-1MP_P1.00mm_Horizontal
J3, J6: M20-9980345; PinHeader_2x03_P2.54mm_Vertical
J4, J9: PPTC081LFBN-RC; PinSocket_1x08_P2.54mm_Vertical
J7: PPTC061LFBN-RC; PinSocket_1x06_P2.54mm_Vertical
J8: PPTC101LFBN-RC; PinSocket_1x10_P2.54mm_Vertical
J10: M20-9990345; PinHeader_1x03_P2.54mm_Vertical
Q1, Q2: 2N7002KT1G; SC-59
R3: 100k; R_0402_1005Metric
R4, R5: 5.1k; R_0402_1005Metric; not fitted
R9, R10, R11, R12: 5.1k; R_0402_1005Metric
S1: TS06-667-30-BK-100-G-SMT-TR; SW_TS06-667-30-BK-100-G-SMT-TR; PARTREV 1.0
TP18: TestPoint; TestPoint_Pad_D1.0mm
TP36, TP37, TP38, TP39, TP40: TestPoint; TestPoint_Pad_D0.8mm

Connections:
+3.3V: F1.1, J4.4; also elsewhere on the board
+3.3VA: F1.2, J2.2, Q1.1 (G), Q2.1 (G), R9.1, R11.1, TP36.1
+5V: J3.2, J4.2, J4.5, R3.1, R4.1, R5.1, R10.1, R12.1; also elsewhere on the board
+BATT: J10.3; also elsewhere on the board
AREF: J8.3; also elsewhere on the board
ESP_DOWNLOAD: J6.4; also elsewhere on the board
ESP_IO41: J6.2; also elsewhere on the board
ESP_IO42: J6.1; also elsewhere on the board
ESP_RXD0: J6.5; also elsewhere on the board
ESP_TXD0: J6.3; also elsewhere on the board
EXT_SCL: J2.4, Q1.2 (S), R9.2, TP37.1
EXT_SDA: J2.3, Q2.2 (S), R11.2, TP39.1
GND: C1.2, J2.1, J2.MP (MountPin), J3.6, J4.6, J4.7, J6.6, J8.4, J10.2, S1.1, S1.2, S1.5, TP18.1; also elsewhere on the board
MD: J4.1; also elsewhere on the board
OFF: J10.1; also elsewhere on the board
P000_AN00_AMP+: J7.2; also elsewhere on the board
P001_AN01_AMP-: J7.3; also elsewhere on the board
P002_AN02_AMPO: J7.4; also elsewhere on the board
P014_AN09_DAC: J7.1; also elsewhere on the board
P100_AN22_SCL: J7.6, J8.1, R4.2; also elsewhere on the board
P101_AN21_SDA: J7.5, J8.2, R5.2; also elsewhere on the board
P102_SPI0_RSPCK_GPT2_B_CAN0_RX: J3.3, J8.5; also elsewhere on the board
P103_SPI0_SSL_GPT2_A_CAN0_TX: J8.8; also elsewhere on the board
P104_IRQ01_GPT1_B: J9.6; also elsewhere on the board
P105_IRQ00_GPT1_A: J9.5; also elsewhere on the board
P106_GPT0_B: J9.4; also elsewhere on the board
P107_GPT0_A: J9.3; also elsewhere on the board
P111_GPT3_A: J9.2; also elsewhere on the board
P112_GPT3_B: J9.1; also elsewhere on the board
P301_SCI2_RXD: J9.8; also elsewhere on the board
P302_SCI2_TXD: J9.7; also elsewhere on the board
P303_GPT7_B: J8.9; also elsewhere on the board
P304_GPT7_A: J8.10; also elsewhere on the board
P400_IIC0_SCL: Q1.3 (D), R10.2, TP38.1; also elsewhere on the board
P401_IIC0_SDA: Q2.3 (D), R12.2, TP40.1; also elsewhere on the board
P410_SPI0_MISO_GPT6_B: J3.1, J8.6; also elsewhere on the board
P411_SPI0_MOSI_GPT6_A: J3.4, J8.7; also elsewhere on the board
VCC: J4.8; also elsewhere on the board
~RESET: C1.1, J3.5, J4.3, R3.2, S1.3, S1.4; also elsewhere on the board

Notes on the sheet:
RESET PUSHBUTTON
ESP HEADER
I2C PULLUPS NOT MOUNTED
HEADERS


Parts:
C12: 100n; C_0402_1005Metric
C13, C15, C16, C17, C18, C19: 22u; C_0805_2012Metric
C14: 33p; C_0402_1005Metric
C20: 1u; C_0402_1005Metric
C22: 1n; C_0402_1005Metric; not fitted
C23: 100p; C_0402_1005Metric; not fitted
D1, D2: PMEG6020AELRX; D_SOD-123
J5: PJ-102AH; BarrelJack_Kycon_KLDX-0202-xC_Horizontal
L3: 10uH 2.3A; PMF42-103MN
R35, R38, R43, R44: 100k; R_0402_1005Metric
R36, R42: 0; R_0402_1005Metric
R37: 0; R_0402_1005Metric; not fitted
R40: 13.7k; R_0402_1005Metric
R41: 249k; R_0402_1005Metric; not fitted
TP14: TestPoint; TestPoint_Pad_0.8mm
TP15, TP16, TP17: TestPoint; TestPoint_Pad_D0.8mm
U3: ISL854102FRZ-T; DFN-12-1EP_3x4mm_P0.5mm_EP1.7x3.3mm
U5: AP7361C-33E; SOT-223-3_TabPin2

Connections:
+3.3V: TP17.1, U5.3 (VO); also elsewhere on the board
+5V: D2.1 (K), R36.2, TP16.1, U5.1 (VI); also elsewhere on the board
GND: C15.2, C16.2, C17.2, C18.2, C19.2, C20.2, C22.2, C23.2, J5.2, J5.3, R40.2, R43.2, R44.2, U3.6 (PGND), U3.13 (GNDPAD), U5.2 (GND); also elsewhere on the board
ISL_VCC: C20.1, R37.1, R42.2, U3.1 (SS), U3.9 (VCC)
unnamed: C13.1, C19.1
unnamed: C14.1, C15.1, C16.1, C17.1, C18.1, L3.2, R36.1, R38.1
unnamed: C22.1, R41.2
unnamed: C12.1, U3.3 (BOOT)
unnamed: C23.1, R41.1, R42.1, U3.11 (COMP)
unnamed: C14.2, R38.2, R40.1, U3.10 (FB)
unnamed: R43.1, R44.1, U3.12 (FS)
unnamed: C12.2, L3.1, U3.5 (PHASE)
unnamed: R37.2, U3.2 (SYNC)
OFF: R35.2, U3.7 (EN); also elsewhere on the board
VBUS: D2.2 (A); also elsewhere on the board
VCC: D1.2 (A), J5.1, TP14.1; also elsewhere on the board
VDD: C13.2, D1.1 (K), R35.1, TP15.1, U3.4 (VIN)

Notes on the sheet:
SCHOTTKY FOR REVERSE POLARITY PROTECTION
3V3 LINEAR REGULATOR
USB SCHOTTKY
BUCK CONVERTER
DC JACK


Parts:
D01, D02, D03, D4, D5, D6, D7, D8, D9, D10, D11, D12, D13, D14, D15, D16, D17, D18, D19, D20, D21, D22, D23, D24, D25, D26, D27, D28, D29, D30, D31, D32, D33, D34, D35, D36, D37, D38, D39, D40, D41, D42, D43, D44, D45, D46, D47, D48, D49, D50, D51, D52, D53, D54, D55, D56, D57, D58, D59, D60, D61, D62, D63, D64, D65, D66, D67, D68, D69, D70, D71, D72, D73, D74, D75, D76, D77, D78, D79, D80, D81, D82, D83, D84, D85, D86, D87, D88, D89, D90, D91, D92, D93, D94, D95, D96: QBLP601-R5; LED_0603_1608Metric
R2, R14, R16, R27, R28, R29, R30, R31, R32, R33, R34: 330R; R_0402_1005Metric

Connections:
P003: R27.1; also elsewhere on the board
P004: R28.1; also elsewhere on the board
P011: R29.1; also elsewhere on the board
P012: R30.1; also elsewhere on the board
P013: R31.1; also elsewhere on the board
P015: R32.1; also elsewhere on the board
P204: R33.1; also elsewhere on the board
P205: R34.1; also elsewhere on the board
P206: R2.1; also elsewhere on the board
P212: R14.1; also elsewhere on the board
P213: R16.1; also elsewhere on the board
ROW0: D01.2 (A), D02.1 (K), D03.2 (A), D4.1 (K), D7.2 (A), D8.1 (K), D13.2 (A), D14.1 (K), D21.2 (A), D22.1 (K), D31.2 (A), D32.1 (K), D43.2 (A), D44.1 (K), D57.2 (A), D58.1 (K), D73.2 (A), D74.1 (K), D91.2 (A), D92.1 (K), R34.2
ROW1: D01.1 (K), D02.2 (A), D5.2 (A), D6.1 (K), D9.2 (A), D10.1 (K), D15.2 (A), D16.1 (K), D23.2 (A), D24.1 (K), D33.2 (A), D34.1 (K), D45.2 (A), D46.1 (K), D59.2 (A), D60.1 (K), D75.2 (A), D76.1 (K), D93.2 (A), D94.1 (K), R30.2
ROW2: D03.1 (K), D4.2 (A), D5.1 (K), D6.2 (A), D11.2 (A), D12.1 (K), D17.2 (A), D18.1 (K), D25.2 (A), D26.1 (K), D35.2 (A), D36.1 (K), D47.2 (A), D48.1 (K), D61.2 (A), D62.1 (K), D77.2 (A), D78.1 (K), D95.2 (A), D96.1 (K), R31.2
ROW3: D7.1 (K), D8.2 (A), D9.1 (K), D10.2 (A), D11.1 (K), D12.2 (A), D19.2 (A), D20.1 (K), D27.2 (A), D28.1 (K), D37.2 (A), D38.1 (K), D49.2 (A), D50.1 (K), D63.2 (A), D64.1 (K), D79.2 (A), D80.1 (K), R2.2
ROW4: D13.1 (K), D14.2 (A), D15.1 (K), D16.2 (A), D17.1 (K), D18.2 (A), D19.1 (K), D20.2 (A), D29.2 (A), D30.1 (K), D39.2 (A), D40.1 (K), D51.2 (A), D52.1 (K), D65.2 (A), D66.1 (K), D81.2 (A), D82.1 (K), R27.2
ROW5: D21.1 (K), D22.2 (A), D23.1 (K), D24.2 (A), D25.1 (K), D26.2 (A), D27.1 (K), D28.2 (A), D29.1 (K), D30.2 (A), D41.2 (A), D42.1 (K), D53.2 (A), D54.1 (K), D67.2 (A), D68.1 (K), D83.2 (A), D84.1 (K), R33.2
ROW6: D31.1 (K), D32.2 (A), D33.1 (K), D34.2 (A), D35.1 (K), D36.2 (A), D37.1 (K), D38.2 (A), D39.1 (K), D40.2 (A), D41.1 (K), D42.2 (A), D55.2 (A), D56.1 (K), D69.2 (A), D70.1 (K), D85.2 (A), D86.1 (K), R32.2
ROW7: D43.1 (K), D44.2 (A), D45.1 (K), D46.2 (A), D47.1 (K), D48.2 (A), D49.1 (K), D50.2 (A), D51.1 (K), D52.2 (A), D53.1 (K), D54.2 (A), D55.1 (K), D56.2 (A), D71.2 (A), D72.1 (K), D87.2 (A), D88.1 (K), R28.2
ROW8: D57.1 (K), D58.2 (A), D59.1 (K), D60.2 (A), D61.1 (K), D62.2 (A), D63.1 (K), D64.2 (A), D65.1 (K), D66.2 (A), D67.1 (K), D68.2 (A), D69.1 (K), D70.2 (A), D71.1 (K), D72.2 (A), D89.2 (A), D90.1 (K), R29.2
ROW9: D73.1 (K), D74.2 (A), D75.1 (K), D76.2 (A), D77.1 (K), D78.2 (A), D79.1 (K), D80.2 (A), D81.1 (K), D82.2 (A), D83.1 (K), D84.2 (A), D85.1 (K), D86.2 (A), D87.1 (K), D88.2 (A), D89.1 (K), D90.2 (A), R16.2
ROW10: D91.1 (K), D92.2 (A), D93.1 (K), D94.2 (A), D95.1 (K), D96.2 (A), R14.2


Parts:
C2: 4.7u; C_0603_1608Metric
C3, C7, C8, C11, C25, C26, C29, C30: 100n; C_0402_1005Metric
C10, C28: 22u; C_0805_2012Metric
C24: 1u; C_0402_1005Metric

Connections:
+3.3V: C10.1, C11.1, C26.1; also elsewhere on the board
+5V: C2.1, C3.1, C24.1, C25.1, C28.1, C29.1, C30.1; also elsewhere on the board
+BATT: C8.1; also elsewhere on the board
GND: C2.2, C3.2, C7.2, C8.2, C10.2, C11.2, C24.2, C25.2, C26.2, C28.2, C29.2, C30.2; also elsewhere on the board
VREFH0: C7.1; also elsewhere on the board


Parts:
M1: ESP32-S3-MINI-1-N8; XCVR_ESP32-S3-MINI-1-N8
R17, R18: 0; R_0402_1005Metric
R26, R45, R46, R47, R48, R49, R57, R58: 100k; R_0402_1005Metric
R56: 100k; R_0402_1005Metric; not fitted
TP19, TP20, TP21, TP23, TP25, TP26, TP27, TP28, TP29, TP30, TP31, TP32, TP33, TP34, TP35: TestPoint; TestPoint_Pad_D0.8mm
TP22, TP24: TestPoint; TestPoint_Pad_D1.0mm
U4: TXB0108DQSR; USON-20_2x4mm_P0.4mm

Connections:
+3.3V: M1.3 (3V3), R26.1, R49.2, R56.2, R58.1, U4.5 (VCCA); also elsewhere on the board
+5V: U4.16 (VCCB); also elsewhere on the board
ESP32_ENABLE: M1.45 (EN), R26.2, TP21.1, TP22.1
ESP_DOWNLOAD: M1.4 (BOOT_GPIO0), TP23.1, TP24.1; also elsewhere on the board
ESP_IO1: M1.5 (ADC1CH0_GPIO1), TP25.1
ESP_IO4: M1.8 (ADC1CH3_GPIO4), R58.2, TP26.1, U4.1 (A1)
ESP_IO5: M1.9 (ADC1CH4_GPIO5), TP27.1, U4.2 (A2)
ESP_IO6: M1.10 (ADC1CH5_GPIO6), TP28.1, U4.3 (A3)
ESP_IO7: M1.11 (ADC1CH6_GPIO7), TP29.1, U4.4 (A4)
ESP_IO8: M1.12 (ADC1CH7_GPIO8), TP30.1, U4.7 (A5)
ESP_IO9: M1.13 (ADC1CH8_GPIO9), TP31.1, U4.8 (A6)
ESP_IO41: M1.37 (MTDI_GPIO41), TP34.1; also elsewhere on the board
ESP_IO42: M1.38 (MTMS_GPIO42), TP35.1; also elsewhere on the board
ESP_MTCK: M1.35 (MTCK_GPIO39), TP32.1
ESP_MTDO: M1.36 (MTDO_GPIO40), TP33.1
ESP_N: M1.23 (USBDN_ADC2CH8_GPIO19), TP19.1; also elsewhere on the board
ESP_P: M1.24 (USBDP_ADC2CH9_GPIO20), TP20.1; also elsewhere on the board
ESP_RXD0: R18.2, U4.10 (A8); also elsewhere on the board
ESP_TXD0: R17.2, U4.9 (A7); also elsewhere on the board
GND: M1.1 (GND), M1.2 (GND), M1.42 (GND), M1.43 (GND), M1.46 (GND), M1.47 (GND), M1.48 (GND), M1.49 (GND), M1.50 (GND), M1.51 (GND), M1.52 (GND), M1.53 (GND), M1.54 (GND), M1.55 (GND), M1.56 (GND), M1.57 (GND), M1.58 (GND), M1.59 (GND), M1.60 (GND), M1.61 (GND), M1.62 (GND), M1.63 (GND), M1.64 (GND), M1.65 (GND), R57.1, U4.15 (GND); also elsewhere on the board
MD: U4.13 (B6); also elsewhere on the board
unnamed: M1.7 (ADC1CH2_GPIO3), R56.1, R57.2
unnamed: M1.40 (U0RXD/GPIO44), R18.1
unnamed: M1.39 (U0TXD/GPIO43), R17.1
unnamed: R46.1, U4.19 (B2)
unnamed: R45.1, U4.18 (B3)
unnamed: R47.1, U4.12 (B7)
unnamed: R48.1, U4.11 (B8)
unnamed: R49.1, U4.6 (OE)
P108_SWDIO: U4.14 (B5); also elsewhere on the board
P109_SCI9_TXD: R48.2; also elsewhere on the board
P110_SCI9_RXD: R47.2; also elsewhere on the board
P300_SWCLK: U4.17 (B4); also elsewhere on the board
P501_SCI1_TXD: R45.2; also elsewhere on the board
P502_SCI1_RXD: R46.2; also elsewhere on the board
~RESET: U4.20 (B1); also elsewhere on the board

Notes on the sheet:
LEVEL TRANSLATOR

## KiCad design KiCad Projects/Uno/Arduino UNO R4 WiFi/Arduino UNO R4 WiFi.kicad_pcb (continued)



Board: 4 copper layers, 68.6 x 53.3 mm, 262 parts (12 on the bottom side), 121 nets.

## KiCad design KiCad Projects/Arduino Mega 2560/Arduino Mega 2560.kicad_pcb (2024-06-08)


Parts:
C9, C10, C11: 100n; C_0603_1608Metric
C12: 1u; C_0603_1608Metric
C16, C17: 22p; C_0603_1608Metric
D1, D2: YELLOW; LED_0805_2012Metric
D3: CD1206-S01575; D_1206_3216Metric
F1: MF-MSMF050-2; Fuse_1812_4532Metric_Pad1.30x3.40mm_HandSolder
FB1: 1kΩ@100MHz; L_0805_2012Metric
FID1, FID2, FID3, FID4: Fiducial; Fiducial_1mm_Mask3mm
J1: USB_C_Receptacle_USB2.0_16P; USB_C_Receptacle_GCT_USB4105-xx-A_16P_TopMnt_Horizontal
J2: M20-9980345; PinHeader_2x03_P2.54mm_Vertical
J3: M20-9980245; CONN_M20-9980245_HRW
JP1, JP2: SolderJumper_2_Open; SolderJumper-2_P1.3mm_Open_Pad1.0x1.5mm
R2: 1M; R_0603_1608Metric; not fitted
R3, R4: 5k1; R_0603_1608Metric
RN2: 22R; R_Array_Convex_4x0612
RN3, RN4: 1k; R_Array_Convex_4x0612
RN5: 10k; R_Array_Convex_4x0612
RV1, RV2: 5pF@1MHz; R_0603_1608Metric
U4: ATMEGA16U2-MU; VQFN-32-1EP_5x5mm_P0.5mm_EP3.1x3.1mm
Y2: LFXTAL003240BULK; Crystal_HC49-4H_Vertical

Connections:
8PB4: J3.1, U4.18 (PB4)
8PB5: J3.3, U4.19 (PB5)
8PB6: J3.2, U4.20 (PB6)
8PB7: J3.4, U4.21 (PB7)
+5V: C11.1, D3.1 (K), J2.2, RN4.5 (R4.2), RN4.6 (R3.2), RN5.2 (R2.1), U4.4 (VCC), U4.32 (AVCC); also elsewhere on the board
CC1: J1.A5 (CC1), R3.2
CC2: J1.B5 (CC2), R4.2
D+: J1.A6 (D+), J1.B6 (D+), RN2.5 (R4.2), RV2.2
D-: J1.A7 (D-), J1.B7 (D-), RN2.8 (R1.2), RV1.2
DTR: C9.1, RN3.4 (R4.1), U4.13 (PD7)
GND: C10.2, C11.2, C12.2, C16.2, C17.2, FB1.1, J1.A1 (GND), J1.A12 (GND), J1.B1 (GND), J1.B12 (GND), J2.6, JP1.1 (A), JP1.2 (B), R3.1, R4.1, RN3.5 (R4.2), U4.3 (GND), U4.28 (UGND), U4.33 (EXP); also elsewhere on the board
M8RXD: RN4.7 (R2.2), U4.9 (PD3)
M8TXD: RN4.8 (R1.2), U4.8 (PD2)
MISO2: J2.1, U4.17 (PB3)
MOSI2: J2.4, U4.16 (PB2)
unnamed: D1.2 (A), RN4.3 (R3.1)
unnamed: D2.2 (A), RN4.4 (R4.1)
unnamed: C17.1, R2.2, U4.2 (PC0), Y2.1
unnamed: C12.1, U4.27 (UCAP)
unnamed: C16.1, R2.1, U4.1 (XTAL1), Y2.2
PE0: RN4.2 (R2.1); also elsewhere on the board
PE1: RN4.1 (R1.1); also elsewhere on the board
RD+: RN2.4 (R4.1), U4.29 (D+)
RD-: RN2.1 (R1.1), U4.30 (D-)
RESET: C9.2, JP2.1 (A), JP2.2 (B); also elsewhere on the board
RESET2: D3.2 (A), J2.5, RN5.7 (R2.2), U4.24 (PC1//~RESET)
RXL: D2.1 (K), U4.10 (PD4)
SCK2: J2.3, U4.15 (PB1)
TXL: D1.1 (K), U4.11 (PD5)
USBVCC: C10.1, F1.1, U4.31 (UVCC); also elsewhere on the board
USHIELD: FB1.2, J1.S1 (SHIELD), RV1.1, RV2.1
XVCC: F1.2, J1.A4 (VBUS), J1.A9 (VBUS), J1.B4 (VBUS), J1.B9 (VBUS)


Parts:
C1, C2: 47u; CAP_EEHZA1E470P
C4, C6, C7, C13, C14: 100n; C_0603_1608Metric
C15: 1u; C_0603_1608Metric
D4: CGRB307-G; D_SMB
D5: YELLOW; LED_0805_2012Metric
D6: GREEN; LED_0805_2012Metric
J4: PJ-102AH; BarrelJack_Kycon_KLDX-0202-xC_Horizontal
Q1: PMV48XP; SC-59
RN3: 1k; R_Array_Convex_4x0612
RN5: 10k; R_Array_Convex_4x0612
U1: NCP1117-5.0_SOT223; SOT-223-3_TabPin2
U6: LP2985-3.3; SOT-23-5
U7: LMV358IDGKR; MSOP-8_3x3mm_P0.65mm; PARTREV X

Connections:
+3.3V: C15.2, U6.5 (VOUT), U7.6; also elsewhere on the board
+5V: C2.1, C6.1, C7.1, C13.2, Q1.2 (S), RN3.1 (R1.1), U1.2 (VO), U6.1 (VIN), U6.3 (ON/~OFF), U7.8 (VCC+); also elsewhere on the board
CMP: C14.2, RN5.3 (R3.1), RN5.5 (R4.2), U7.5
GATE_CMD: Q1.1 (G), U7.7
GND: C1.2, C2.2, C4.2, C6.2, C7.2, C13.1, C14.1, C15.1, D5.1 (K), D6.1 (K), J4.2, J4.3, RN5.4 (R4.1), U1.1 (GND), U6.2 (GND), U7.4 (GND); also elsewhere on the board
L13: RN3.7 (R2.2), U7.1, U7.2
unnamed: D4.2 (A), J4.1
unnamed: D5.2 (A), RN3.2 (R2.1)
unnamed: D6.2 (A), RN3.8 (R1.2)
PB7: U7.3; also elsewhere on the board
USBVCC: Q1.3 (D); also elsewhere on the board
VCC: C1.1, C4.1, D4.1 (K), RN5.6 (R3.2), U1.3 (VI); also elsewhere on the board


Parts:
C3, C5, C8, C18: 100n; C_0603_1608Metric
D7: CD1206-S01575; D_1206_3216Metric
FB2: 1kΩ@100MHz; L_0805_2012Metric
R1: 1M; R_0603_1608Metric; not fitted
RN5: 10k; R_Array_Convex_4x0612
U3: ATMEGA2560-16AU; TQFP-100_14x14mm_P0.5mm
Y1: CSTNE16M0V530000R0; Resonator_SMD_Murata_CSTxExxV-3Pin_3.0x1.1mm

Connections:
+5V: C8.1, D7.1 (K), FB2.2, RN5.8 (R1.2), U3.10 (VCC), U3.31 (VCC1), U3.61 (VCC2), U3.80 (VCC3); also elsewhere on the board
ADC0: U3.97 ((ADC0)PF0); also elsewhere on the board
ADC1: U3.96 ((ADC1)PF1); also elsewhere on the board
ADC2: U3.95 ((ADC2)PF2); also elsewhere on the board
ADC3: U3.94 ((ADC3)PF3); also elsewhere on the board
ADC4: U3.93 ((ADC4/TCK)PF4); also elsewhere on the board
ADC5: U3.92 ((ADC5/TMS)PF5); also elsewhere on the board
ADC6: U3.91 ((ADC6/TDO)PF6); also elsewhere on the board
ADC7: U3.90 ((ADC7/TDI)PF7); also elsewhere on the board
ADC8: U3.89 (PK0(ADC8/PCINT16)); also elsewhere on the board
ADC9: U3.88 (PK1(ADC9/PCINT17)); also elsewhere on the board
ADC10: U3.87 (PK2(ADC10/PCINT18)); also elsewhere on the board
ADC11: U3.86 (PK3(ADC11/PCINT19)); also elsewhere on the board
ADC12: U3.85 (PK4(ADC12/PCINT20)); also elsewhere on the board
ADC13: U3.84 (PK5(ADC13/PCINT21)); also elsewhere on the board
ADC14: U3.83 (PK6(ADC14/PCINT22)); also elsewhere on the board
ADC15: U3.82 (PK7(ADC15/PCINT23)); also elsewhere on the board
AREF: C5.1, U3.98 (AREF); also elsewhere on the board
AVCC: C18.1, FB2.1, U3.100 (AVCC)
GND: C3.2, C5.2, C8.2, C18.2, U3.11 (GND), U3.32 (GND1), U3.62 (GND2), U3.81 (GND3), U3.99 (AGND), Y1.2; also elsewhere on the board
PA0: U3.78 ((AD0)PA0); also elsewhere on the board
PA1: U3.77 ((AD1)PA1); also elsewhere on the board
PA2: U3.76 ((AD2)PA2); also elsewhere on the board
PA3: U3.75 ((AD3)PA3); also elsewhere on the board
PA4: U3.74 ((AD4)PA4); also elsewhere on the board
PA5: U3.73 ((AD5)PA5); also elsewhere on the board
PA6: U3.72 ((AD6)PA6); also elsewhere on the board
PA7: U3.71 ((AD7)PA7); also elsewhere on the board
PB0: U3.19 ((SS/PCINT0)PB0); also elsewhere on the board
PB1: U3.20 ((SCK/PCINT1)PB1); also elsewhere on the board
PB2: U3.21 ((MOSI/PCINT2)PB2); also elsewhere on the board
PB3: U3.22 ((MISO/PCINT3)PB3); also elsewhere on the board
PB4: U3.23 ((OC2A/PCINT4)PB4); also elsewhere on the board
PB5: U3.24 ((OC1A/PCINT5)PB5); also elsewhere on the board
PB6: U3.25 ((OC1B/PCINT6)PB6); also elsewhere on the board
PB7: U3.26 ((OC0A/OC1C/PCINT7)PB7); also elsewhere on the board
PC0: U3.53 ((A8)PC0); also elsewhere on the board
PC1: U3.54 ((A9)PC1); also elsewhere on the board
PC2: U3.55 ((A10)PC2); also elsewhere on the board
PC3: U3.56 ((A11)PC3); also elsewhere on the board
PC4: U3.57 ((A12)PC4); also elsewhere on the board
PC5: U3.58 ((A13)PC5); also elsewhere on the board
PC6: U3.59 ((A14)PC6); also elsewhere on the board
PC7: U3.60 ((A15)PC7); also elsewhere on the board
PD7: U3.50 ((T0)PD7); also elsewhere on the board
PE0: U3.2 ((RXD0/PCIN8)PE0); also elsewhere on the board
PE1: U3.3 ((TXD0)PE1); also elsewhere on the board
PE3: U3.5 ((OC3A/AIN1)PE3); also elsewhere on the board
PE4: U3.6 ((OC3B/INT4)PE4); also elsewhere on the board
PE5: U3.7 ((OC3C/INT5)PE5); also elsewhere on the board
PG0: U3.51 ((WR)PG0); also elsewhere on the board
PG1: U3.52 ((RD)PG1); also elsewhere on the board
PG2: U3.70 ((ALE)PG2); also elsewhere on the board
PG5: U3.1 ((OC0B)PG5); also elsewhere on the board
PH3: U3.15 (PH3(OC4A)); also elsewhere on the board
PH4: U3.16 (PH4(OC4B)); also elsewhere on the board
PH5: U3.17 (PH5(OC4C)); also elsewhere on the board
PH6: U3.18 (PH6(OC2B)); also elsewhere on the board
PL0: U3.35 (PL0(ICP4)); also elsewhere on the board
PL1: U3.36 (PL1(ICP5)); also elsewhere on the board
PL2: U3.37 (PL2(T5)); also elsewhere on the board
PL3: U3.38 (PL3(OC5A)); also elsewhere on the board
PL4: U3.39 (PL4(OC5B)); also elsewhere on the board
PL5: U3.40 (PL5(OC5C)); also elsewhere on the board
PL6: U3.41 (PL6); also elsewhere on the board
PL7: U3.42 (PL7); also elsewhere on the board
RESET: C3.1, D7.2 (A), RN5.1 (R1.1), U3.30 (RESET); also elsewhere on the board
RXD1: U3.45 ((RXD1/INT2)PD2); also elsewhere on the board
RXD2: U3.12 (PH0(RXD2)); also elsewhere on the board
RXD3: U3.63 (PJ0(RXD3/PCINT9)); also elsewhere on the board
SCL: U3.43 ((SCL/INT0)PD0); also elsewhere on the board
SDA: U3.44 ((SDA/INT1)PD1); also elsewhere on the board
TXD1: U3.46 ((TXD1/INT3)PD3); also elsewhere on the board
TXD2: U3.13 (PH1(TXD2)); also elsewhere on the board
TXD3: U3.64 (PJ1(TXD3/PCINT10)); also elsewhere on the board
XTAL1: R1.1, U3.34 (XTAL1), Y1.3
XTAL2: R1.2, U3.33 (XTAL2), Y1.1


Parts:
J5: PPTC182LFBN-RC
J6: PPTC101LFBN-RC; PinSocket_1x10_P2.54mm_Vertical
J7, J8, J9, J10, J11: PPTC081LFBN-RC; PinSocket_1x08_P2.54mm_Vertical
J12: M20-9980345; PinHeader_2x03_P2.54mm_Vertical
RN1: 10k; R_Array_Convex_4x0612
S1: TS06-667-30-BK-100-G-SMT-TR; SW_TS06-667-30-BK-100-G-SMT-TR; PARTREV 1.0

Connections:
+3.3V: J11.5; also elsewhere on the board
+5V: J5.1, J5.2, J11.4, J11.7, J12.2, RN1.6 (R3.2), RN1.7 (R2.2); also elsewhere on the board
ADC0: J10.8; also elsewhere on the board
ADC1: J10.7; also elsewhere on the board
ADC2: J10.6; also elsewhere on the board
ADC3: J10.5; also elsewhere on the board
ADC4: J10.4; also elsewhere on the board
ADC5: J10.3; also elsewhere on the board
ADC6: J10.2; also elsewhere on the board
ADC7: J10.1; also elsewhere on the board
ADC8: J9.8; also elsewhere on the board
ADC9: J9.7; also elsewhere on the board
ADC10: J9.6; also elsewhere on the board
ADC11: J9.5; also elsewhere on the board
ADC12: J9.4; also elsewhere on the board
ADC13: J9.3; also elsewhere on the board
ADC14: J9.2; also elsewhere on the board
ADC15: J9.1; also elsewhere on the board
AREF: J6.3; also elsewhere on the board
GND: J5.35, J5.36, J6.4, J11.2, J11.3, J12.6, S1.1, S1.2; also elsewhere on the board
PA0: J5.3; also elsewhere on the board
PA1: J5.4; also elsewhere on the board
PA2: J5.5; also elsewhere on the board
PA3: J5.6; also elsewhere on the board
PA4: J5.7; also elsewhere on the board
PA5: J5.8; also elsewhere on the board
PA6: J5.9; also elsewhere on the board
PA7: J5.10; also elsewhere on the board
PB0: J5.34; also elsewhere on the board
PB1: J5.33, J12.3; also elsewhere on the board
PB2: J5.32, J12.4; also elsewhere on the board
PB3: J5.31, J12.1; also elsewhere on the board
PB4: J6.8; also elsewhere on the board
PB5: J6.7; also elsewhere on the board
PB6: J6.6; also elsewhere on the board
PB7: J6.5; also elsewhere on the board
PC0: J5.18; also elsewhere on the board
PC1: J5.17; also elsewhere on the board
PC2: J5.16; also elsewhere on the board
PC3: J5.15; also elsewhere on the board
PC4: J5.14; also elsewhere on the board
PC5: J5.13; also elsewhere on the board
PC6: J5.12; also elsewhere on the board
PC7: J5.11; also elsewhere on the board
PD7: J5.19; also elsewhere on the board
PE0: J7.8; also elsewhere on the board
PE1: J7.7; also elsewhere on the board
PE3: J7.3; also elsewhere on the board
PE4: J7.6; also elsewhere on the board
PE5: J7.5; also elsewhere on the board
PG0: J5.22; also elsewhere on the board
PG1: J5.21; also elsewhere on the board
PG2: J5.20; also elsewhere on the board
PG5: J7.4; also elsewhere on the board
PH3: J7.2; also elsewhere on the board
PH4: J7.1; also elsewhere on the board
PH5: J6.10; also elsewhere on the board
PH6: J6.9; also elsewhere on the board
PL0: J5.30; also elsewhere on the board
PL1: J5.29; also elsewhere on the board
PL2: J5.28; also elsewhere on the board
PL3: J5.27; also elsewhere on the board
PL4: J5.26; also elsewhere on the board
PL5: J5.25; also elsewhere on the board
PL6: J5.24; also elsewhere on the board
PL7: J5.23; also elsewhere on the board
RESET: J11.6, J12.5, S1.3, S1.4; also elsewhere on the board
RXD1: J8.6; also elsewhere on the board
RXD2: J8.4; also elsewhere on the board
RXD3: J8.2; also elsewhere on the board
SCL: J6.1, J8.8, RN1.2 (R2.1); also elsewhere on the board
SDA: J6.2, J8.7, RN1.3 (R3.1); also elsewhere on the board
TXD1: J8.5; also elsewhere on the board
TXD2: J8.3; also elsewhere on the board
TXD3: J8.1; also elsewhere on the board
VCC: J11.1; also elsewhere on the board


Board: 2 copper layers, 101.6 x 53.3 mm, 66 parts (1 on the bottom side), 112 nets.

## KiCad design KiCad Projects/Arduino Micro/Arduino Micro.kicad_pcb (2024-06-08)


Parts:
C1, C2, C6, C9, C10, C11: 100n; C_0402_1005Metric
C3, C14: 22u; C_1210_3225Metric_Pad1.33x2.70mm_HandSolder
C4, C5, C7: 1u; C_0402_1005Metric
C12, C13: 22p; C_0402_1005Metric
D1, D4: YELLOW; LED_0805_2012Metric
D2: CD1206-S01575; D_1206_3216Metric
D3: GREEN; LED_0805_2012Metric
D5: BLUE; LED_0805_2012Metric
F1: MF-MSMF050-2; Fuse_1812_4532Metric_Pad1.30x3.40mm_HandSolder
FB2: MH2029-300Y; L_0805_2012Metric
FID1, FID2: Fiducial; Fiducial_1mm_Mask2mm
J3: USB_C_Receptacle_USB2.0_16P; USB_C_Receptacle_GCT_USB4110
J4: M20-9980345; PinHeader_2x03_P2.54mm_Vertical
J5, J6: PH1-17-UA; PinHeader_1x17_P2.54mm_Vertical
Q1, Q2: FDN340P; SC-59
R1, R2, R4, R9: 10k; R_0402_1005Metric
R3, R10: 5.1k; R_0402_1005Metric
R5, R6, R7, R8: 1k; R_0402_1005Metric
RN1: 22R; R_Array_Convex_4x0612
RV1, RV2: CG0603MLC-05E; R_0603_1608Metric
S1: TS06-667-30-BK-100-G-SMT-TR; SW_TS06-667-30-BK-100-G-SMT-TR; PARTREV 1.0
TP1, TP2: TestPoint; TestPoint_Pad_D1.0mm
U1: ATMEGA32U4-XUMU; TQFN-44-1EP_7x7mm_P0.5mm_EP4.7x4.7mm
U2: NCP1117-5.0_SOT223; SOT-223-3_TabPin2
U4: LP2985-3.3; SOT-23-5
Y3: ECS-160-18-33-JGN-TR; Crystal_SMD_SeikoEpson_FA238-4Pin_3.2x2.5mm

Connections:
+3V3: C4.1, J6.16, U4.5 (VOUT)
+5V: C2.1, C3.1, C10.1, C11.1, D2.1 (K), FB2.1, J4.2, J6.6, Q1.2 (S), Q2.1 (G), R1.1, R5.1, U1.2 (UVCC), U1.14 (VCC), U1.24 (AVCC), U1.34 (VCC1), U2.2 (VO), U4.1 (VIN), U4.3 (ON/~OFF)
A0: J6.14, U1.36 ((ADC7/TDI)PF7)
A1: J6.13, U1.37 ((ADC6/TDO)PF6)
A2: J6.12, U1.38 ((ADC5/TMS)PF5)
A3: J6.11, U1.39 ((ADC4/TCK)PF4)
A4: J6.10, U1.40 ((ADC1)PF1)
A5: J6.9, U1.41 ((ADC0)PF0)
AREF: C6.1, J6.15, U1.42 (AREF)
AVCC: C7.1, FB2.2, U1.44 (AVCC1)
D0/RX: J5.4, U1.20 ((RXD1/AIN1/INT2)PD2)
D1/TX: J5.3, U1.21 ((TXD1/INT3)PD3)
D2/SDA: J5.7, U1.19 ((SDA/INT1)PD1)
D3/SCL: J5.8, U1.18 ((OC0B/SCL/INT0)PD0)
D4*: J5.9, U1.25 ((ICP1/ADC8)PD4)
D5*: J5.10, U1.31 ((OC3A/#0C4A)PC6)
D6*: J5.11, U1.27 ((T0/OC4D/ADC10)PD7)
D7: J5.12, U1.1 ((INT6/AIN0)PE6)
GND: C1.2, C2.2, C3.2, C4.2, C5.2, C6.2, C7.2, C9.2, C10.2, C11.2, C12.1, C13.1, C14.2, D1.1 (K), D3.1 (K), D4.1 (K), D5.1 (K), J3.A1 (GND), J3.A12 (GND), J3.B1 (GND), J3.B12 (GND), J3.S1 (SHIELD), J4.6, J5.6, J6.4, R2.1, R3.2, R4.2, R9.1, R10.2, RN1.3 (R3.1), RN1.4 (R4.1), RN1.5 (R4.2), RN1.6 (R3.2), RV1.2, RV2.2, S1.3, S1.4, S1.5, U1.5 (UGND), U1.15 (GND), U1.23 (GND1), U1.35 (GND2), U1.43 (GND3), U1.45 (PAD), U2.1 (GND), U4.2 (GND), Y3.2, Y3.4
HWB: R4.1, U1.33 ((#HWB)PE2)
IO8: J5.13, U1.28 ((ADC11/PCINT4)PB4)
IO9*: J5.14, U1.29 ((PCINT5/OC1A/#OC4B/ADC12)PB5)
IO10*: J5.15, U1.30 ((PCINT6/OC1B/OC4B/ADC13)PB6)
IO11*: J5.16, U1.12 ((PCINT7/OC0A/OC1C/#RTS)PB7)
IO12*: J5.17, U1.26 ((T1/#OC4D/ADC9)PD6)
IO13*: J6.17, R8.1, U1.32 ((ICP3/CLK0/OC4A)PC7)
MISO: J4.1, J6.2, U1.11 ((PD0/MISO/PCINT3)PB3)
MOSI: J4.4, J5.1, U1.10 ((PDI/MOSI/PCINT2)PB2)
unnamed: C14.1, F1.1, J3.A4 (VBUS), J3.A9 (VBUS), J3.B4 (VBUS), J3.B9 (VBUS)
unnamed: D1.2 (A), R7.2
unnamed: D3.2 (A), R8.2
unnamed: D4.2 (A), R6.2
unnamed: D5.2 (A), R5.2
unnamed: J3.A5 (CC1), R3.1
unnamed: J3.B5 (CC2), R10.1
unnamed: C1.1, Q2.2 (S), U2.3 (VI)
unnamed: J3.A6 (D+), J3.B6 (D+), RN1.8 (R1.2), RV1.1, TP2.1
unnamed: J3.A7 (D-), J3.B7 (D-), RN1.7 (R2.2), RV2.1, TP1.1
RD+: RN1.1 (R1.1), U1.4 (D+)
RD-: RN1.2 (R2.1), U1.3 (D-)
RESET: D2.2 (A), J4.5, J5.5, J6.5, R1.2, S1.1, S1.2, U1.13 (RESET)
RXLED/SS: J5.2, R7.1, U1.8 ((SS/PCINT0)PB0)
SCK: J4.3, J6.1, U1.9 ((SCLK/PCINT1)PB1)
TXLED: R6.1, U1.22 ((XCK1/#CTS)PD5)
UCAP: C5.1, U1.6 (UCAP)
VBUS: C9.1, F1.2, Q1.3 (D), R2.2, U1.7 (VBUS)
VCC: J6.3, Q1.1 (G), Q2.3 (D), R9.2
XTAL1: C13.2, U1.17 (XTAL1), Y3.3
XTAL2: C12.2, U1.16 (XTAL2), Y3.1

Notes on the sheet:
ICSP
+3V3 REG
+5V REG
NOT USED
USB
+5V SELECTOR (USB)

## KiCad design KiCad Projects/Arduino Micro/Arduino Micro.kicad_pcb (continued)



Board: 4 copper layers, 48.3 x 17.8 mm, 48 parts (26 on the bottom side), 49 nets.

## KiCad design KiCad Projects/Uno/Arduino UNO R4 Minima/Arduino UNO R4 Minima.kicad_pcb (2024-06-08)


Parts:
C1, C3: 15p; C_0402_1005Metric; not fitted
C4, C7, C11: 4.7u; C_0603_1608Metric
C5, C6, C8, C10: 100n; C_0402_1005Metric
C9: 1u; C_0402_1005Metric
C21: 4.7n; C_0805_2012Metric
D4: PRTR5V0U2X,215; SOT-143
DL1, DL2, DL4: NTE30007; LED_0603_1608Metric
DL3: HSMG-C190; LED_0603_1608Metric
FID1, FID2: Fiducial; Fiducial_1mm_Mask2mm
J3: USB_C_Receptacle_USB2.0_16P; USB_C_Receptacle_GCT_USB4105-xx-A_16P_TopMnt_Horizontal
L1, L2: BLM18PG471SN1D; L_0603_1608Metric
R4: 5.1k; R_0402_1005Metric; not fitted
R5, R6, R7, R8, R9, R24, R25: 5.1k; R_0402_1005Metric
R10: 100k; R_0402_1005Metric
R14, R15, R16, R17: 330R; R_0402_1005Metric
R23: 1M; R_0402_1005Metric
R26: 13.7k; R_0402_1005Metric
TP4, TP5, TP6, TP7, TP8, TP9, TP10, TP11, TP14: TestPoint; TestPoint_Pad_D1.0mm
TP12: TestPoint; TestPoint_P204
U1: R7FA4M1AB3CFM#AA0; LQFP-64_10x10mm_P0.5mm
Y1: ECS-160-18-33-JGN-TR; Crystal_SMD_SeikoEpson_FA238-4Pin_3.2x2.5mm; not fitted

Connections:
+3.3V: C7.1, C10.1, U1.4 (VBATT), U1.20 (VCC_USB); also elsewhere on the board
+5V: C4.1, C5.1, C6.1, DL1.2 (A), DL2.2 (A), DL3.2 (A), L2.2, R4.1, R5.1, R6.1, R7.1, R10.1, TP10.1, U1.11 (VCC), U1.21 (VCC_USB_LDO), U1.39 (VCC); also elsewhere on the board
AREF: L1.1, R4.2; also elsewhere on the board
GND: C1.1, C3.1, C4.2, C5.2, C6.2, C7.2, C8.2, C9.2, C10.2, C11.1, C21.2, J3.A1 (GND), J3.A12 (GND), J3.B1 (GND), J3.B12 (GND), R9.2, R16.2, R17.2, R23.2, R24.2, R25.2, R26.2, TP7.1, U1.8 (VSS), U1.17 (VSS_USB), U1.40 (VSS), U1.57 (AVSS0); also elsewhere on the board
MD: R6.2, TP11.1, U1.26 (MD/P201); also elsewhere on the board
unnamed: DL1.1 (K), R14.1
unnamed: DL2.1 (K), R15.1
unnamed: DL3.1 (K), R16.1
unnamed: DL4.1 (K), R17.1
unnamed: J3.A5 (CC1), R25.1
unnamed: J3.B5 (CC2), R24.1
unnamed: R8.2, R9.1
unnamed: C8.1, L2.1, U1.56 (AVCC0)
unnamed: R10.2, R26.1, U1.49 (GTIOC2A/AN016/P500)
unnamed: R5.2, U1.27 (NMI/INPUT_ONLY_P200)
unnamed: C3.2, U1.10 (P212/GTIOC0B/EXTAL), Y1.1
unnamed: C1.2, U1.9 (P213/GTIOC0A/XTAL), Y1.3
unnamed: R7.2, R8.1, U1.16 (P407/USB_VBUS/ADTRG0)
unnamed: C11.2, U1.5 (VCL)
P000_AN00_AMP+: U1.64 (AN000/P000); also elsewhere on the board
P001_AN01_AMP-: U1.63 (AN001/P001); also elsewhere on the board
P002_AN02_AMPO: U1.62 (AN002/P002); also elsewhere on the board
P012: R14.2, U1.55 (VREFH/AN007/P012)
P013: R15.2, U1.54 (VREFL/AN008/P013)
P014_AN09_DAC: U1.53 (DA0/AN009/P014); also elsewhere on the board
P100_AN22_SCL: U1.48 (GTIOC5B/AN022/P100); also elsewhere on the board
P101_AN21_SDA: U1.47 (GTIOC5A/AN021/P101); also elsewhere on the board
P102_SPI0_RSPCK_GPT2_B_CAN0_RX: U1.46 (ADTRG0/GTIOC2B/AN020/P102); also elsewhere on the board
P103_SPI0_SSL_GPT2_A_CAN0_TX: U1.45 (GTIOC2A/AN019/P103); also elsewhere on the board
P104_IRQ01_GPT1_B: U1.44 (GTIOC1B/P104); also elsewhere on the board
P105_IRQ00_GPT1_A: U1.43 (GTIOC1A/P105); also elsewhere on the board
P106_GPT0_B: U1.42 (GTIOC0B/P106); also elsewhere on the board
P107_GPT0_A: U1.41 (GTIOC0A/P107); also elsewhere on the board
P108_SWDIO: TP8.1, U1.33 (P108/GTIOC0B/TMS/SWDIO); also elsewhere on the board
P109_SCI9_TXD: U1.34 (CTX0/TDO/SWO/GTIOC1A/P109); also elsewhere on the board
P110_SCI9_RXD: U1.35 (CRX0/TDI/GTIOC1B/P110); also elsewhere on the board
P111_GPT3_A: DL4.2 (A), U1.36 (GTIOC3A/P111); also elsewhere on the board
P112_GPT3_B: U1.37 (GTIOC3B/P112); also elsewhere on the board
P204: TP12.1, U1.24 (GTIOC4B/P204)
P300_SWCLK: TP9.1, U1.32 (P300/GTIOC0A/TCK/SWCLK); also elsewhere on the board
P301_SCI2_RXD: U1.31 (GTIOC4B/P301); also elsewhere on the board
P302_SCI2_TXD: U1.30 (GTIOC4A/P302); also elsewhere on the board
P303_GPT7_B: U1.29 (GTIOC7B/P303); also elsewhere on the board
P304_GPT7_A: U1.28 (GTIOC7A/P304); also elsewhere on the board
P501_SCI1_TXD: U1.50 (GTIOC2B/AN017/P501); also elsewhere on the board
P502_SCI1_RXD: U1.51 (GTIOC3B/AN018/P502); also elsewhere on the board
SHIELD: C21.1, D4.1, J3.S1 (SHIELD), R23.1
USB_D_N: D4.2, J3.A7 (D-), J3.B7 (D-), TP5.1, U1.18 (P915/USB_DM)
USB_D_P: D4.3, J3.A6 (D+), J3.B6 (D+), TP6.1, U1.19 (P914/USB_DP)
VBUS: D4.4, J3.A4 (VBUS), J3.A9 (VBUS), J3.B4 (VBUS), J3.B9 (VBUS), TP4.1; also elsewhere on the board
VREFH0: C9.1, L1.2, U1.59 (P010/AN005/VREFH0)
~RESET: U1.25 (~RES); also elsewhere on the board

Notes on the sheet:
RX LED
SCK LED
ESD PROTECTION
TX LED
YELLOW
MICROCONTROLLER
USB CONNECTOR
GREEN
POWER LED


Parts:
C12: 100n; C_0402_1005Metric
C13, C15, C16, C17, C18, C19: 22u; C_0805_2012Metric
C14: 33p; C_0402_1005Metric
C20: 1u; C_0402_1005Metric
C22: 1n; C_0402_1005Metric; not fitted
C23: 100p; C_0402_1005Metric; not fitted
D2, D3: PMEG6020AELRX; D_SOD-123
J4: PJ-102AH; BarrelJack_Kycon_KLDX-0202-xC_Horizontal
L3: 10uH 2.3A; PMF42-103MN
R11, R20: 0; R_0402_1005Metric
R12: 0; R_0402_1005Metric; not fitted
R13, R21, R22: 100k; R_0402_1005Metric
R18: 13.7k; R_0402_1005Metric
R19: 249k; R_0402_1005Metric; not fitted
TP1, TP2, TP3: TestPoint; TestPoint_Pad_D0.8mm
U2: ISL854102FRZ-T; DFN-12-1EP_3x4mm_P0.5mm_EP1.7x3.3mm

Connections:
+5V: D3.1 (K), R11.2, TP1.1; also elsewhere on the board
GND: C15.2, C16.2, C17.2, C18.2, C19.2, C20.2, C22.2, C23.2, J4.2, J4.3, R18.2, R21.2, R22.2, U2.6 (PGND), U2.13 (GNDPAD); also elsewhere on the board
unnamed: C13.1, C19.1
unnamed: C14.1, C15.1, C16.1, C17.1, C18.1, L3.2, R11.1, R13.1
unnamed: C22.1, R19.2
unnamed: C13.2, D2.1 (K), TP2.1, U2.4 (VIN), U2.7 (EN)
unnamed: C12.1, U2.3 (BOOT)
unnamed: C23.1, R19.1, R20.1, U2.11 (COMP)
unnamed: C14.2, R13.2, R18.1, U2.10 (FB)
unnamed: R21.1, R22.1, U2.12 (FS)
unnamed: C12.2, L3.1, U2.5 (PHASE)
unnamed: C20.1, R12.1, R20.2, U2.1 (SS), U2.9 (VCC)
unnamed: R12.2, U2.2 (SYNC)
VBUS: D3.2 (A); also elsewhere on the board
VCC: D2.2 (A), J4.1, TP3.1; also elsewhere on the board

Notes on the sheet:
SCHOTTKY FOR REVERSE POLARITY PROTECTION
BUCK CONVERTER
DC JACK
SCHOTTKY FOR USB OVERVOLTAGE PROTECTION


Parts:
C2: DNP; C_0402_1005Metric; not fitted
J1: M20-9980345; PinHeader_2x03_P2.54mm_Vertical
J2, J6: PPTC081LFBN-RC; PinSocket_1x08_P2.54mm_Vertical
J5: PPTC061LFBN-RC; PinSocket_1x06_P2.54mm_Vertical
J7: PPTC101LFBN-RC; PinSocket_1x10_P2.54mm_Vertical
J8: M52-040023W0545; PinHeader_2x05_P1.27mm_Vertical
R1, R2: 5.1k; R_0603_1608Metric; not fitted
R3: 5.1k; R_0402_1005Metric
S1: TS06-667-30-BK-100-G-SMT-TR; SW_TS06-667-30-BK-100-G-SMT-TR; PARTREV 1.0
TP13: TestPoint; TestPoint_Pad_D1.0mm

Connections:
+3.3V: J2.4; also elsewhere on the board
+5V: J1.2, J2.2, J2.5, J8.1, R1.1, R2.1, R3.1; also elsewhere on the board
AREF: J7.3; also elsewhere on the board
GND: C2.2, J1.6, J2.6, J2.7, J7.4, J8.3, J8.5, J8.9, S1.1, S1.2, S1.5, TP13.1; also elsewhere on the board
MD: J2.1; also elsewhere on the board
P000_AN00_AMP+: J5.2; also elsewhere on the board
P001_AN01_AMP-: J5.3; also elsewhere on the board
P002_AN02_AMPO: J5.4; also elsewhere on the board
P014_AN09_DAC: J5.1; also elsewhere on the board
P100_AN22_SCL: J5.6, J7.1, R1.2; also elsewhere on the board
P101_AN21_SDA: J5.5, J7.2, R2.2; also elsewhere on the board
P102_SPI0_RSPCK_GPT2_B_CAN0_RX: J6.3; also elsewhere on the board
P103_SPI0_SSL_GPT2_A_CAN0_TX: J6.4; also elsewhere on the board
P104_IRQ01_GPT1_B: J6.5; also elsewhere on the board
P105_IRQ00_GPT1_A: J6.6; also elsewhere on the board
P106_GPT0_B: J6.2; also elsewhere on the board
P107_GPT0_A: J6.1; also elsewhere on the board
P108_SWDIO: J8.2; also elsewhere on the board
P109_SCI9_TXD: J1.4, J7.7; also elsewhere on the board
P110_SCI9_RXD: J1.1, J7.6; also elsewhere on the board
P111_GPT3_A: J1.3, J7.5; also elsewhere on the board
P112_GPT3_B: J7.8; also elsewhere on the board
P300_SWCLK: J8.4; also elsewhere on the board
P301_SCI2_RXD: J6.8; also elsewhere on the board
P302_SCI2_TXD: J6.7; also elsewhere on the board
P303_GPT7_B: J7.9; also elsewhere on the board
P304_GPT7_A: J7.10; also elsewhere on the board
P501_SCI1_TXD: J8.8; also elsewhere on the board
P502_SCI1_RXD: J8.7; also elsewhere on the board
VCC: J2.8; also elsewhere on the board
~RESET: C2.1, J1.5, J2.3, J8.10, R3.2, S1.3, S1.4; also elsewhere on the board

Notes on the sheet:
RESET PUSHBUTTON
SWD CONNECTOR
HEADERS
I2C PULLUPS NOT MOUNTED



Board: 2 copper layers, 68.6 x 53.3 mm, 87 parts (11 on the bottom side), 64 nets.

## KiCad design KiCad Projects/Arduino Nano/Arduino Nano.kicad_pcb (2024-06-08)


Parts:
C1, C4, C6, C9: 100n; C_0603_1608Metric
C2, C5: 4.7u; CP_EIA-3216-10_Kemet-I
C3, C7, C8: 1u; C_0603_1608Metric
D1: SS1P3L-M3/84A; D_SMP_DO-220AA
D2, D4: GREEN; LED_0805_2012Metric
D3: RED; LED_0805_2012Metric
D5: YELLOW; LED_0805_2012Metric
F1: PTC; Fuse_0603_1608Metric
FID1, FID2, FID3, FID4: Fiducial; Fiducial_1mm_Mask2mm
J1, J2: PH1-15-UA; PinHeader_1x15_P2.54mm_Vertical
J3: USB_C_Receptacle_USB2.0_16P; USB_C_Receptacle_GCT_USB4110
J4: M20-9980345; PinHeader_2x03_P2.54mm_Vertical
R1, R2: 5.1k; R_0603_1608Metric
RN1, RN2: 1k; R_Array_Convex_4x0612
SW1: B3U-1000PM
TP1, TP2: TestPoint; TestPoint_Pad_D1.0mm
U1: FT232RL; SSOP-28_5.3x10.2mm_P0.65mm
U2: NCP1117-5.0_SOT223; SOT-223-3_TabPin2
U3: ATMEGA328P-MU; VQFN-32-1EP_5x5mm_P0.5mm_EP3.1x3.1mm
Y1: CSTNE16M0V530000R0; Resonator_SMD_Murata_CSTxExxV-3Pin_3.0x1.1mm

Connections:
+3V3: C6.2, J2.14, U1.17 (3V3OUT)
+5V: C3.1, C5.1, C7.1, C8.1, D1.1 (K), D2.2 (A), D3.2 (A), J2.4, J4.2, RN1.5 (R4.2), RN1.6 (R3.2), U1.4 (VCCIO), U1.20 (VCC), U2.2 (VO), U3.4 (VCC), U3.6 (VCC__1), U3.18 (AVCC)
A0: J2.12, U3.23 (PC0)
A1: J2.11, U3.24 (PC1)
A2: J2.10, U3.25 (PC2)
A3: J2.9, U3.26 (PC3)
A4: J2.8, U3.27 (PC4)
A5: J2.7, U3.28 (PC5)
A6: J2.6, U3.19 (ADC6)
A7: J2.5, U3.22 (ADC7)
AREF: C1.1, J2.13, U3.20 (AREF)
CC1: J3.A5 (CC1), R1.1
CC2: J3.B5 (CC2), R2.1
D0/RX: J1.2, RN1.1 (R1.1), U3.30 (PD0)
D1/TX: J1.1, RN1.2 (R2.1), U3.31 (PD1)
D2: J1.5, U3.32 (PD2)
D3: J1.6, U3.1 (PD3)
D4: J1.7, U3.2 (PD4)
D5: J1.8, U3.9 (PD5)
D6: J1.9, U3.10 (PD6)
D7: J1.10, U3.11 (PD7)
D8: J1.11, U3.12 (PB0)
D9: J1.12, U3.13 (PB1)
D10: J1.13, U3.14 (PB2)
D11/MOSI: J1.14, J4.4, U3.15 (PB3)
D12/MISO: J1.15, J4.1, U3.16 (PB4)
D13/SCK: J2.15, J4.3, RN2.1 (R1.1), U3.17 (PB5)
GND: C1.2, C2.2, C3.2, C5.2, C6.1, C7.2, C8.2, C9.2, D4.1 (K), D5.1 (K), J1.4, J2.2, J3.A1 (GND), J3.A12 (GND), J3.B1 (GND), J3.B12 (GND), J3.S1 (SHIELD), J4.6, R1.2, R2.2, RN2.3 (R3.1), RN2.6 (R3.2), SW1.1, U1.7 (GND), U1.18 (GND), U1.21 (GND), U1.25 (AGND), U1.26 (TEST), U2.1 (GND), U3.3 (GND), U3.5 (GND__1), U3.21 (GND__2), U3.33 (EXP), Y1.2
unnamed: D2.1 (K), RN2.5 (R4.2)
unnamed: D3.1 (K), RN2.7 (R2.2)
unnamed: D4.2 (A), RN1.3 (R3.1)
unnamed: D5.2 (A), RN2.8 (R1.2)
unnamed: F1.2, J3.A4 (VBUS), J3.A9 (VBUS), J3.B4 (VBUS), J3.B9 (VBUS)
unnamed: RN2.2 (R2.1), U1.23 (CBUS0)
unnamed: RN2.4 (R4.1), U1.22 (CBUS1)
unnamed: C4.2, U1.2 (DTR#)
unnamed: J3.A7 (D-), J3.B7 (D-), TP1.1, U1.16 (USBDM)
unnamed: J3.A6 (D+), J3.B6 (D+), TP2.1, U1.15 (USBDP)
unnamed: U3.7 (PB6), Y1.1
unnamed: U3.8 (PB7), Y1.3
RESET: C4.1, J1.3, J2.3, J4.5, RN1.4 (R4.1), SW1.2, U3.29 (PC6/~RESET)
RX: RN1.8 (R1.2), U1.1 (TXD)
TX: RN1.7 (R2.2), U1.5 (RXD)
VBUS: C2.1, C9.1, D1.2 (A), F1.1
VCC: J2.1, U2.3 (VI)

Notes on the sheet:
ICSP
USB
+5V AUTO SELECTOR
+5V REG



Board: 2 copper layers, 43.2 x 17.8 mm, 34 parts (21 on the bottom side), 45 nets.

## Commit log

2024-06-08 Initial Commit
    First commit containing KiCad projects and boardview files for the 8 boards.
    [ATMEGA2560-16AU.kicad_sch, ATMEGA328P-MU.kicad_sch, ATMEGA328P-PU.kicad_sch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]
2024-09-29 Added BOMs, updated READMEs
    Updated the READMEs for the Uno R4 Minima, Micro, and Nano to reflect that the boards have been confirmed to work in real life. Also added a README for the boardview files folder.
